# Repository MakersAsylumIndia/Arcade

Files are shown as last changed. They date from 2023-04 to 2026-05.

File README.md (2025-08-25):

# Arcade
A mini Arcade designed around two custom PCBs - the main board has the Arduino Nano, 128x64 I2C OLED display, and socket headers for digital, analog and PWM GPIO's. 

- The /enclosure folder has 3D FreeCAD model files.
- The /hardware_PCB folders contain schematic, PCB and related files.
- The /code folder has the Arduino code sketches.

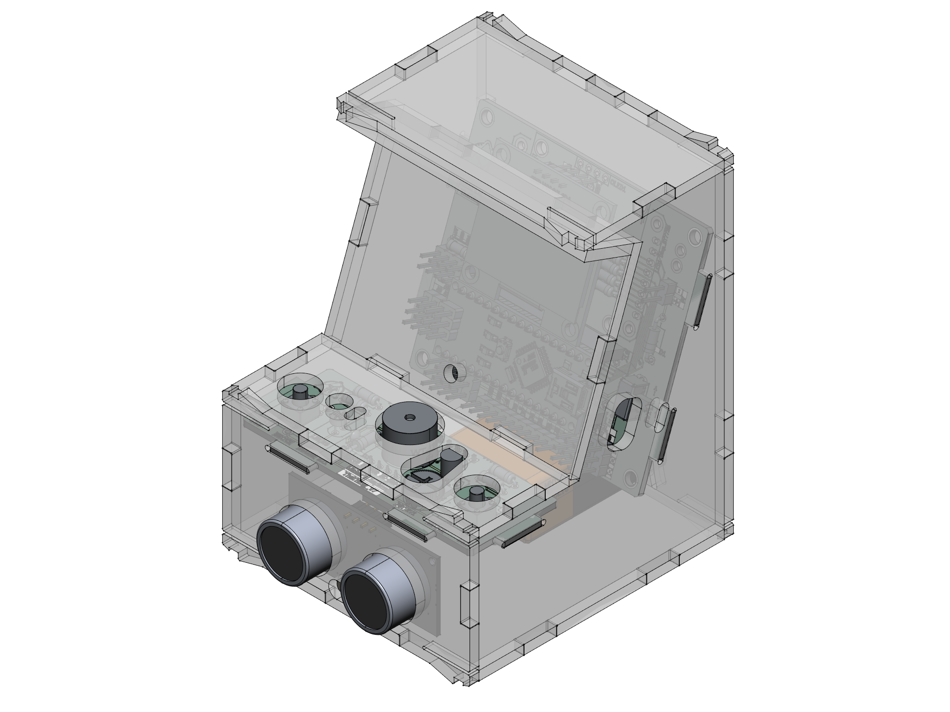
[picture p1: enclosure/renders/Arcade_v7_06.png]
Arcade_01

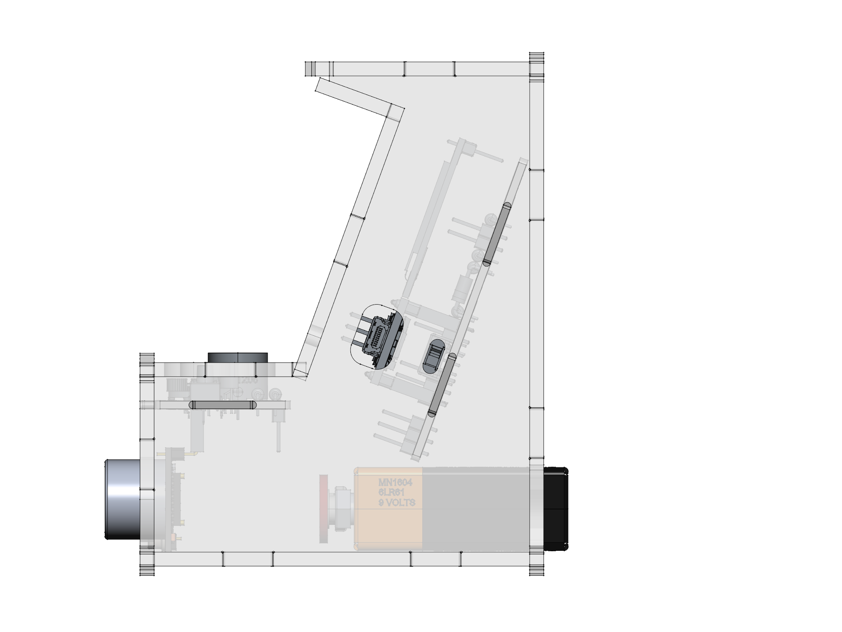
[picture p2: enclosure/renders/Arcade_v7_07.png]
Arcade_02

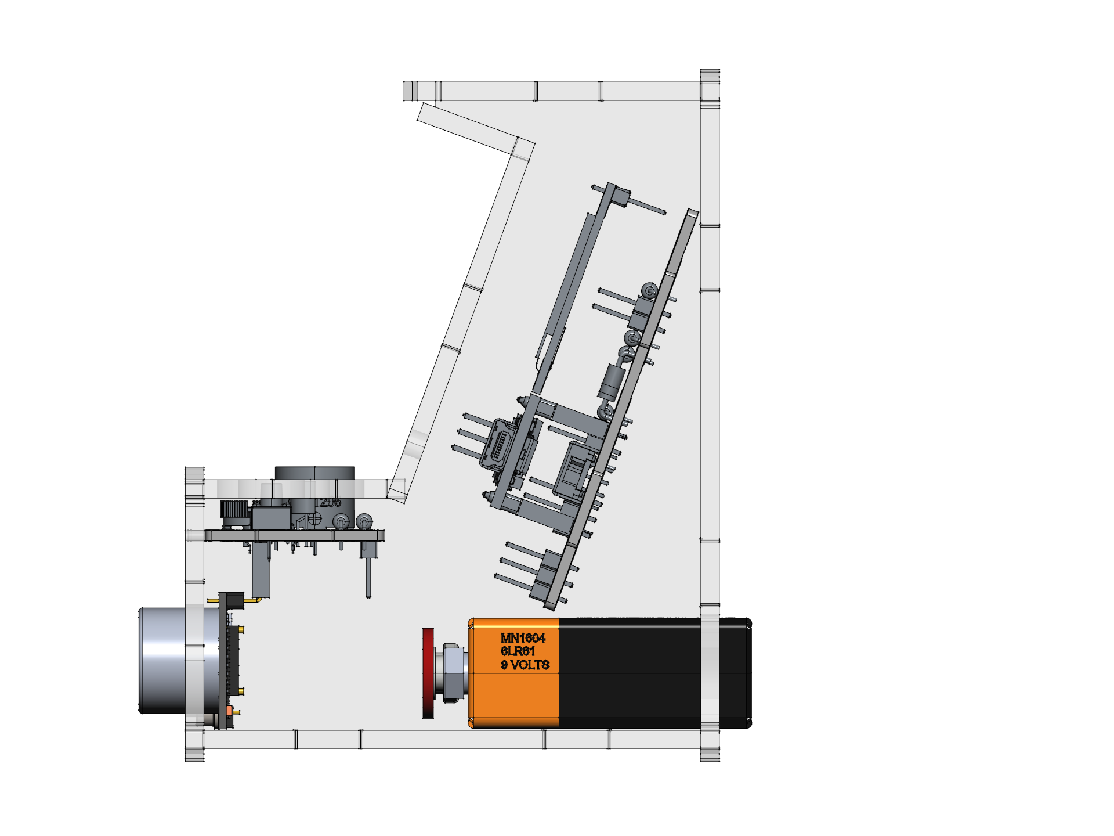
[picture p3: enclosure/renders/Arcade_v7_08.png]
Arcade_03


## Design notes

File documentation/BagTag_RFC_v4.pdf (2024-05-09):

# “Bag Tag” v4 Electronics

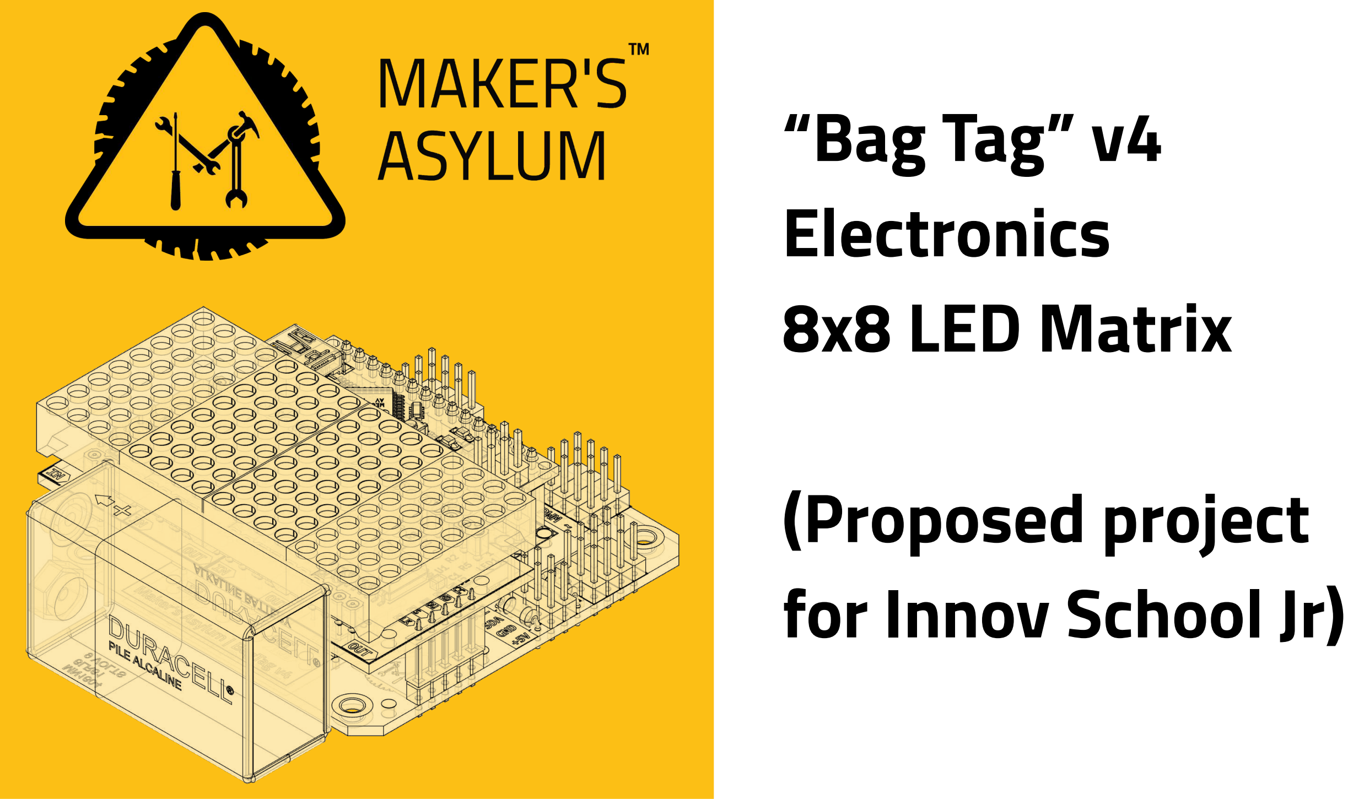
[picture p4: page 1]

# 8x8 LED Matrix

# (Proposed project for Innov School Jr)

# Requirements

- Complexity level - SIMPLE
- Must include elements of
- Electronics (soldering)
- Arduino (programming)
- Rapid prototyping (3DP/laser)
- BADGE form factor
- Powered by 9V battery
- Expandable / Hackable

Changes in v4 (v/s v1, v2 & v3)

- All parts on FRONT, but battery on side
- Two I²C expansion headers
- Can install one or two 8x8 SINGLE color LED

display based on MAX7219 chip

- Parts aligned along vertical axis for balance
- 3 expansion headers, each with 4 of Digital,

PWM & Analog I/’s with +5V and GND

- Larger PCB size

# Schematic

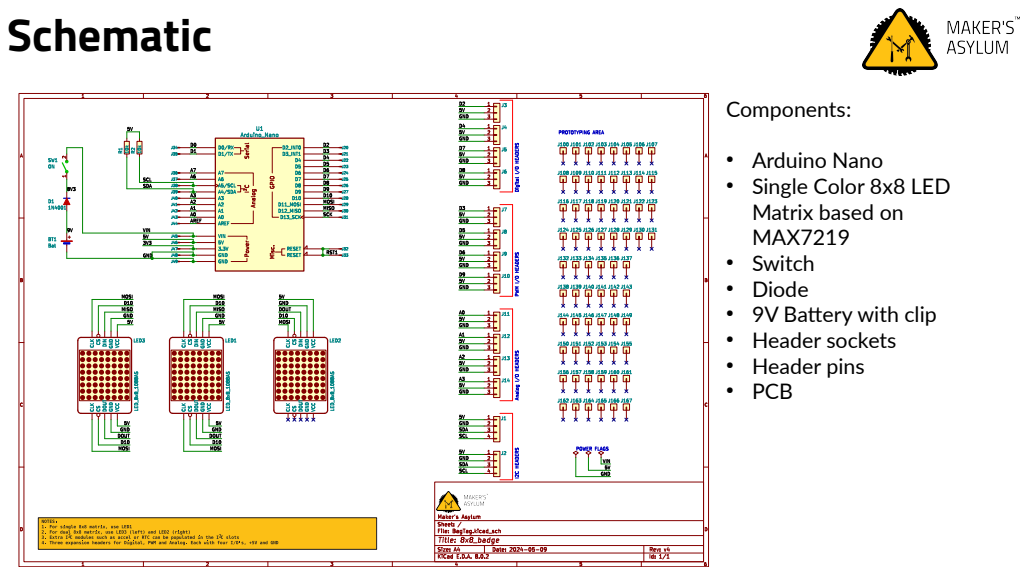
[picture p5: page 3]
Components: ●; Arduino Nano ●; Single Color 8x8 LED; Switch ●; Diode ●; 9V Battery with clip ●; Header sockets ●; Header pins ●; PCB

Matrix based on
MAX7219

# Options

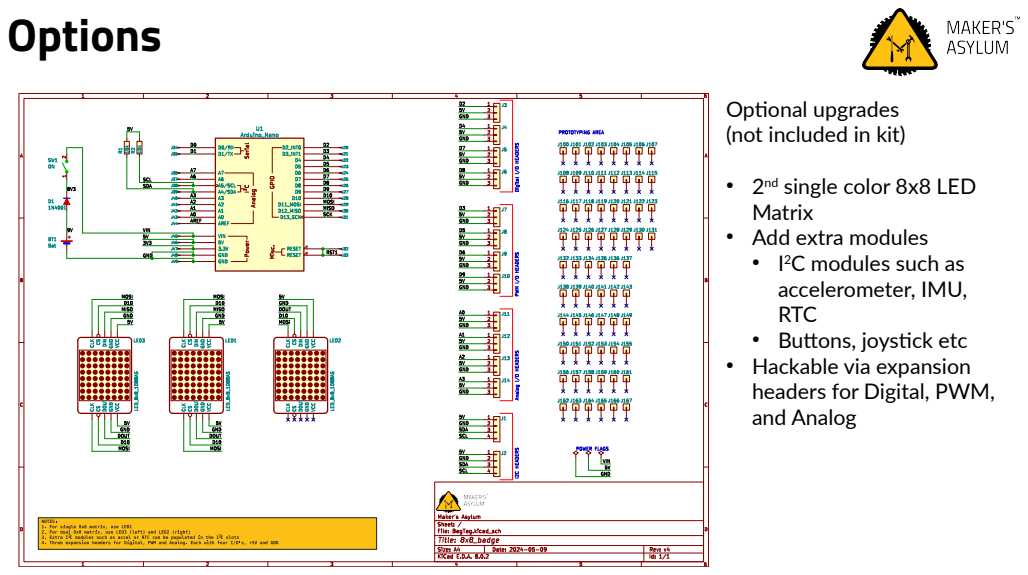
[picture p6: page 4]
Optional upgrades; (not included in kit) ●; Add extra modules ●; I²C modules such as

nd single color 8x8 LED
Matrix

accelerometer, IMU,
RTC
● Buttons, joystick etc
● Hackable via expansion
headers for Digital, PWM,
and Analog

# PCB Render

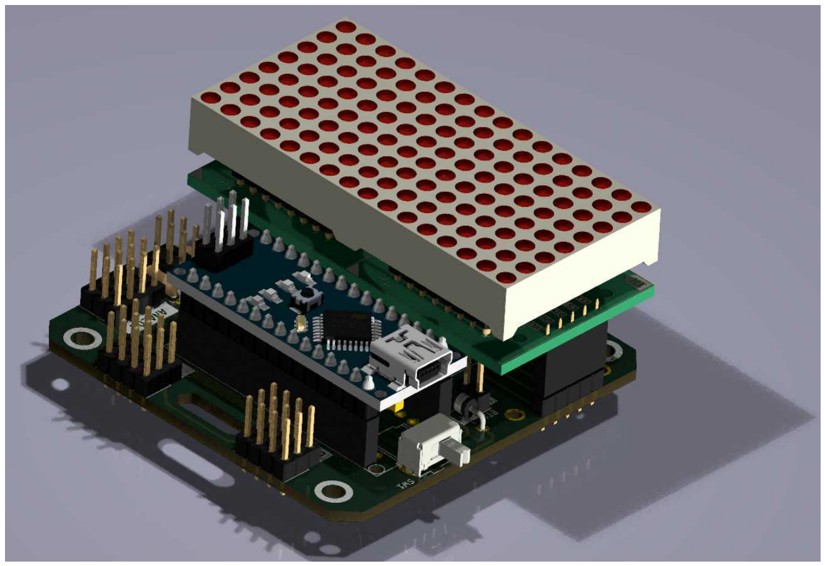
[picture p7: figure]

# PCB Front view

Lanyard slot

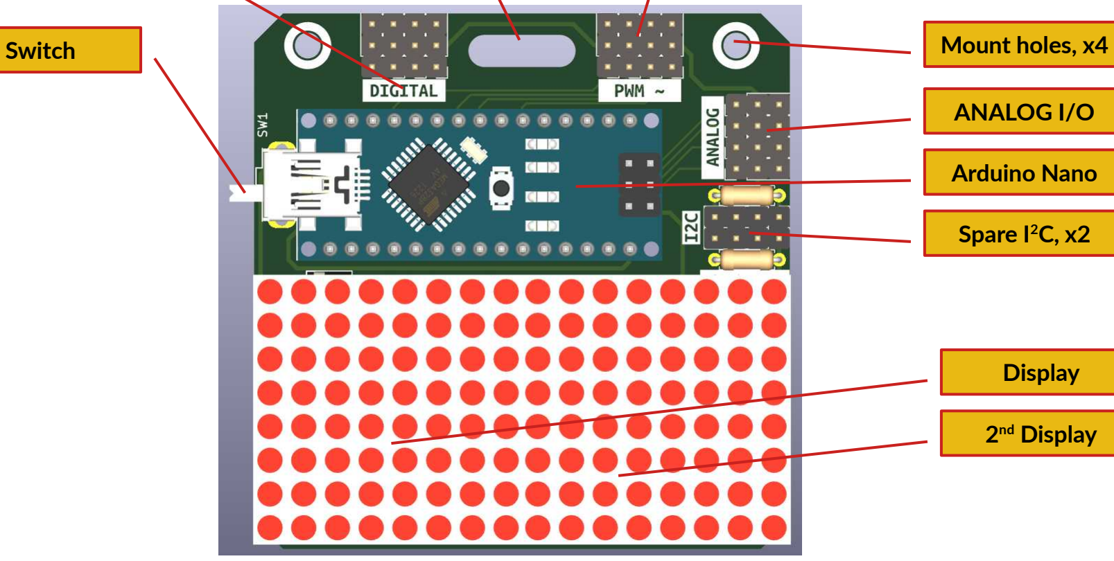
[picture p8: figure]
Switch; Mount holes, x4; Spare I²C, x2; Arduino Nano; nd Display; ANALOG I/O

Display

PWM ~ I/O
DIGITAL I/O

# PCB dimensions

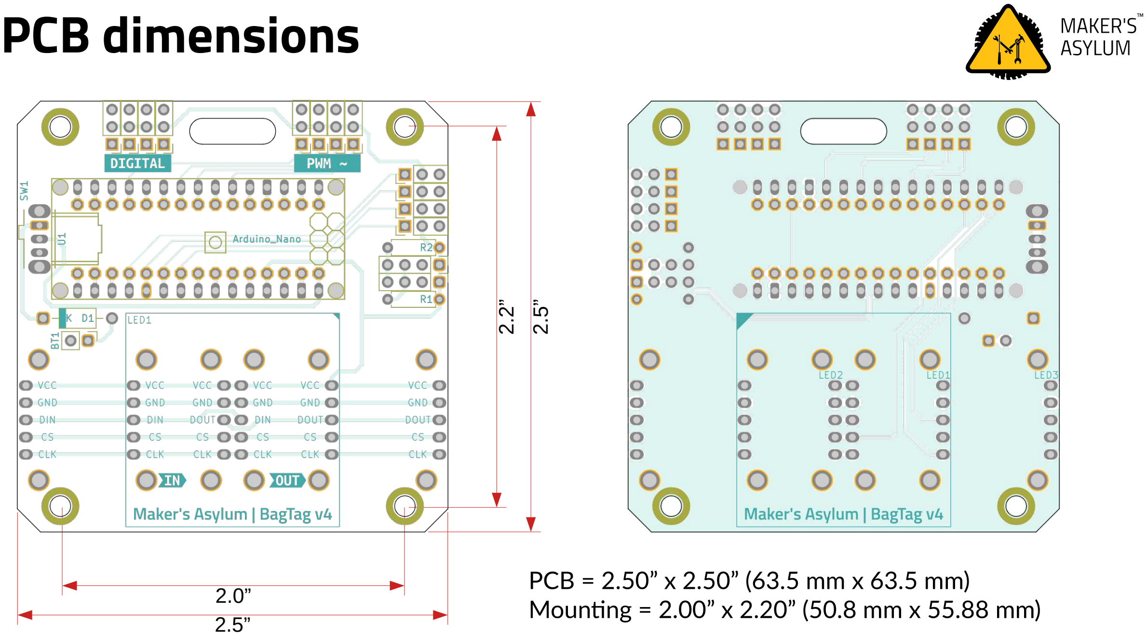
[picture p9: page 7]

PCB = 2.50” x 2.50” (63.5 mm x 63.5 mm) Mounting = 2.00” x 2.20” (50.8 mm x 55.88 mm) 2.5”

2.5”

2.0”

2.2”

# PCB Side views

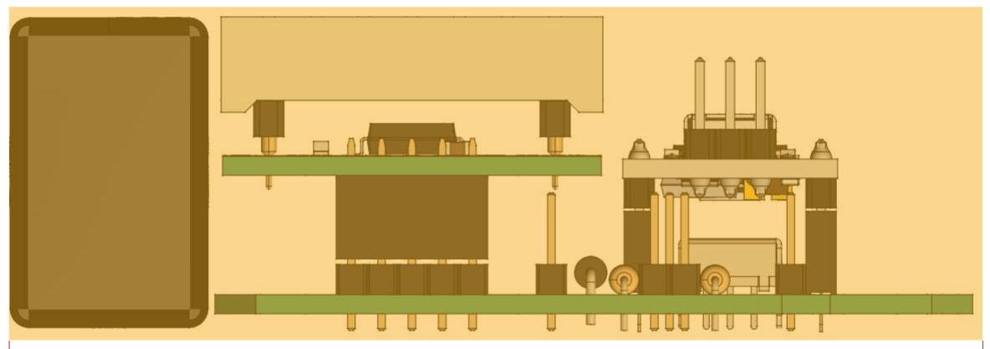
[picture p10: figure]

- Side views of the PCB.

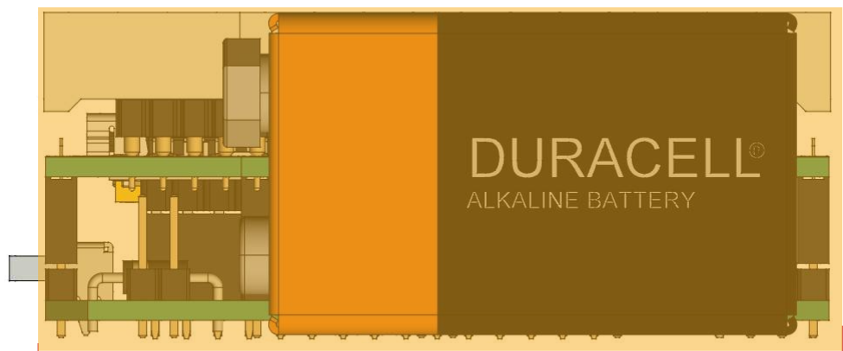
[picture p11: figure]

- 8x8 LED matrix display and Arduino Nano require header pins and sockets.
- BagTag will fit inside a volume of 82 mm x 65 mm x 28 mm
82 mm | 65 mm

2

8

m

m

# PCB Battery location

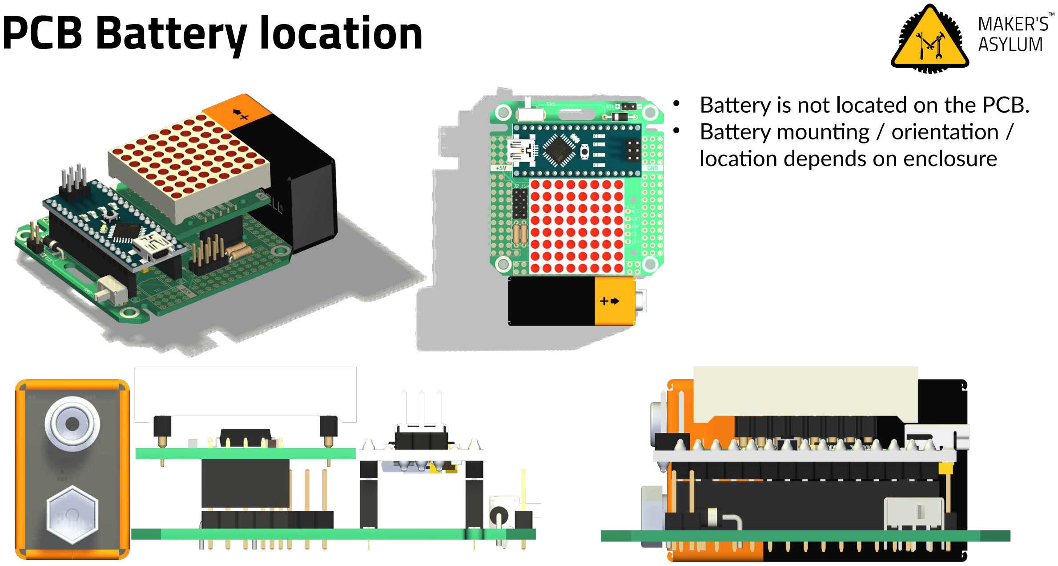
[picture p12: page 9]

- Battery is not located on the PCB.
- Battery mounting / orientation / location depends on enclosure

# Enclosure suggestion

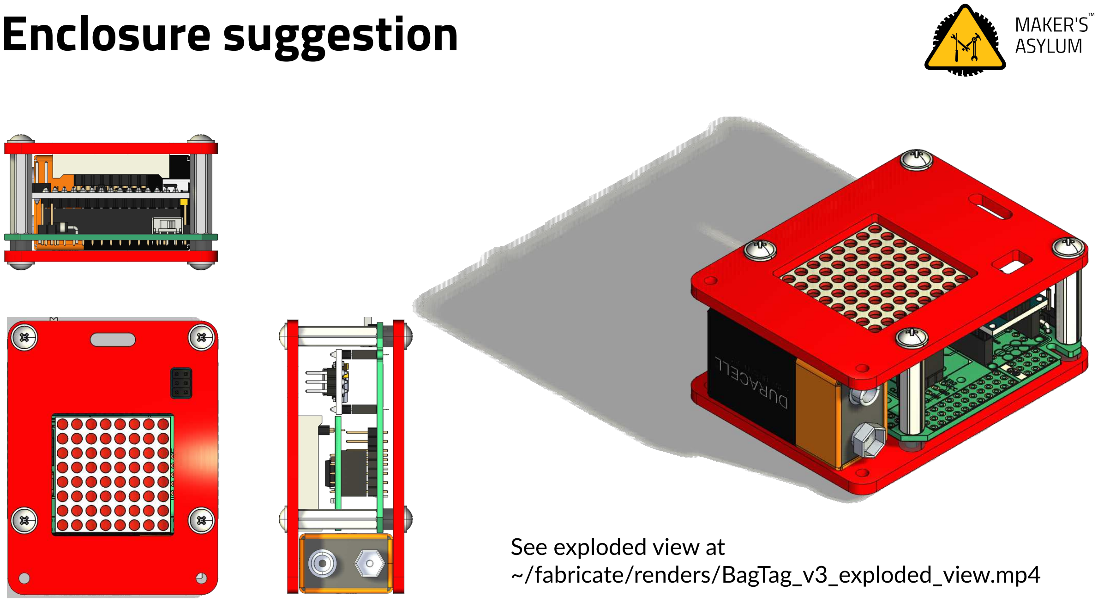
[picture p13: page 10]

See exploded view at
~/fabricate/renders/BagTag_v3_exploded_view.mp4

# Enclosure suggestions 2

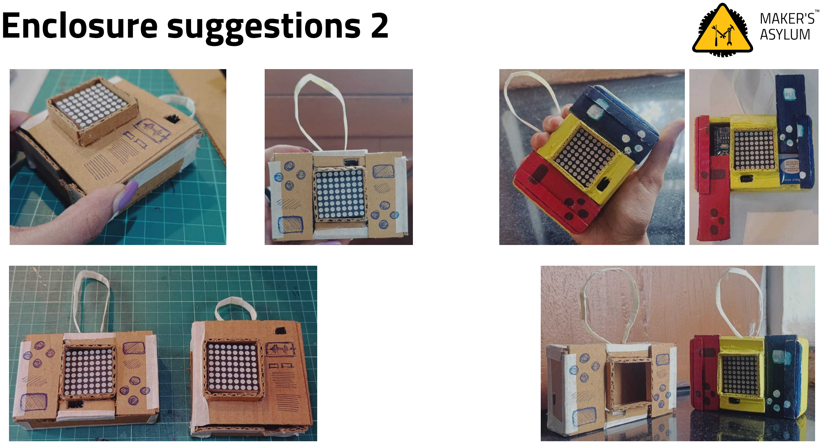
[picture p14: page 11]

# Hacking

- Two extra I²C headers and expansion headers for future hacking
- Add a second 8x8 LED matrix, I²C modules (accel, IMU, RTC), buttons etc.
- Some hacking ideas:
- Electronic Dice (using accelerometer for shake detection)
- Timer or Clock (using RTC)
- SNAKE game (using 5 buttons)
- PONG game using two joysticks
- Ornament or Wearable
- VU meter (sound decibel display, using microphone module)

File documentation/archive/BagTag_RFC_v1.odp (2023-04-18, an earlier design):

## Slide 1

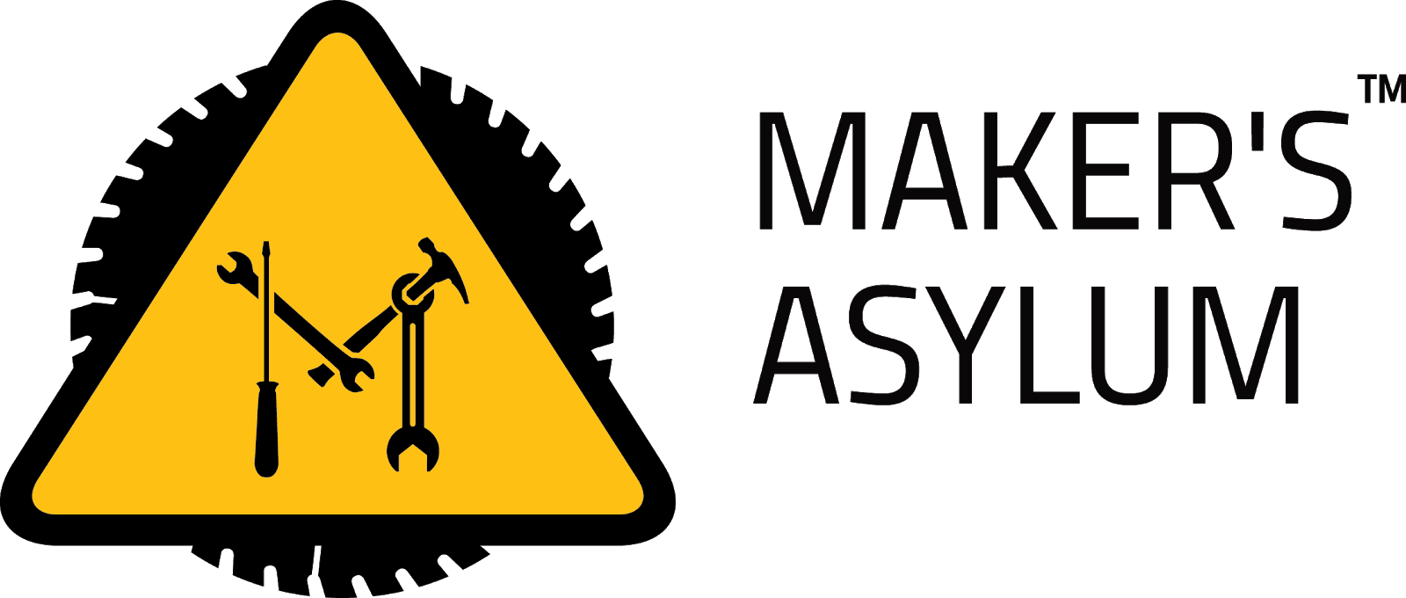
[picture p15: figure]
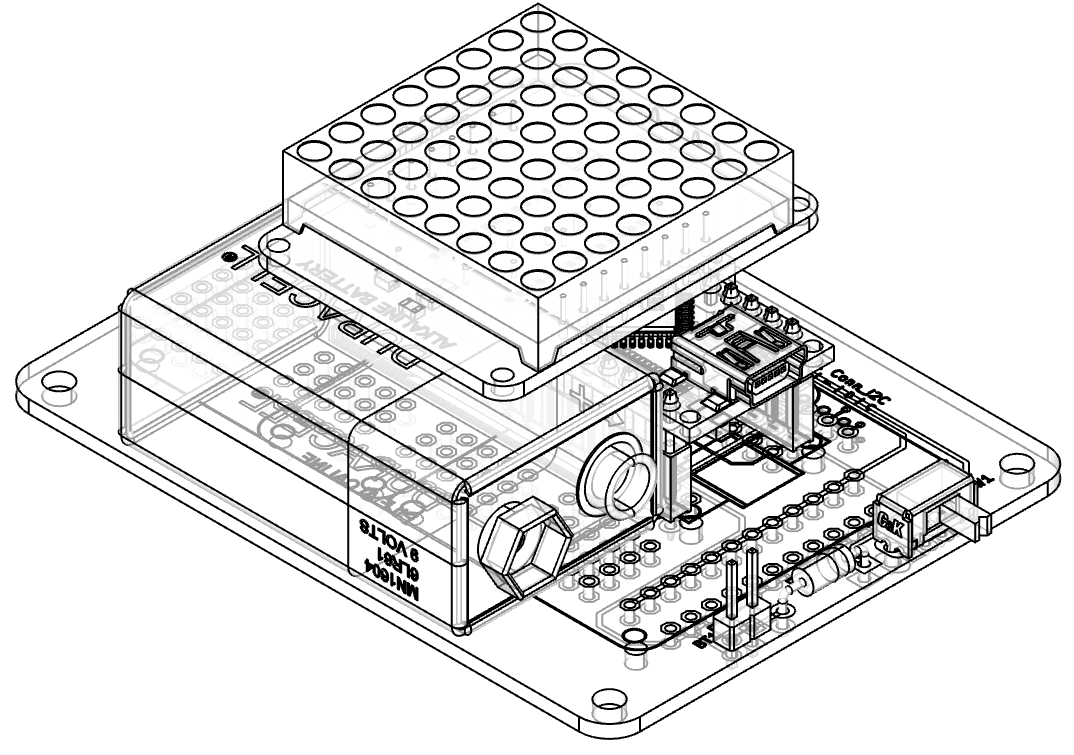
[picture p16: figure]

“Bag Tag” v1

Electronics

8x8 LED Matrix

(Proposed project for Innov School Jr)

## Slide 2

Requirements

- Complexity level - SIMPLE
- Must include elements of
  - Electronics (soldering)
  - Arduino (programming)
  - Rapid prototyping (3D printing / laser cutting)
- BADGE form factor
- Powered by 9V battery
- Expandable / Hackable

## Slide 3

Schematic

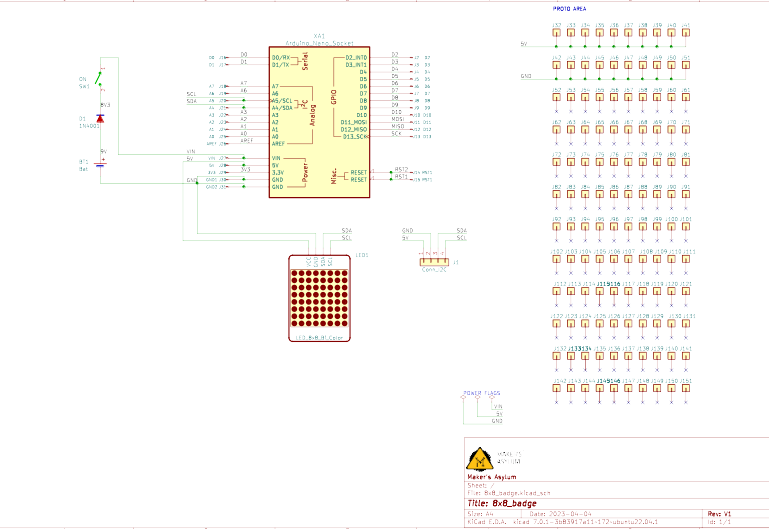
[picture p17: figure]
SVG Image created as 8x8_badge.svg date 2023/04/10 20:11:13 Image generated by Eeschema-SVG

Components:

- Arduino Nano
- Bi-Color 8x8 LED Matrix
- Switch
- Diode
- 9V Battery with clip
- Header sockets
- Header pins
- PCB

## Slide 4

Options

Optional upgrades

(not included in kit)

- 2nd Bi-Color 8x8 LED Matrix
- Add extra modules
  - I²C modules such as accelerometer, IMU, RTC
  - Buttons, joystick etc
- Hackable via prototyping area with 120 pads

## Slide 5

PCB Render

Lanyard slot

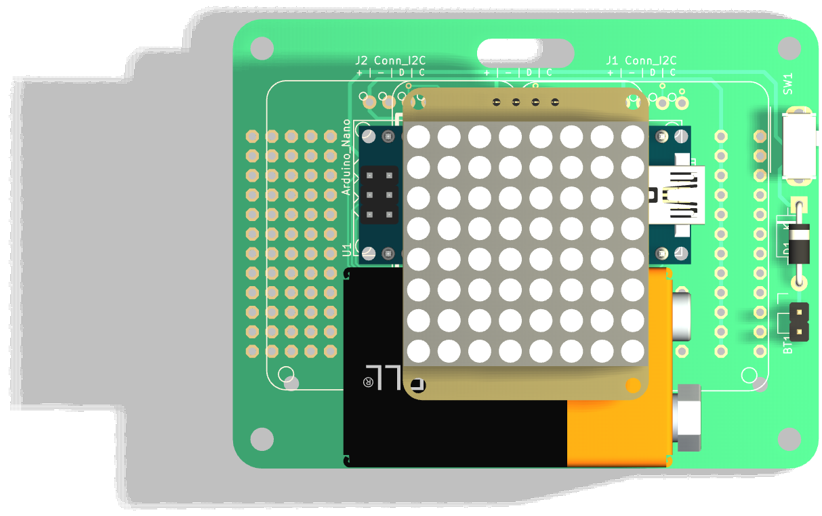
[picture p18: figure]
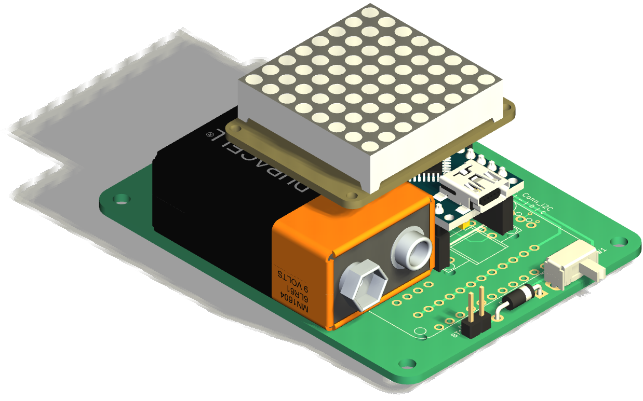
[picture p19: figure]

Spare I²C

Display

Proto area

Mount hole

Switch

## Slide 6

PCB Front / Bottom view

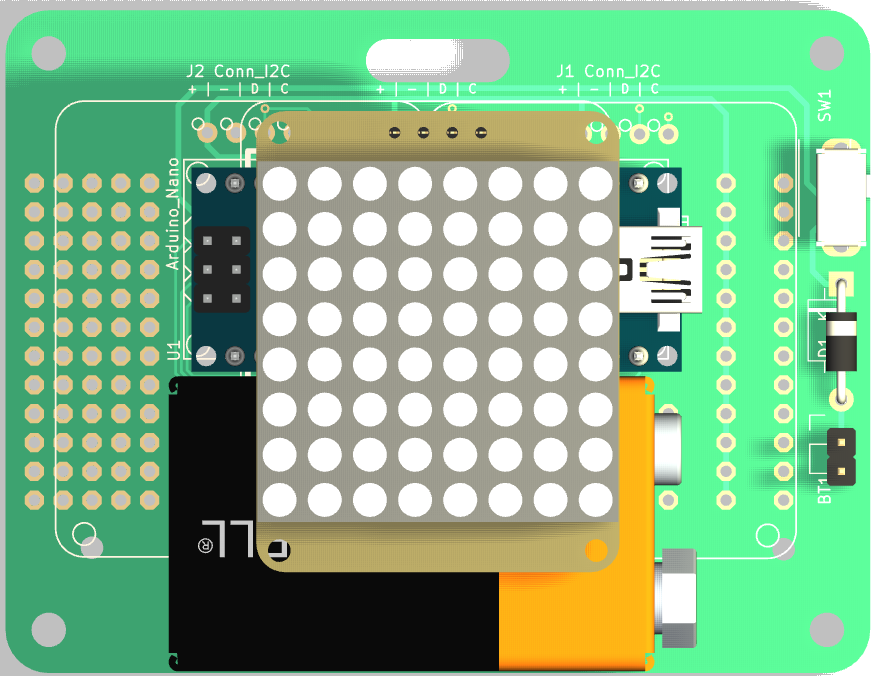
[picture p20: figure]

- Front side of BAG TAG has ONE 8x8 LED matrix.
- The second LED matrix is optional (future hacking)
- There are 120 pads for prototyping

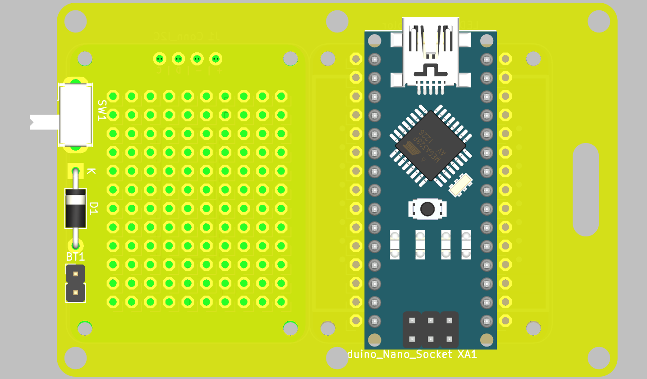
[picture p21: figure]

- Bottom side of BAG TAG has Arduino Nano, slide switch, reverse polarity protection diode, and 2 pin header for battery connection.
- The blank part of the PCB can be used to stick the 9V battery using adhesive tape.

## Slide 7

3” (76.2 mm)

2 “ (50.8 mm)

PCB dimensions

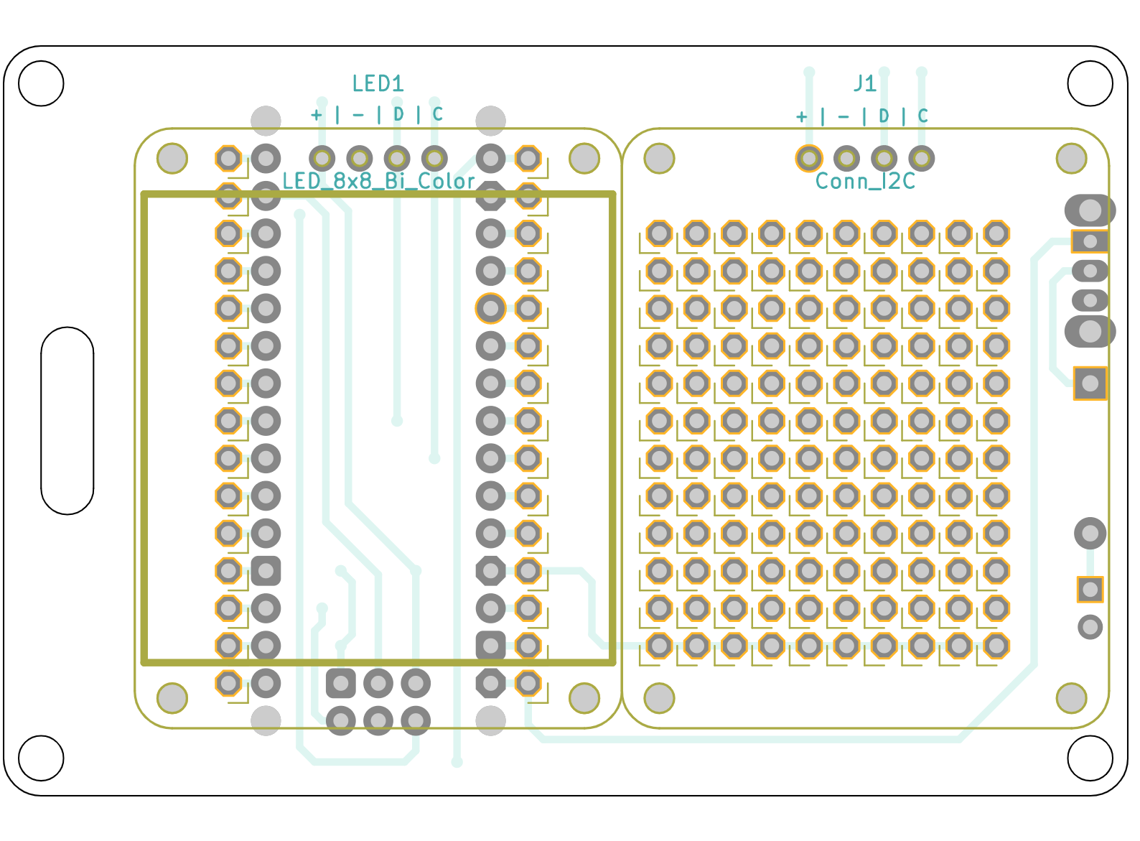
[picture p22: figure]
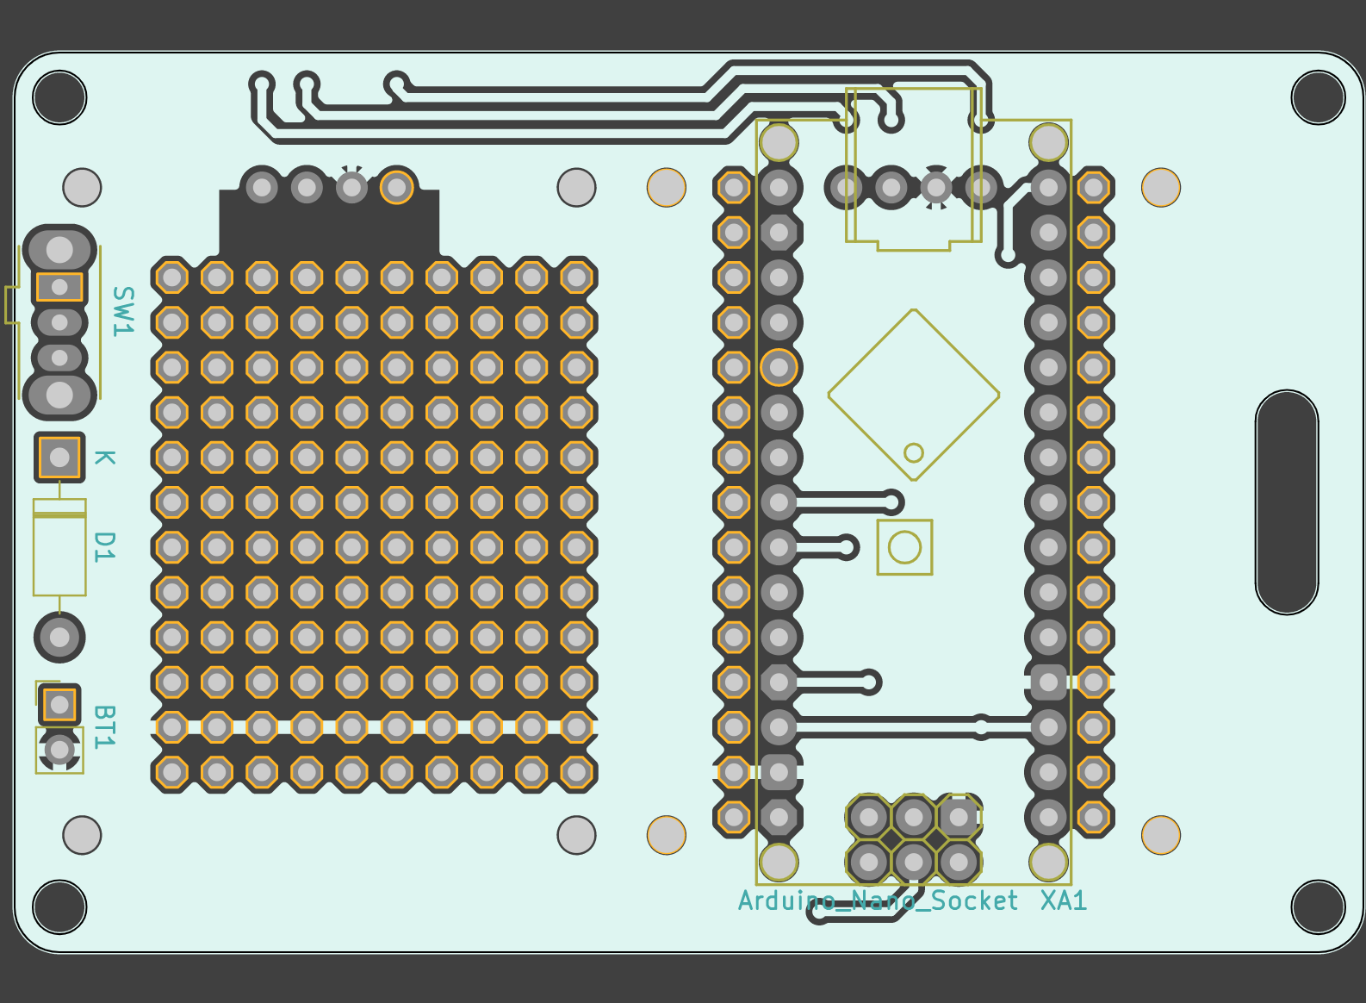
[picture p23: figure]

Size is smaller than credit card

3 inches x 2 inches

(76.2 mm x 50.8 mm)

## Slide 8

1.6” (40.64 mm)

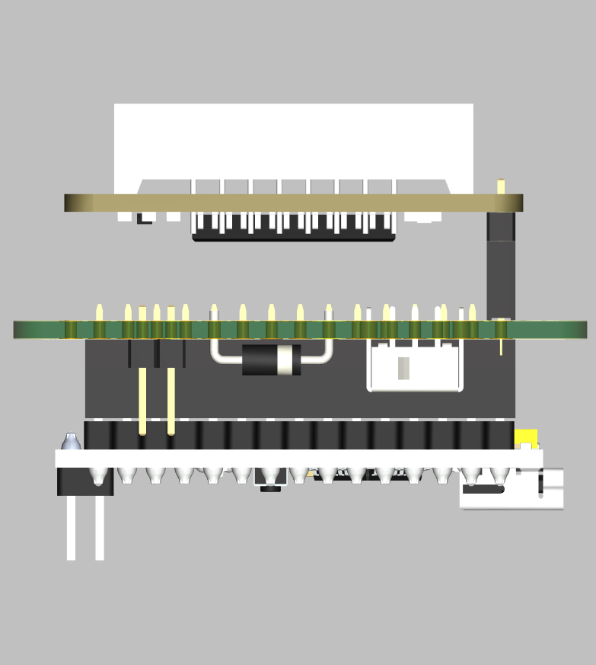
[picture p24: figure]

PCB Side view

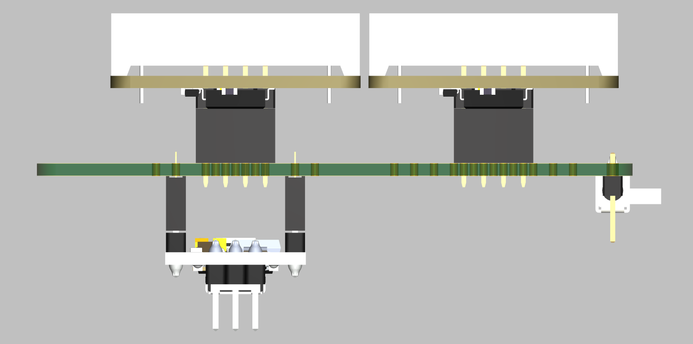
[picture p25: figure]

- Side views of the PCB.
- Arduino Nano and 8x8 matrix display are mounted using header sockets and header pins.
- Some support will be needed under the LED matrix
- Height is 1.6” (41mm). This can be reduced if header sockets are not used and Arduino+LED matrix are directly soldered.

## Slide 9

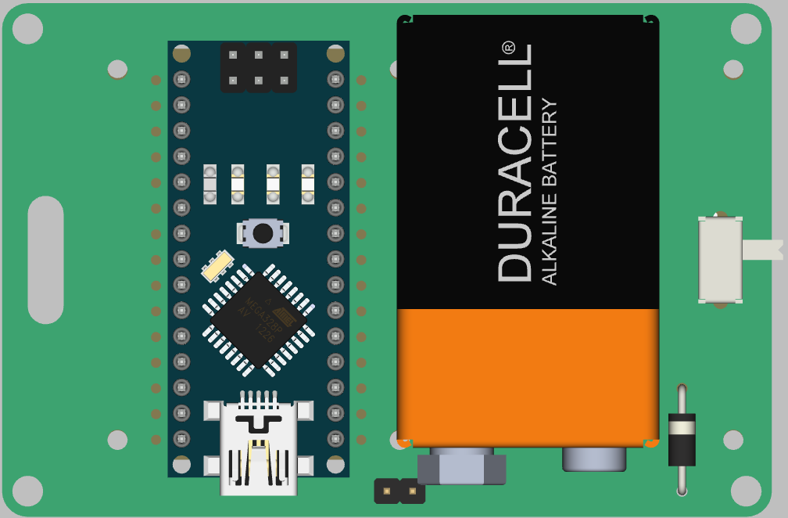
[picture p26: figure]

PCB Battery location

Location of 9V battery

(attached using double sided tape)

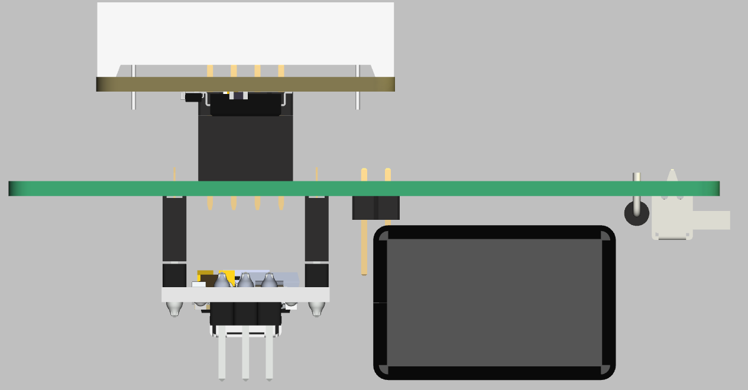
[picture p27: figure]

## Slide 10

Hacking

- Extra I²C header and 120 copper pads for future hacking
- Add a second 8x8 LED matrix, I²C modules (accel, IMU, RTC), buttons etc.
- Some hacking ideas:
  - Electronic Dice (using accelerometer for shake detection)
  - Timer or Clock (using RTC)
  - SNAKE game (using 5 buttons)
  - PONG game using two joysticks
  - Ornament or Wearable
  - VU meter (sound decibel display, using microphone module)

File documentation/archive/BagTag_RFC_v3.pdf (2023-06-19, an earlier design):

# “Bag Tag” v3 Electronics


# 8x8 LED Matrix

# (Proposed project for Innov School Jr)

# Requirements

## - Complexity level - SIMPLE

- Must include elements of
- Electronics (soldering)
- Arduino (programming)
- Rapid prototyping (3DP/laser)

## - BADGE form factor

- Powered by 9V battery
- Expandable / Hackable

## Changes in v3 (v/s v1 & v2)

- All parts on FRONT, but battery on side
- Two I²C expansion headers
- Can install one or two 8x8 SINGLE color

## LED display based on MAX7219 chip

- Parts aligned along vertical axis for

balance

- 100 prototyping pads and 12 each for

## +5V and GND

# Schematic

Components: ●; Arduino Nano ●; Single Color 8x8 LED; Switch ●; Diode ●; 9V Battery with clip ●; Header sockets ●; Header pins ●; PCB

Matrix based on
MAX7219

# Options

Optional upgrades; (not included in kit) ●; Add extra modules ●; I²C modules such as; accelerometer, IMU,; RTC

nd single color 8x8 LED
Matrix

● Buttons, joystick etc

● Hackable via prototyping

area with 100 pads+ 24

power rail pads

# PCB Render


# PCB Front view


Lanyard slot

Display

Proto area

Mount holes, x4

Switch

Spare I²C, x2

Arduino Nano

2

nd Display

Battery, 9V

# PCB dimensions


PCB = 2.30” x 2.30” (58.4 mm x 58.4 mm) Mounting = 2.00” x 2.00” (50.8 mm x 50.8 mm) 2.3”

2.3”

2.0”

2.0”

# PCB Side views


- Side views of the PCB.
- 8x8 LED matrix display and Arduino Nano require header pins and sockets.
- BagTag will fit inside a volume of 76 mm x 60 mm x 28 mm
76 mm | 60 mm

2

8

m

m

# PCB Battery location


- Battery is not located on the PCB.
- Battery mounting / orientation /

location depends on enclosure

# Enclosure suggestion


See exploded view at

~/fabricate/renders/BagTag_v3_exploded_view.mp4

# Enclosure suggestions 2


# Hacking

- Two extra I²C headers and 100 copper pads for future hacking
- Add a second 8x8 LED matrix, I²C modules (accel, IMU, RTC), buttons etc.
- Some hacking ideas:
- Electronic Dice (using accelerometer for shake detection)
- Timer or Clock (using RTC)
- SNAKE game (using 5 buttons)
- PONG game using two joysticks
- Ornament or Wearable
- VU meter (sound decibel display, using microphone module)

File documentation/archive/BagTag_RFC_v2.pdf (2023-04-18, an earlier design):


# “Bag Tag” v2 Electronics 8x8 LED Matrix

# (Proposed project for Innov School Jr)

# Requirements

## - Complexity level - SIMPLE

## - Must include elements of

## - Electronics (soldering)

## - Arduino (programming)

## - Rapid prototyping (3DP/laser)

## - BADGE form factor

## - Powered by 9V battery

## - Expandable / Hackable

## Changes in v2 (v/s v1)

## - All parts on FRONT side of PCB

## - Three I²C headers

## - Can install one or two 8x8 LED display

## - Parts aligned along vertical axis for

## balance

## - Extra 24 prototyping pads (12 each for

## +5V and GND)

# Schematic

Components: ●; Arduino Nano ●; Bi-Color 8x8 LED Matrix ●; Switch ●; Diode ●; 9V Battery with clip ●; Header sockets ●; Header pins ●; PCB

# Options

Optional upgrades; (not included in kit) ●; Add extra modules ●; I²C modules such as

nd Bi-Color 8x8 LED
Matrix

accelerometer, IMU,
RTC
● Buttons, joystick etc
● Hackable via prototyping
area with 120 pads+ 24
power rail pads

# PCB Render


Lanyard slot

Display

Proto area

Mount holes, x4 | Switch

Spare I²C, x2

# PCB Front view


- All components are assembled on Front side.
- Components are aligned along vertical axis for weight
distribution
- There are 120 pads for
prototyping + 24 power pads (12 each connected to +5V and GND)
- There are 3 I

2C headers. For
single display, use the center one. For dual display, use the I

2C
left/right headers.
- The blank part of the PCB can be used to stick the 9V battery using adhesive tape.

# PCB dimensions


3 inches x 2.3 inches
(76.2 mm x 58.4 mm)

3” (76.2 mm)

2.3

“ (5

8.4

m

m)

# PCB Side view


- Side views of the PCB.
- 8x8 LED matrix display requires extra long header pins, or one pair of sockets and regular header pins.
- Some support will be needed under the LED matrix.
- Height is 1.3” (33mm). This can be reduced if header sockets are not used and Arduino+LED matrix are directly soldered.

1.3” (3

3

m

m)

# PCB Battery location


Location of 9V battery
(attached using double sided tape)

# Hacking

## - Extra I²C header and 120 copper pads for future hacking

- Add a second 8x8 LED matrix, I²C modules (accel, IMU, RTC), buttons etc.

## - Some hacking ideas:

## - Electronic Dice (using accelerometer for shake detection)

## - Timer or Clock (using RTC)

## - SNAKE game (using 5 buttons)

## - PONG game using two joysticks

## - Ornament or Wearable

## - VU meter (sound decibel display, using microphone module)

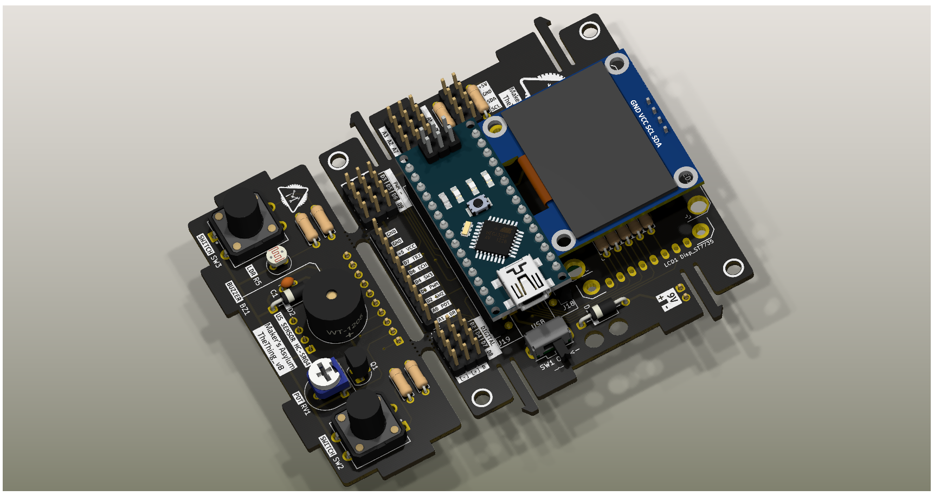
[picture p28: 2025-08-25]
hardware_PCB/TheThing_v8/images/TheThing_pcb_05.png

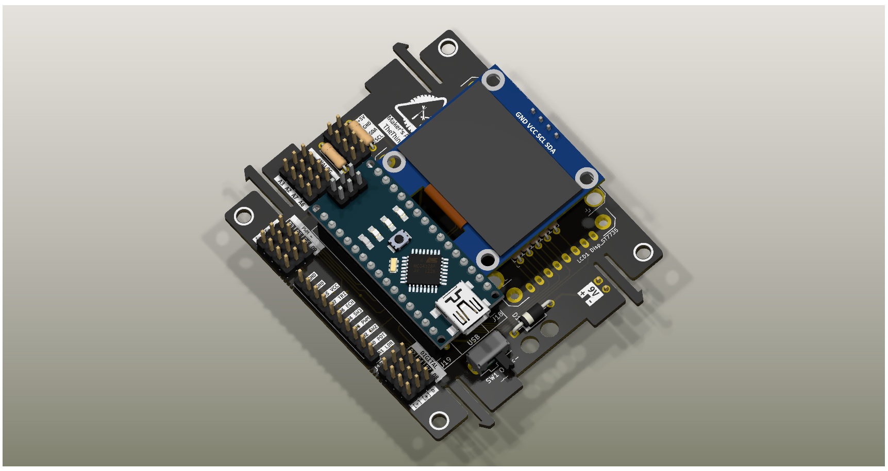
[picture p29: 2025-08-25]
hardware_PCB/TheThing_v8/images/TheThing_pcb_08.png

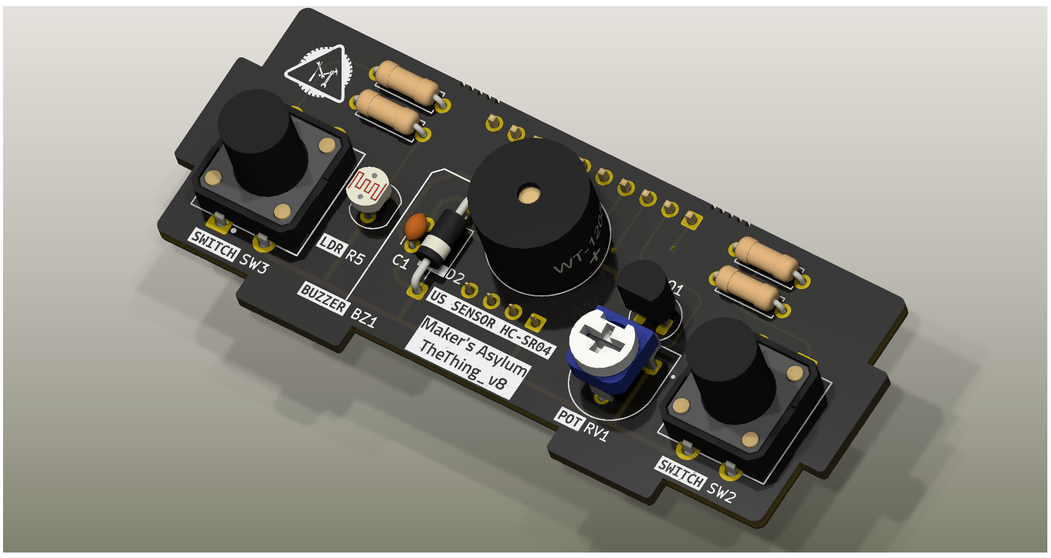
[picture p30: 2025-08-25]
hardware_PCB/TheThing_v8/images/TheThing_pcb_11.png

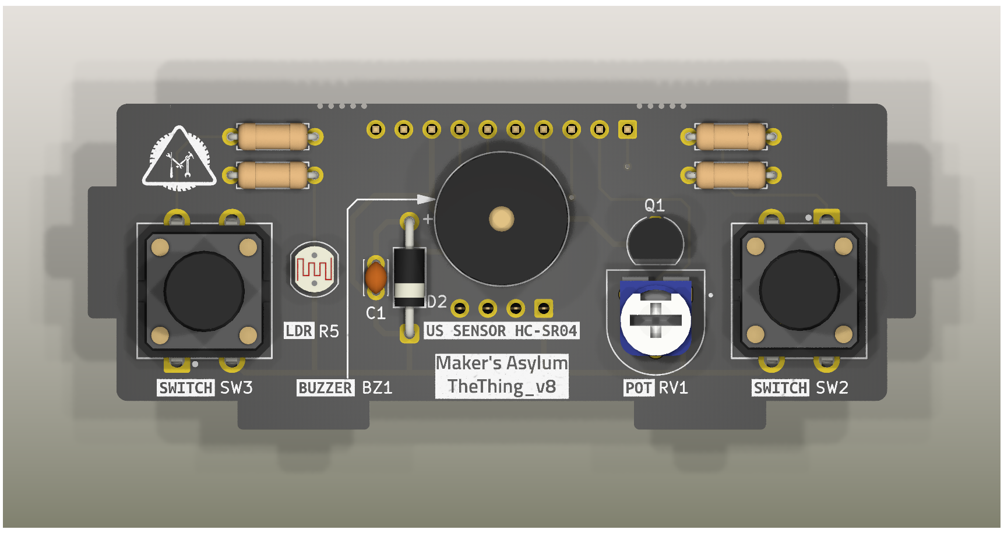
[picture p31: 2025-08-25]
hardware_PCB/TheThing_v8/images/TheThing_pcb_09.png

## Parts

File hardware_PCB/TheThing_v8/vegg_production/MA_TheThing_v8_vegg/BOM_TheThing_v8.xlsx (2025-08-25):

BOM (Bill of Materials) Maker’s Asylum TheThing_v8
Sr No | Designation | Quantity | Manufacturer | Manufacturer Part Number | Description | Footprint | Type | Remarks | Datasheet | Digikey Link
1 | BT1 | 1 | Adam Tech | PH1RB-02-UA | Connector Header Through Hole, Right Angle 2 position 0.100" (2.54mm) | 1x02_P2.54mm right angle | thru-hole | Male header, right angle, 2 pin | https://app.adam-tech.com/products/download/data_sheet/201281/ph1rb-xx-ua-data-sheet.pdf | https://www.digikey.com/en/products/detail/adam-tech/PH1RB-02-UA/9830333
2 | BZ1 | 1 | Soberton Inc. | WT-1205 | Buzzers Transducer, Externally Driven Magnetic 5 V 50mA 2.4kHz 87dB @ 5V, 10cm Through Hole PC Pins | Dia 12 mmx 6.5mm pitch | thru-hole | Buzzer_12x9.5RM7.6, PS1240P02BT | https://www.soberton.com/wp-content/uploads/2019/02/WT-1205-16-Feb-2019.pdf | https://www.digikey.com/en/products/detail/soberton-inc/WT-1205/479674
3 | C1 | 1 | Vishay Beyschlag/Draloric/BC Components | K104K15X7RF5TL2 | CAP CER 0.1uF 50V X7R RADIAL | Dia 3.0mm, pitch 2.50mm | thru-hole |  | https://www.vishay.com/docs/45171/kseries.pdf | https://www.digikey.com/en/products/detail/vishay-beyschlag-draloric-bc-components/K104K15X7RF5TL2/286538
4 | D1 | 1 | Diotec Semiconductor | 1N4001 | Diode 50 V 1A Through Hole DO-204AC (DO-41) | DO-41, pitch 10.16 mm | thru-hole |  | https://diotec.com/request/datasheet/1n4001.pdf | https://www.digikey.com/en/products/detail/diotec-semiconductor/1N4001/13164614
5 | D2 | 1 | Micro Commercial Co | 1N5819-TP | Diode 40 V 1A Through Hole DO-41 | DO-41, pitch 10.16 mm | thru-hole |  | https://www.mccsemi.com/pdf/Products/1N5817-1N5819(DO-41).pdf | https://www.digikey.com/en/products/detail/micro-commercial-co/1N5819-TP/950396
6 | J1, J2 | 2 | Samtec Inc. | TSW-104-07-F-S | Connector Header Through Hole 4 position 0.100" (2.54mm) | 1x04_P2.54mm_Vertical | thru-hole | Male header, straight, 4 pin | https://mm.digikey.com/Volume0/opasdata/d220001/medias/docus/6129/tsw-xxx-xx-xxx-x-xx-xxx-mkt.pdf | https://www.digikey.com/en/products/detail/samtec-inc/TSW-104-07-F-S/2685892
7 | J10, J11, J12, J13, J14, J3, J4, J5, J6, J7, J8, J9 | 12 | Samtec Inc. | TSW-103-07-F-S | Connector Header Through Hole 3 position 0.100" (2.54mm) | 1x03_P2.54mm_Vertical | thru-hole | Male header, straight, 3 pin | https://mm.digikey.com/Volume0/opasdata/d220001/medias/docus/6129/tsw-xxx-xx-xxx-x-xx-xxx-mkt.pdf | https://www.digikey.com/en/products/detail/samtec-inc/TSW-103-07-F-S/2685877
8 | J15 | 1 | Samtec Inc. | BCS-104-F-S-TE | 4 Position Receptacle Connector 0.100" (2.54mm) Through Hole Gold | 1x04_P2.54mm_Vertical | thru-hole | Female header, straight, 4 pin | https://mm.digikey.com/Volume0/opasdata/d220001/medias/docus/6209/bcs-1xx-xxx-x-xx-xxx-mkt.pdf | https://www.digikey.com/en/products/detail/samtec-inc/BCS-104-F-S-TE/6628852
9 | J16, J17 | 2 | Samtec Inc. | TSW-110-07-L-S-LL | Connector Header Through Hole 10 position 0.100" (2.54mm) | 1x10_P2.54mm_Vertical | thru-hole | Male header, straight, 10 pin | https://mm.digikey.com/Volume0/opasdata/d220001/medias/docus/6129/tsw-xxx-xx-xxx-x-xx-xxx-mkt.pdf | https://www.digikey.com/en/products/detail/samtec-inc/TSW-110-07-L-S-LL/7871155
10 | OLED1 | 1 | Samtec Inc. | BCS-104-F-S-TE | 4 Position Receptacle Connector 0.100" (2.54mm) Through Hole Gold | 1x04_P2.54mm_Vertical | thru-hole | Female header, straight, 4 pin | https://mm.digikey.com/Volume0/opasdata/d220001/medias/docus/6209/bcs-1xx-xxx-x-xx-xxx-mkt.pdf | https://www.digikey.com/en/products/detail/samtec-inc/BCS-104-F-S-TE/6628852
11 | Q1 | 1 | On Semi | BC547B | Bipolar (BJT) Transistor NPN 45V 0.1A 300MHz 625 mW Through Hole TO-92-3 | TO-92-3 | thru-hole | BC547 | https://www.mouser.com/datasheet/2/149/BC547-190204.pdf | https://www.digikey.in/en/products/detail/onsemi/BC547/976363
12 | R1, R10, R11, R12, R2, R3, R4, R6, R8, R9 | 10 | Stackpole Electronics Inc | RNF18FTD10K0 | 10 kOhms ±1% 0.125W, 1/8W Through Hole Resistor Axial | 0.071" Dia x 0.130" L (1.80mm x 3.30mm) | thru-hole |  | https://www.seielect.com/catalog/sei-rnf_rnmf.pdf | https://www.digikey.com/en/products/detail/stackpole-electronics-inc/RNF18FTD10K0/1682757
13 | R13, R14, R15, R16, R17 | 5 | Stackpole Electronics Inc | RNF18FTD20K0 | 20 kOhms ±1% 0.125W, 1/8W Through Hole Resistor Axial | 0.071" Dia x 0.130" L (1.80mm x 3.30mm) | thru-hole |  | https://www.seielect.com/catalog/sei-rnf_rnmf.pdf | https://www.digikey.in/en/products/detail/stackpole-electronics-inc/RNF18FTD20K0/1682824
14 | R5 | 1 | Advanced Photonix | PDV-P8103 | LDR, CdS Cells 520nm 16 ~ 33kOhms @ 10 lux | LDR, 4.9x4.2mm, pitch 2.54mm | thru-hole | Solder with gap of at least 8-10 mm from PCB surface | https://www.advancedphotonix.com/wp-content/uploads/2015/07/DS-PDV-P8103.pdf | https://www.digikey.com/en/products/detail/advanced-photonix/PDV-P8103/480610
15 | R7 | 1 | Stackpole Electronics Inc | RNF18FTD100R | 100 Ohms ±1% 0.125W, 1/8W Through Hole Resistor Axial | 0.071" Dia x 0.130" L (1.80mm x 3.30mm) | thru-hole |  | https://www.seielect.com/catalog/sei-rnf_rnmf.pdf | https://www.digikey.com/en/products/detail/stackpole-electronics-inc/RNF18FTD100R/1682751
16 | RV1 | 1 | KYOCERA AVX | 601040 | 100 kOhms 0.1W, 1/10W PC Pins Through Hole Trimmer Potentiometer Carbon 1.0 Turn Top Adjustment | Square - 0.256" x 0.256" Face (6.50mm x 6.50mm) | thru-hole | PCB mounting, single turn, trimpot - with KNOB preferred like this : https://mm.digikey.com/Volume0/opasdata/d220001/medias/docus/2314/COM-09806_Web.pdf | https://isc.kyocera-avx.de/wp-content/uploads/Carbon_Preset_E_HA06-1.pdf | https://www.digikey.com/en/products/detail/kyocera-avx/601040/10491370
17 | SW1 | 1 | Same Sky (Formerly CUI Devices) | SLW-864587-2A-RA-N-D | Slide Switch SPDT Through Hole, Right Angle | 8.6 X 4.5 X 8.7 MM, 2 MM RAISED | thru-hole |  | https://www.cuidevices.com/product/resource/slw-864587-2a-ra-n-d.pdf | https://www.digikey.com/en/products/detail/same-sky-formerly-cui-devices/SLW-864587-2A-RA-N-D/24399384
18 | SW2, SW3 | 2 | Same Sky (Formerly CUI Devices) | TS14-1212-80-BK-100-SCR-D | Tactile Switch SPST-NO Top Actuated Through Hole | 12mm x 12mm | thru-hole | Push button switch, 12x12 mm, button = 8mm minimum, 12mm maximum | https://www.cuidevices.com/product/resource/ts14.pdf | https://www.digikey.com/en/products/detail/same-sky-formerly-cui-devices/TS14-1212-80-BK-100-SCR-D/16562723
19 | J18, J19 | 2 | Harwin Inc. | M20-7821546 | 15 Position Receptacle Connector 0.100" (2.54mm) Through Hole Tin | 1x15_P2.54mm_Vertical | thru-hole | Female header, straight, 15 pin | https://cdn.harwin.com/pdfs/M20-782.pdf | https://www.digikey.com/en/products/detail/harwin-inc/M20-7821546/3728254
20 | J50 | 1 | Sullins Connector Solutions | PPTC031LGBN-RC | 3 Position Header Connector 0.100" (2.54mm) Through Hole, Right Angle Tin | 1x03_P2.54mm_right angle | thru-hole | Female header, right angle, 3 pin | https://mm.digikey.com/Volume0/opasdata/d220001/medias/docus/937/Female_Headers.100_DS.pdf | https://www.digikey.com/en/products/detail/sullins-connector-solutions/PPTC031LGBN-RC/775897
INCLUDED KIT ITEMS – NOT SOLDERED
21 | J15_ext | 1 | Generic | HC-SR04 | Ultrasonic Sensor Module | -- | thru-hole |  |  | https://thinkrobotics.com/products/ultrasonic-distance-sensor-hy-srf05
22 | OLED1_ext | 1 | Generic | Disp_SSD1306 | Disp_OLED_SSD1306_128x64, I2C | -- | thru-hole |  |  | https://www.rhydolabz.com/1.3-inch-i2c-iic-oled-display-module-4pin
23 | J18,J19_ext | 1 | Generic | Arduino Nano | Arduino Nano | -- | thru-hole | Arduino Nano with USB-C connector and cable |  | https://robu.in/product/atmega328p-5v-nano-v3-0-development-board-16mhz-ch340-type-c/
24 | -- | 1 | Generic | -- | 9V battery clip with female headers | -- | -- |  |  | https://makerbazar.in/products/9v-battery-snap-cap-connector?variant=46034938167536
25 | J50_ext | 1 | Generic | SKU 611201 | DC Vibration Motor Module – Black | -- | -- |  |  | https://robu.in/product/dc-vibration-motor-module/
CHANGES FROM PREVIOUS VERSION:
1 | SW2, SW3 – Push button switches are 12mm square (large) instead of 6mm square. Button height between 8mm to 12mm
2 | RV1 - Potentiometer value = 100k (104). If possible, please use trimpot with KNOB. See link in remarks above, ROW 18
3 | Q1 – Transistor value changed to BC547 and footprint and connections modified accordingly
4 | BT1 – Battery connector installed on BACK side of PCB, and it is right angle 2 pin header
5 | J50 – 3 pin, right angle female header added on BACK side of PCB for Haptic Motor module
6 | J15 and OLED1 – 4 pin female headers – the plastic part comes out. Please add a very small amount of super glue to fix it to PCB

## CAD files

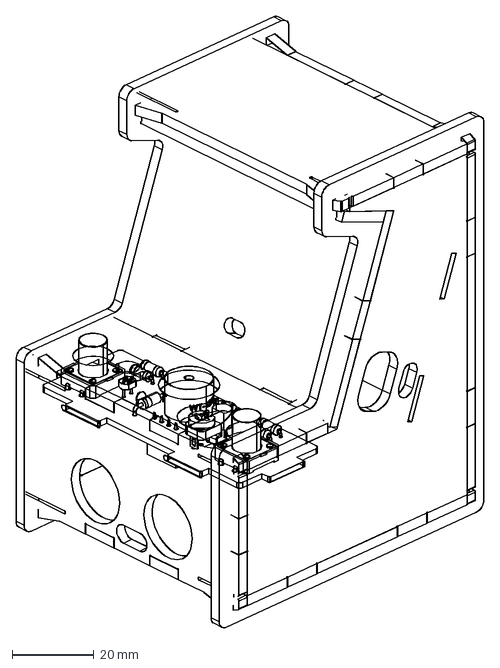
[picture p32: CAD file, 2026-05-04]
enclosure/images_user_guide/TheThing_v81_multiJoin_parts_assy_Page_02_iso.dxf
114.6 x 150.0 mm

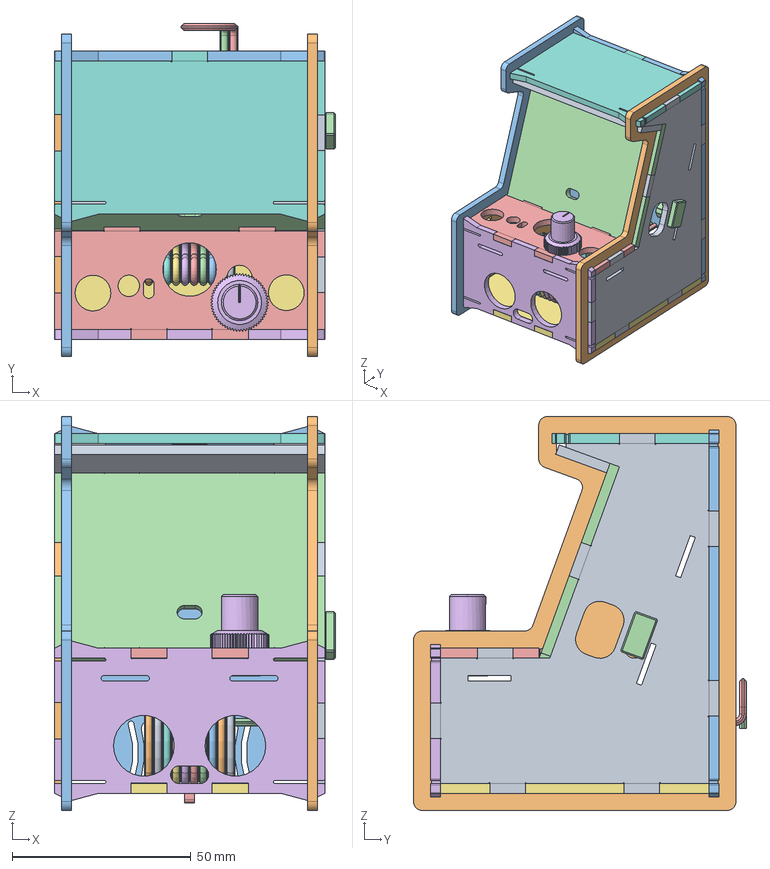
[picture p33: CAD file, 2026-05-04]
enclosure/TheThing_v81_multiJoin_parts_assy_LS2.FCStd
78.6 x 93.1 x 110.2 mm
Pad001_tab
Pad002_tab
Pocket_tab
Pocket016_tab
Pad018_tab
Pocket017_tab
Pocket021_tab
Fillet_tab
Pad016_tab
Body_right_clip_tab
Body_left_clip_tab
switch_slide
Stopper_bat
trimpot_knob_v3
PinSocket_1x10_P2.54mm_Vertical
PinSocket_1x10_P2.54mm_Vertical001
Cable_flat_10x
PinSocket_1x02_P2.54mm_Vertical
Bat+
Bat-

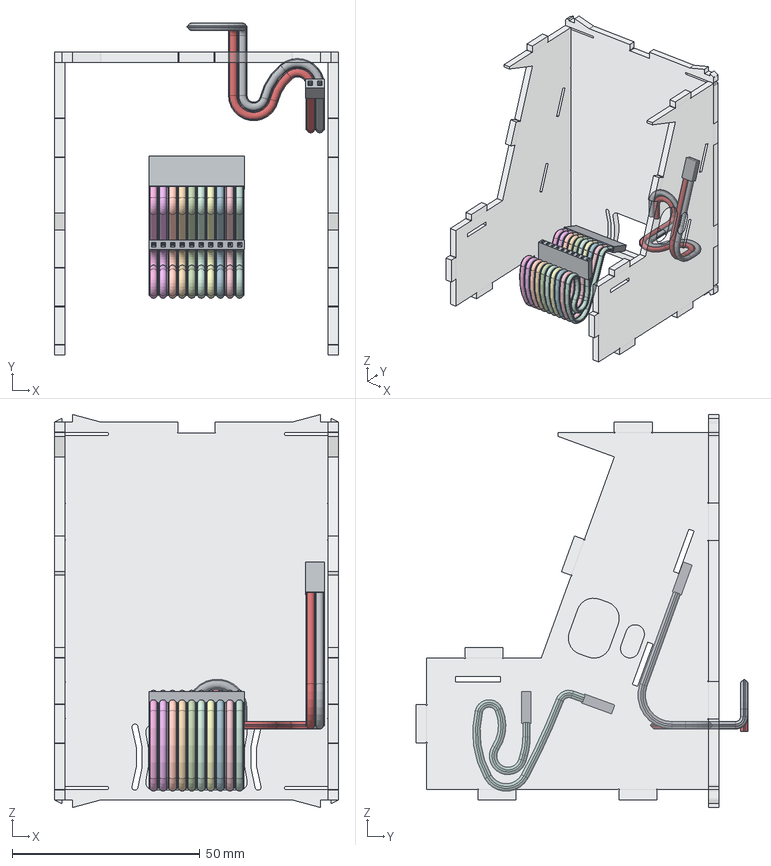
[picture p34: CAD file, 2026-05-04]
enclosure/TheThing_v81_multiJoin_parts_assy_LS.FCStd
75.6 x 88.3 x 104.6 mm
Pad001_tab
Pad002_tab
Pocket_tab
PinSocket_1x10_P2.54mm_Vertical
PinSocket_1x10_P2.54mm_Vertical001
Cable_flat_10x
PinSocket_1x02_P2.54mm_Vertical
Bat+
Bat-

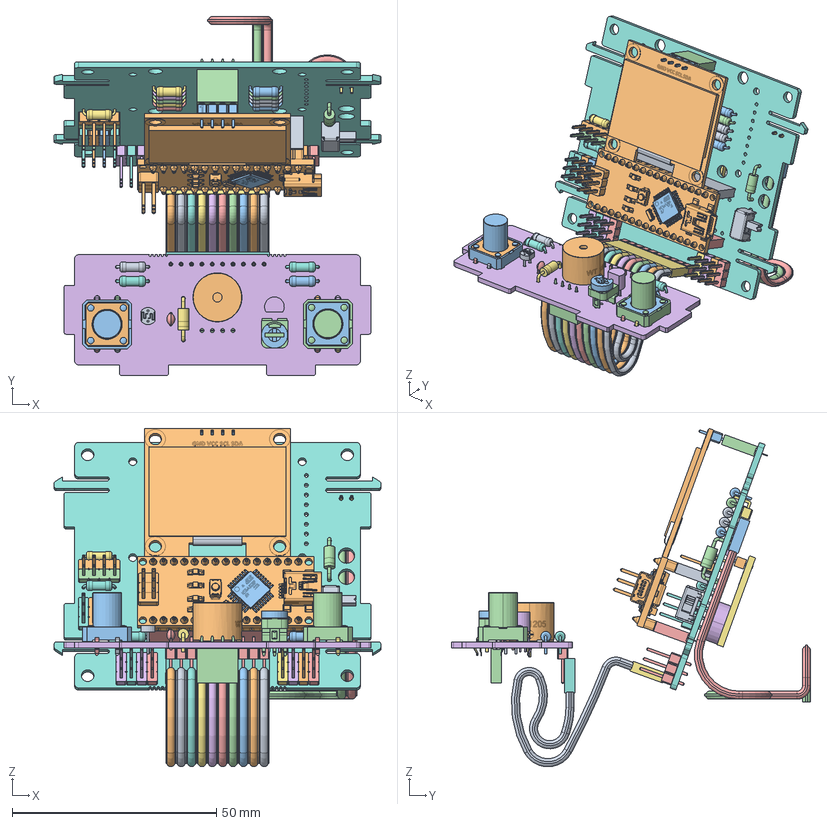
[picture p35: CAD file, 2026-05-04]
enclosure/TheThing_v81_multiJoin_parts_assy.FCStd
80.0 x 87.9 x 82.9 mm
SW_CuK_OS102011MA1QN1_SPDT_Angled
PinHeader_1x04_P2.54mm_Vertical
R_Axial_DIN0207_L6.3mm_D2.5mm_P7.62mm_Horizontal
D_DO-41_SOD81_P10.16mm_Horizontal
PinHeader_1x10_P2.54mm_Vertical
PinHeader_1x03_P2.54mm_Vertical
R_Axial_DIN0207_L6.3mm_D2.5mm_P7.62mm_Horizontal001
R_Axial_DIN0207_L6.3mm_D2.5mm_P7.62mm_Horizontal002
PinSocket_1x15_P2.54mm_Vertical
arduino_nano
arduino_nano001
R_Axial_DIN0207_L6.3mm_D2.5mm_P7.62mm_Horizontal003
PinHeader_1x03_P2.54mm_Vertical001
PinHeader_1x03_P2.54mm_Vertical002
PinHeader_1x03_P2.54mm_Vertical003
PinHeader_1x03_P2.54mm_Vertical004
Display_OLED-1_3-128X64
Display_OLED-1_3-128X065
Display_OLED-1_3-128X066
PinSocket_1x04_P2.54mm_Vertical
PinSocket_1x15_P2.54mm_Vertical001
R_Axial_DIN0207_L6.3mm_D2.5mm_P7.62mm_Horizontal004
R_Axial_DIN0207_L6.3mm_D2.5mm_P7.62mm_Horizontal005
PinHeader_1x03_P2.54mm_Vertical005
R_Axial_DIN0207_L6.3mm_D2.5mm_P7.62mm_Horizontal006
PinHeader_1x03_P2.54mm_Vertical006
R_Axial_DIN0207_L6.3mm_D2.5mm_P7.62mm_Horizontal007
R_Axial_DIN0207_L6.3mm_D2.5mm_P7.62mm_Horizontal008
R_Axial_DIN0207_L6.3mm_D2.5mm_P7.62mm_Horizontal009
PinHeader_1x03_P2.54mm_Vertical007
R_Axial_DIN0207_L6.3mm_D2.5mm_P7.62mm_Horizontal010
PinHeader_1x03_P2.54mm_Vertical008
R_Axial_DIN0207_L6.3mm_D2.5mm_P7.62mm_Horizontal011
PinHeader_1x03_P2.54mm_Vertical009
PinHeader_1x03_P2.54mm_Vertical010
PinHeader_1x04_P2.54mm_Vertical001
PinHeader_1x03_P2.54mm_Vertical011
PinSocket_1x03_P2.54mm_Horizontal_haptic
PinSocket_1x03_P2.54mm_Horizontal_haptic001
PinSocket_1x03_P2.54mm_Horizontal_haptic002
PinSocket_1x03_P2.54mm_Horizontal_haptic003
PinSocket_1x03_P2.54mm_Horizontal_haptic004
PinSocket_1x03_P2.54mm_Horizontal_haptic005
PinSocket_1x03_P2.54mm_Horizontal_haptic006
PinSocket_1x03_P2.54mm_Horizontal_haptic007
PinSocket_1x03_P2.54mm_Horizontal_haptic008
PinHeader_1x02_P2.54mm_Horizontal
TheThing_main_PCB
R_Axial_DIN0207_L6.3mm_D2.5mm_P7.62mm_Horizontal012
SW_TS14-1212-120-BK-160-SCR-D
SW_TS14-1212-120-BK-160-SCR-D001
SW_TS14-1212-120-BK-160-SCR-D002
SW_TS14-1212-120-BK-160-SCR-D003
SW_TS14-1212-120-BK-160-SCR-D004
SW_TS14-1212-120-BK-160-SCR-D005
R_Axial_DIN0207_L6.3mm_D2.5mm_P7.62mm_Horizontal013
R_LDR_4.2x3.5mm_P2.54mm_Vertical
R_LDR_4.2x3.5mm_P2.54mm_Vertical001
Trimpot_THT
Trimpot_THT001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

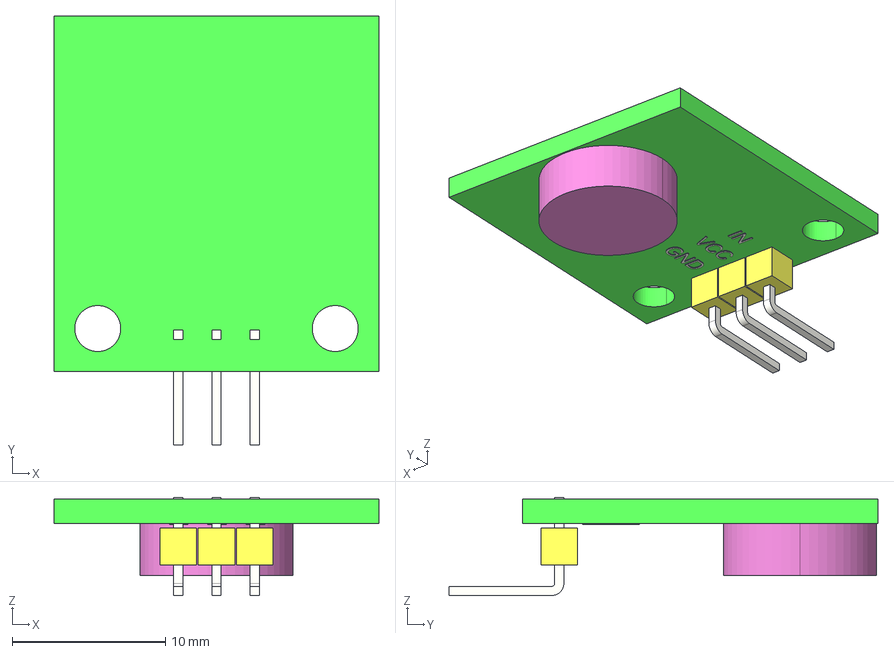
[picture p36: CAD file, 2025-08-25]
hardware_PCB/TheThing_v8/3D_models/vibration_motor_pcb_asm.stp
21.2 x 28.0 x 6.40 mm
VIBRATION_MOTOR_PCB
PRT0002 x 3
PRT0003 x 3
MOTOR

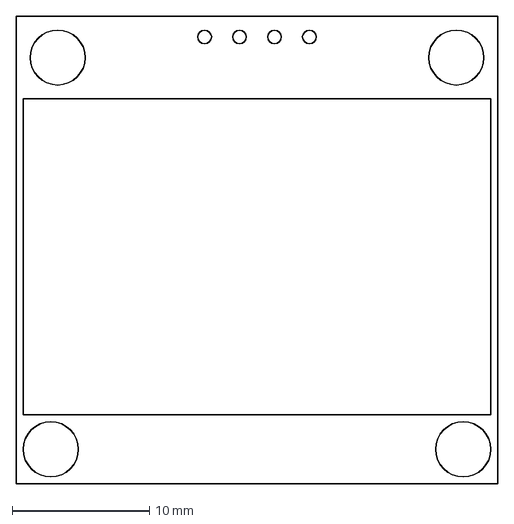
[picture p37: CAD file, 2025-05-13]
datasheets/Disp_OLED_64x64_v3.dxf
35.0 x 34.0 mm

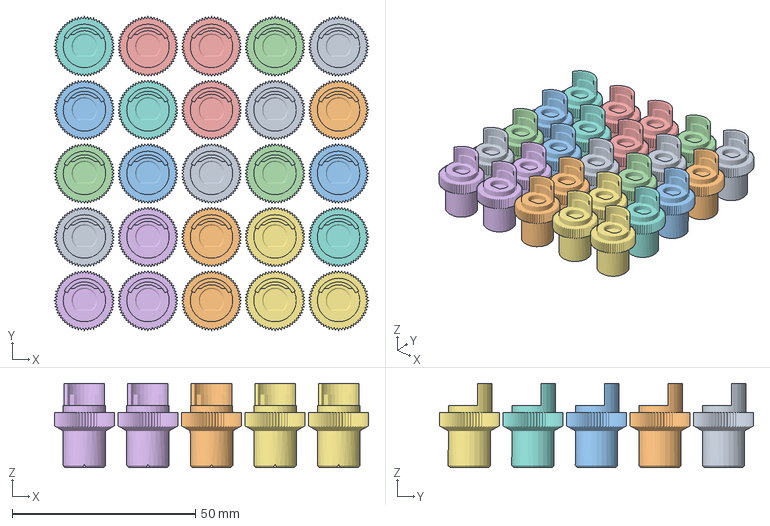
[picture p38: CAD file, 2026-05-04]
enclosure/3D_print/TheThing_v8-trimpot_knob_v4x25nos.3mf
85.7 x 85.7 x 23.0 mm
TheThing_v8-trimpot_knob_v4.stl x 25

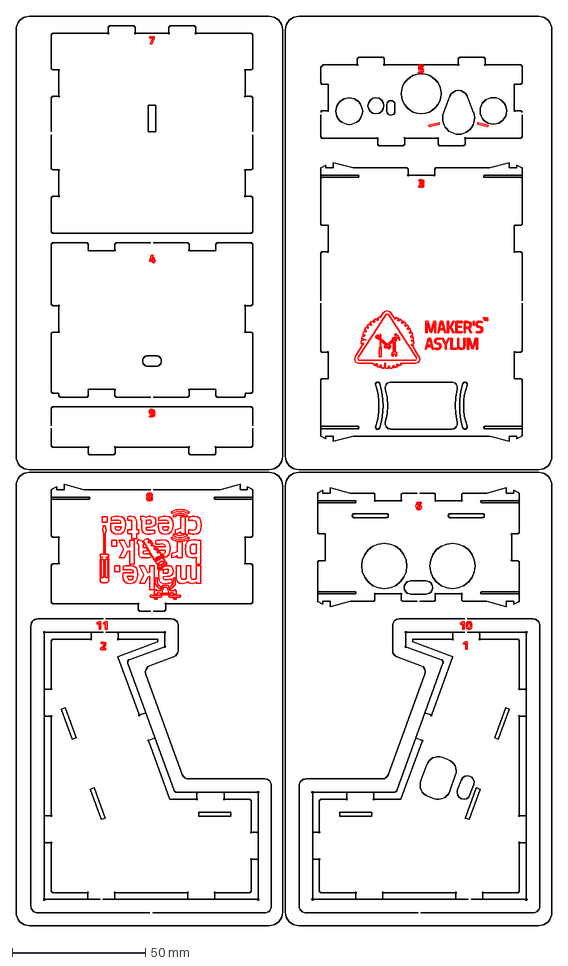
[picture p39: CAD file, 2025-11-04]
enclosure/DXF/TheThing_v81_tabs_Inkscape.dxf
201.0 x 341.0 mm

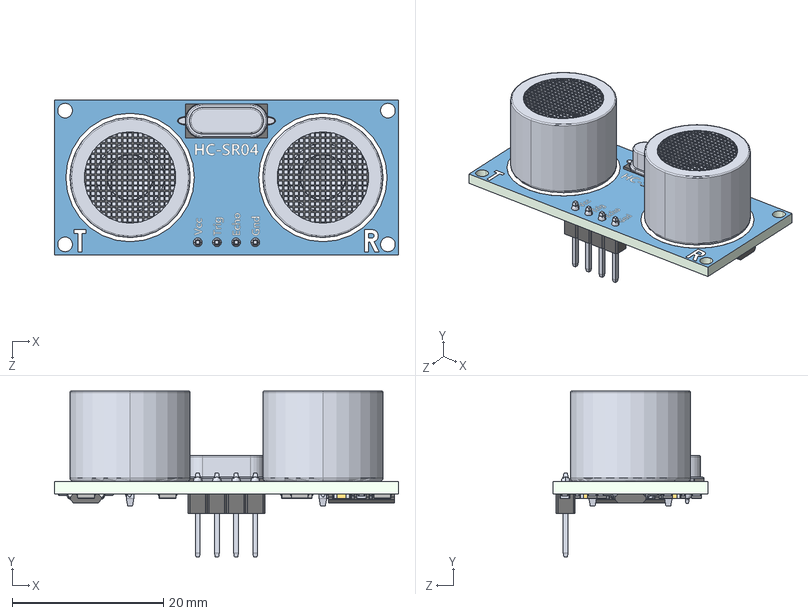
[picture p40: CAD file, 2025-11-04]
enclosure/footprints_for_kicad/HC-SR04 (1).STEP
45.5 x 21.9 x 20.5 mm
HC-SR04board
solder x 10
Emitter x 2
CrystalOscillator
smdChip14pin x 2
smdChip16pin
smdceramiccapacitor x 7
smdResistor753 x 3
smdResistor392
smdResistor103 x 6
smdResistor124 x 2
smdResistor335
smdResistor102
smdResistor563
smdResistor622
smdResistor412
headerMale x 4

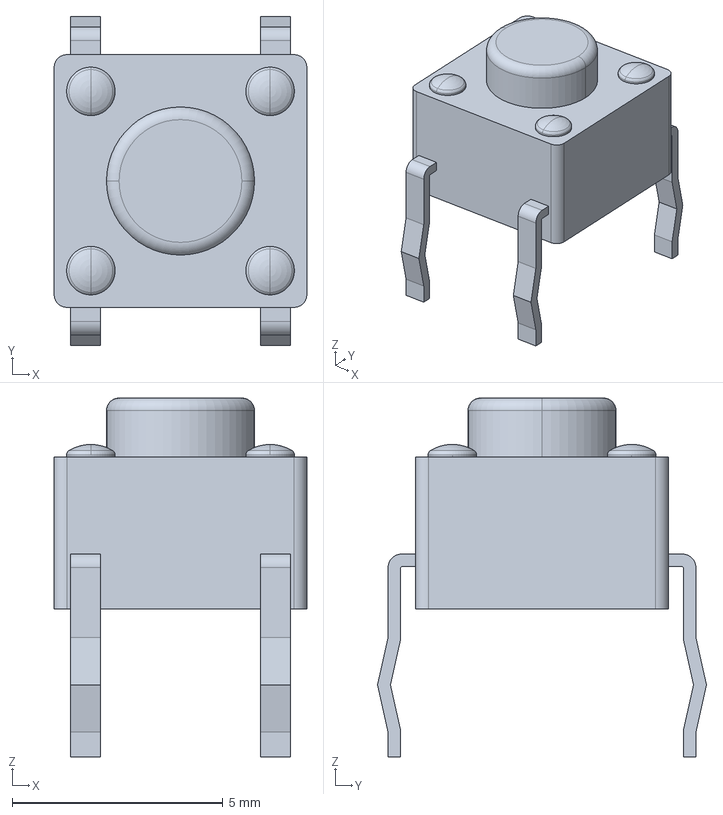
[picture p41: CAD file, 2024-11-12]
enclosure/footprints_for_kicad/Tactile_Switch/c-1825910-6-c-3d.stp
5.99 x 7.80 x 8.51 mm

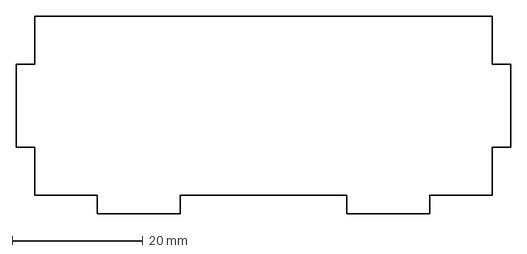
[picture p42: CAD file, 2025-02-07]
fabricate/DXF/export_PCB_edgecut.dxf
75.6 x 30.2 mm

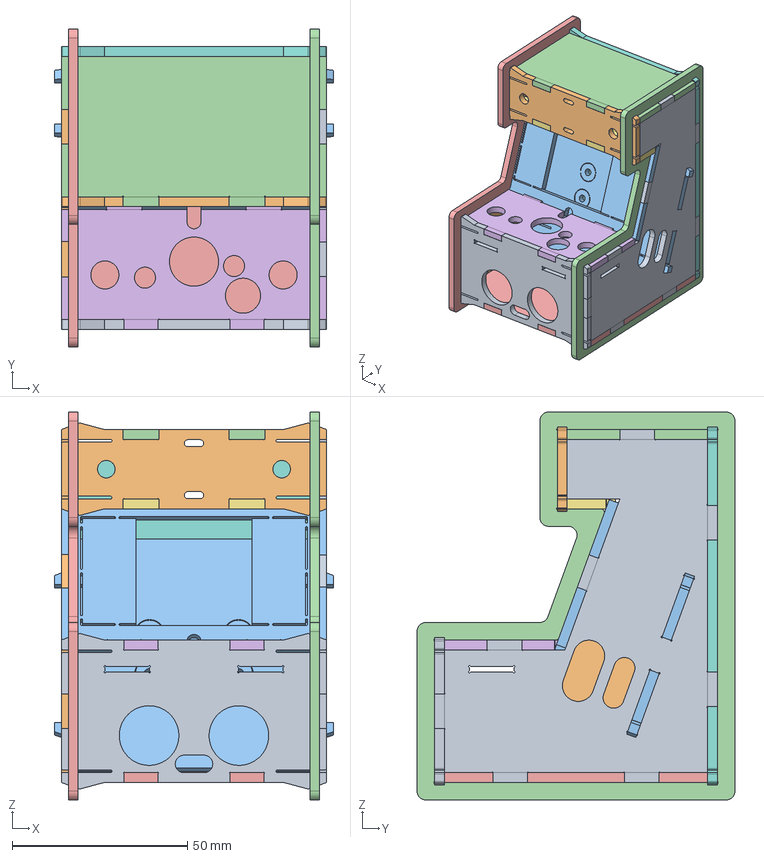
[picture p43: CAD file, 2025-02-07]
fabricate/TheThing_v5_multijoin2.FCStd
79.6 x 90.6 x 110.6 mm
Pocket011_tab
Pocket013_tab
Pad003_tab
Pad013_tab
Pad014_tab
Pocket018_tab
Pad016_tab
Pocket007_tab
Pocket017_tab
Pocket_tab
MultiTransform_tab
Pocket009_tab
Clone001_tab

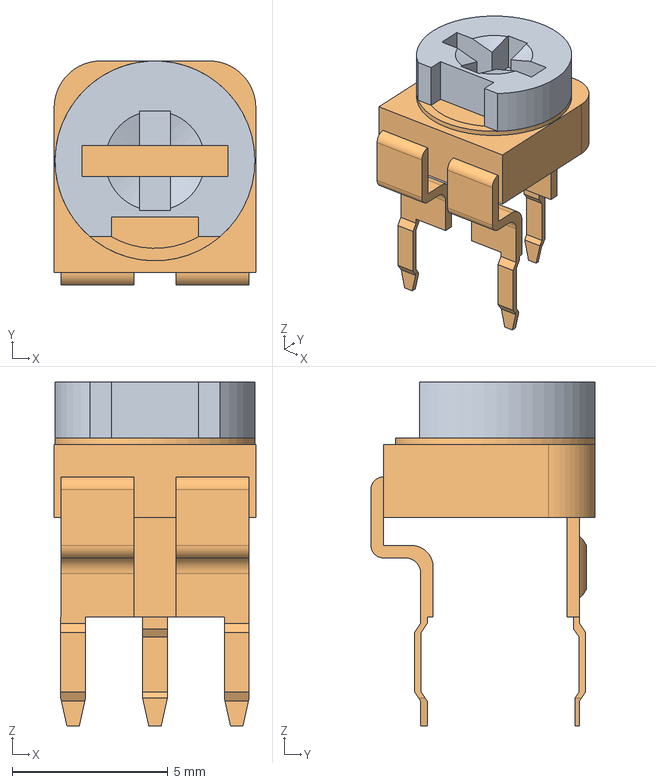
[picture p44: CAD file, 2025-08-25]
hardware_PCB/TheThing_v8/3D_models/trimpot.step
6.48 x 7.20 x 11.1 mm

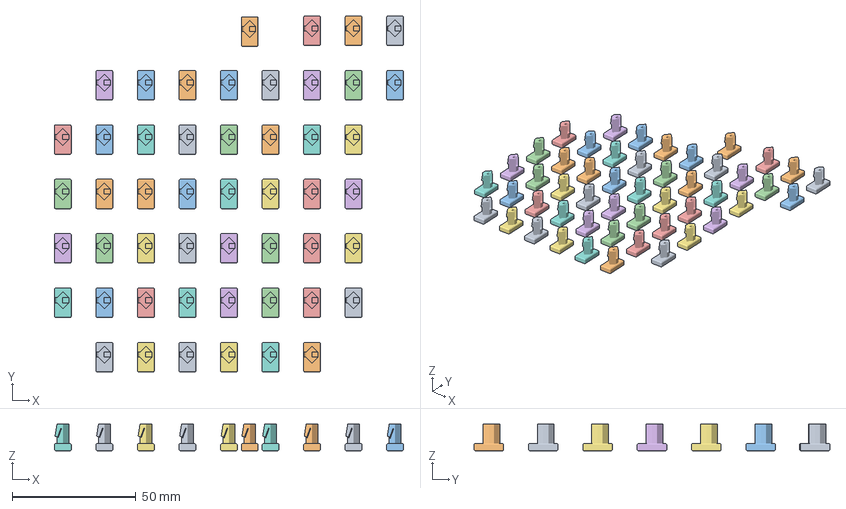
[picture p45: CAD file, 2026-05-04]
enclosure/3D_print/TheThing_v8-switch_slidex50nos.3mf
141.2 x 144.0 x 10.8 mm
TheThing_v8-switch_slide.stl x 50

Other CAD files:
enclosure/TheThing_v81_tabs_export.FCStd
datasheets/Disp_OLED_64x64.FCStd
enclosure/footprints_for_kicad/HC_SR04.FCStd
datasheets/Disp_OLED_64x64_v2.dxf
documentation/archive/arcadedice.dxf
enclosure/3D_print/TheThing_v8-Stopper_bat.3mf
enclosure/3D_print/TheThing_v8-Stopper_bat.step
enclosure/3D_print/TheThing_v8-Stopper_bat.stl
enclosure/3D_print/TheThing_v8-Stopper_batx50nos.3mf
enclosure/3D_print/TheThing_v8-switch_slide.3mf
enclosure/3D_print/TheThing_v8-switch_slide.step
enclosure/3D_print/TheThing_v8-switch_slide.stl
enclosure/3D_print/TheThing_v8-trimpot_knob_v3.3mf
enclosure/3D_print/TheThing_v8-trimpot_knob_v3.stl
enclosure/3D_print/TheThing_v8-trimpot_knob_v3x50nos.3mf
enclosure/3D_print/TheThing_v8-trimpot_knob_v4.3mf
enclosure/3D_print/TheThing_v8-trimpot_knob_v4.step
enclosure/3D_print/TheThing_v8-trimpot_knob_v4.stl
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

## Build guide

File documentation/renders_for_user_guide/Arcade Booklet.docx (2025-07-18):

Renders Needed

1. Main Render for first page.
2. Top shot of laser cut dxf, line drawings of components
3. Exploded view with number labelling
4. Top View of both PCB’s with component labelling of where everything goes
5. Assembly order and photos likewise a. Place the screen b. Place the Arduino c. Connect the 10 way cable d. Attaching the battery cap e. Connect the Ultrasonic sensor f. Attaching both side acrylics to the main pcb g. Add the 2nd pcb to the body h. Next goes the top button panel i. The front display piece j. Followed by the top, back and bottom piece k. Lastly attach both outer rings

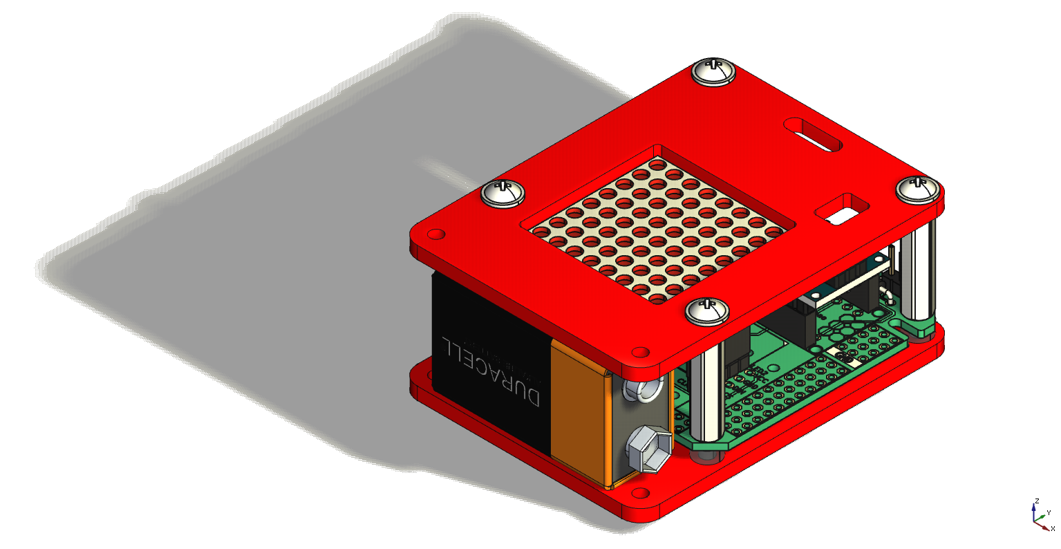
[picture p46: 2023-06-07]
fabricate/renders/BagTag_09.png

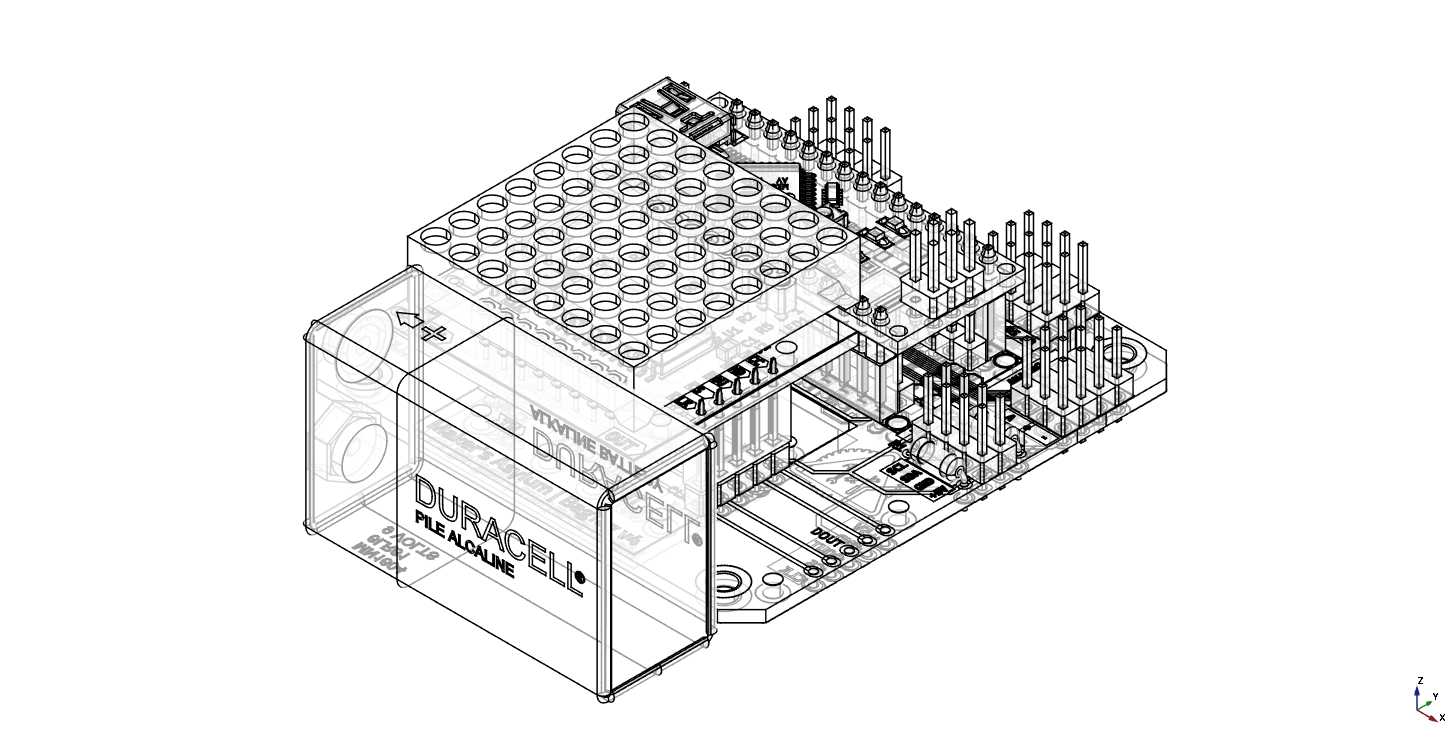
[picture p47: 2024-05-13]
fabricate/renders/BagTag_07.png

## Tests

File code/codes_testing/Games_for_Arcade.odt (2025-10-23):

Here is the Hardware description of my Arduino Nano based mini ARCADE project that I built to teach young kids the basics of Arduino programming.

* 1.3" monochrome SH1106 128x64 pixel OLED screen with I2C connections to SDA and SCL of Nano
* Potentiometer with it's wiper pin connected to Nano pin A0
* LDR with pull down resistor connected to Nano pin A1
* RIGHT BTN connected to Nano pin D2 and with pull down resistor
* Buzzer connected between +5V and collector of a NPN transistor. The Base of the transistor is connected to Nano pin D3
* LEFT BTN and with pull down resistor connected to Nano pin D4
* Haptic Motor connected to Nano pin D5
* Ultrasonic Sensor with Echo connected to Nano pin D6 and Trigger connected to Nano pin D7 Please suggest some simple games that can be coded for playing on this hardware

###### ChatGPT said:

That’s an excellent little hardware setup — your Arduino Nano–based mini ARCADE has just enough I/O and sensors to support a surprisingly wide range of interactive games.
It’s perfect for teaching sensor integration, logic, and simple graphics using the SH1106 OLED.

Below is a curated list of simple game ideas designed for young learners, grouped by complexity and which sensors/buttons they use.

## 🎮 LEVEL 1: Easy Starter Games

(Use basic buttons, buzzer, and display — ideal for beginners.)

### 1. Button Duel (Reflex Game)

- Goal: Two players press their button (LEFT or RIGHT) as soon as a “GO!” signal appears on the OLED.
- Gameplay:
  - A random delay, then “GO!” is displayed.
  - The first player to press wins.
  - Buzzer or haptic motor gives feedback for the winner.
- Teaches: Debouncing, timing (millis()), random delays.

### 2. Reaction Timer

- Goal: Press a button as quickly as possible when a visual signal (or buzzer) appears.
- Hardware Used: LEFT button, buzzer, OLED.
- Feedback: Display your reaction time in milliseconds.
- Teaches: Input timing, using millis() instead of delay().

### 3. Catch the Dot

- Goal: Move a paddle left/right to “catch” a falling dot.
- Hardware Used: Potentiometer for paddle position, OLED for animation, buzzer for success/fail.
- Gameplay:
  - A dot falls from the top.
  - Move paddle with the potentiometer.
  - If the dot hits the paddle → score++.
  - If it misses → buzzer beeps and game ends.

## 🎯 LEVEL 2: Sensor-Based Games

(Uses analog inputs like the LDR, ultrasonic, or potentiometer.)

### 4. Shadow Dodge (LDR Game)

- Goal: Control a character using light intensity.
- Gameplay:
  - The player moves up/down depending on how much light hits the LDR.
  - Obstacles scroll from the right.
  - Move into darker/lighter zones to dodge them.
- Teaches: Analog reading, thresholds, mapping sensor data.

### 5. Ping Pong (Ultrasonic Paddle)

- Goal: Bounce a moving ball using an ultrasonic-controlled paddle.
- Hardware Used: Ultrasonic sensor to move paddle up/down.
- Gameplay:
  - Paddle moves based on distance.
  - Ball bounces off paddle and screen edges.
  - Miss → lose a life, buzzer beeps.
- Teaches: Sensor reading, mapping, motion logic.

### 6. Whack-a-Block

- Goal: Hit targets that appear randomly on screen using the potentiometer (move) and a button (hit).
- Hardware Used: Potentiometer, LEFT button, buzzer.
- Gameplay:
  - Blocks appear randomly.
  - Move your “hammer” horizontally and press to hit.
  - Buzz/haptic feedback when successful.
- Teaches: Input coordination, random positions.

## 🚀 LEVEL 3: Classic Mini-Games

(Combine multiple inputs and small logic loops.)

### 7. Snake (Potentiometer or LDR Controlled)

- Goal: Eat food and grow while avoiding self-collision.
- Controls:
  - Potentiometer: left/right turning.
  - LDR: Light direction changes turn.
- Feedback: Game over tone (3 short beeps).
- Teaches: Arrays, grid-based movement, collision detection.

### 8. Space Invaders (Potentiometer Movement + Buttons to Shoot)

- Goal: Move horizontally with the potentiometer and shoot descending aliens using LEFT or RIGHT button.
- Feedback: Buzzer and haptic for explosions.
- Teaches: Object tracking, simple sprite animation, shooting mechanics.

### 9. Obstacle Runner (Ultrasonic Jump Game)

- Goal: Avoid oncoming obstacles by “jumping” — you raise your hand above the ultrasonic sensor to make the character jump.
- Hardware Used: Ultrasonic sensor, OLED, buzzer.
- Gameplay: Similar to Google Chrome’s Dino game.
- Teaches: Distance measurement, reaction timing, animation.

## 🧠 LEVEL 4: Creative Learning Projects

(Encourage kids to design their own logic or interaction.)

### 10. Mood Meter (LDR + Potentiometer)

- Goal: Create a “mood face” that changes expression based on ambient light and potentiometer position.
- Light → brightness of the smile.
- Knob → switch between happy/sad/neutral.
- Teaches: Analog sensor mapping and conditional display logic.

### 11. Simon Says (Memory Game)

- Goal: Repeat the sequence of beeps/flashes shown on screen.
- Hardware Used: OLED for cues, buzzer for tones, LEFT/RIGHT buttons for input.
- Teaches: Arrays, pattern recall, sequence validation.

### 12. Balance Game (Potentiometer)

- Goal: Keep a small ball balanced at the center of a line using the potentiometer.
- Gameplay:
  - Ball drifts left or right automatically.
  - Adjust potentiometer to keep it centered.
  - Buzzer or haptic buzzes if it drifts too far.
- Teaches: PID concepts, analog control, calibration.

## 🏁 Bonus Ideas:

- Music Box: Use potentiometer to select tones, buttons to play.
- Light Tracker: LDR-based game — “chase” the right light range.
- Score Counter: Simple app where button presses add/subtract points and display total.

### 🔧 Recommendation for Classroom Teaching:

You can build a menu-driven “ARCADE launcher” that lists all these games:

1. Pong

2. Snake

3. Catch the Dot

4. Shadow Dodge

5. Space Invaders

➡️ Navigate with potentiometer,
➡️ Press LEFT to start,
➡️ Press RIGHT to exit to menu.

That way, kids can try different sensor-driven games without re-uploading sketches.

PLAN

we’ll create 5 beginner-friendly games for your Arduino Nano–based mini ARCADE that progressively introduce key programming and hardware concepts — from digital inputs to sensor mapping and simple animation.

Each game will be:
✅ Fully commented (educational style).
✅ Simple enough for kids to follow.
✅ Designed for your exact hardware (OLED, potentiometer, ultrasonic, buttons, haptic motor, buzzer).
✅ Consistent layout and code structure.

## 🕹️ 5 GAMES FOR YOUR MINI ARCADE

# | Game | Key Hardware Used | Concept Taught

1 | Button Duel (Reaction Game) | LEFT + RIGHT buttons, buzzer, OLED | Timing & logic
2 | Catch the Dot | Potentiometer, buzzer, OLED | Analog mapping & collision detection
3 | Shadow Dodge | LDR, buzzer, OLED | Using light sensor as control
4 | Ultrasonic Pong | Ultrasonic sensor, buzzer, OLED | Distance mapping, animation
5 | Space Invaders Mini | Potentiometer + buttons | Object motion & shooting

Below is Game #1 — we’ll start here, and then I’ll generate the rest (2-5) in sequence if you confirm the format looks right.

### 🧠 Concepts Introduced:

- Digital input handling
- Random delay generation (random())
- Simple game states (ready → play → result)
- Output feedback using buzzer/haptic motor

✅ Added a “Starting…” animation after LEFT BTN is pressed (3 dots appear sequentially).
✅ Made the game automatically restart after it’s over — either by pressing LEFT BTN to start a new round or both buttons together to return to the intro screen.
✅ Cleaned up visuals and comments for readability.

### 🧩 NEW FEATURES

- ✨ “Starting...” animation after LEFT BTN pressed — gives a short suspense buildup.
- 🔁 Restart anytime — press LEFT BTN to replay or both buttons to reset.
- 🎵 Clean feedback cycle — short buzz + haptic twice for winner.

## 🕹️ MINI ARCADE GAME #2 — CATCH THE DOT

### 🎯 Concept:

A small dot moves left and right across the OLED screen.
The player uses the potentiometer to move their paddle at the bottom.
If the paddle catches the dot — they score a point!
If they miss, they lose a point.
The first to reach +5 or -3 points ends the game.
After the game, press LEFT BTN to restart.

### 💡 Hardware (Arduino Nano Based)

- SH1106 128x64 OLED (I2C) → SDA = A4, SCL = A5
- Potentiometer → Wiper → A0
- LEFT BTN (Restart) → D4 (with pull-down resistor)
- Buzzer → D3 → NPN transistor → +5V
- Haptic Motor → D5 → transistor driver → +5V

### 🧠 Teaching Focus

- Analog input → digital movement (potentiometer control)
- Simple collision detection
- Using the display for animation
- Feedback using buzzer + haptic

### 🧩 How It Works

- The dot falls vertically and resets after each round.
- The paddle position updates smoothly using a low-pass filter on the potentiometer reading.
- The buzzer + haptic motor give instant physical feedback.
- The score shows in the corner, and the game restarts with one button press.

## 🕹️ MINI ARCADE GAME #3 — AVOID THE OBSTACLES

### 🎯 Concept:

You control a small player block that can move left and right using the potentiometer.
Falling obstacles (blocks) drop from the top — your goal is to avoid getting hit.
Each successful dodge gives you a point.
If you collide, you lose a life.
Lose 3 lives, and the game ends.
You can press LEFT BTN to start a new game after “Game Over.”

### 💡 Hardware

Same as your current Mini Arcade:

- OLED (SH1106) → I2C
- Potentiometer (A0) → controls player position
- LEFT BTN (D4) → Start / Restart
- Buzzer (D3) → via transistor
- Haptic Motor (D5) → via transistor
- (No need for Ultrasonic / LDR in this game)

### 🧠 Learning Goals

- Continuous animation using timed motion
- Collision detection between rectangles
- Randomized spawning and progressive difficulty
- Sound + haptic feedback for collision
- Restart logic

### 🧩 How it works

- Potentiometer controls player movement smoothly.
- Random blocks fall from the top; you gain a point for dodging.
- Collision detection checks overlap between block and paddle.
- Lives decrease when hit; when all are gone, the game ends.
- LEFT BTN restarts the game.
- Buzzer + haptic provide physical feedback on crashes.

## 🎮 MINI ARCADE GAME #4 — SPACE SHOOTER

### 🌌 Game Concept

You control a spaceship at the bottom of the screen using the potentiometer to move left and right.
Press LEFT BTN to shoot lasers at descending enemies.
Each hit gives you 1 point.
If an enemy reaches the bottom, you lose 1 life.
Lose all 3 lives → Game Over.
Press RIGHT BTN to restart the game.

### 💡 Hardware (Arduino Nano)

Component | Connection
OLED Display (SH1106, 1.3") | I²C (SDA=A4, SCL=A5)
Potentiometer | A0
LEFT BTN (Fire) | D4 (with pulldown)
RIGHT BTN (Restart) | D2 (with pulldown)
Buzzer (via NPN transistor) | D3
Haptic Motor | D5
Ultrasonic / LDR | Not used in this game

### 🧠 Learning Focus

- Motion and shooting logic
- Collision detection
- Multiple objects (bullet & enemies)
- Score and life tracking
- Game restart flow
- Visual feedback with simple animation

### 🪄 Features for Kids to Learn

- Random motion + timing = real-world animation logic
- Collision detection = bounding box math
- Sound + haptic feedback = tangible output
- Game over logic + restart = event-driven flow
- Gradual difficulty keeps it engaging

### 🔧 Key Improvements

✅ Multiple bullets (up to 5 on screen)
✅ Faster firing (150 ms cooldown)
✅ Simple logic — easy for kids to read and modify
✅ No rapid repeat issues — still controlled, but satisfying

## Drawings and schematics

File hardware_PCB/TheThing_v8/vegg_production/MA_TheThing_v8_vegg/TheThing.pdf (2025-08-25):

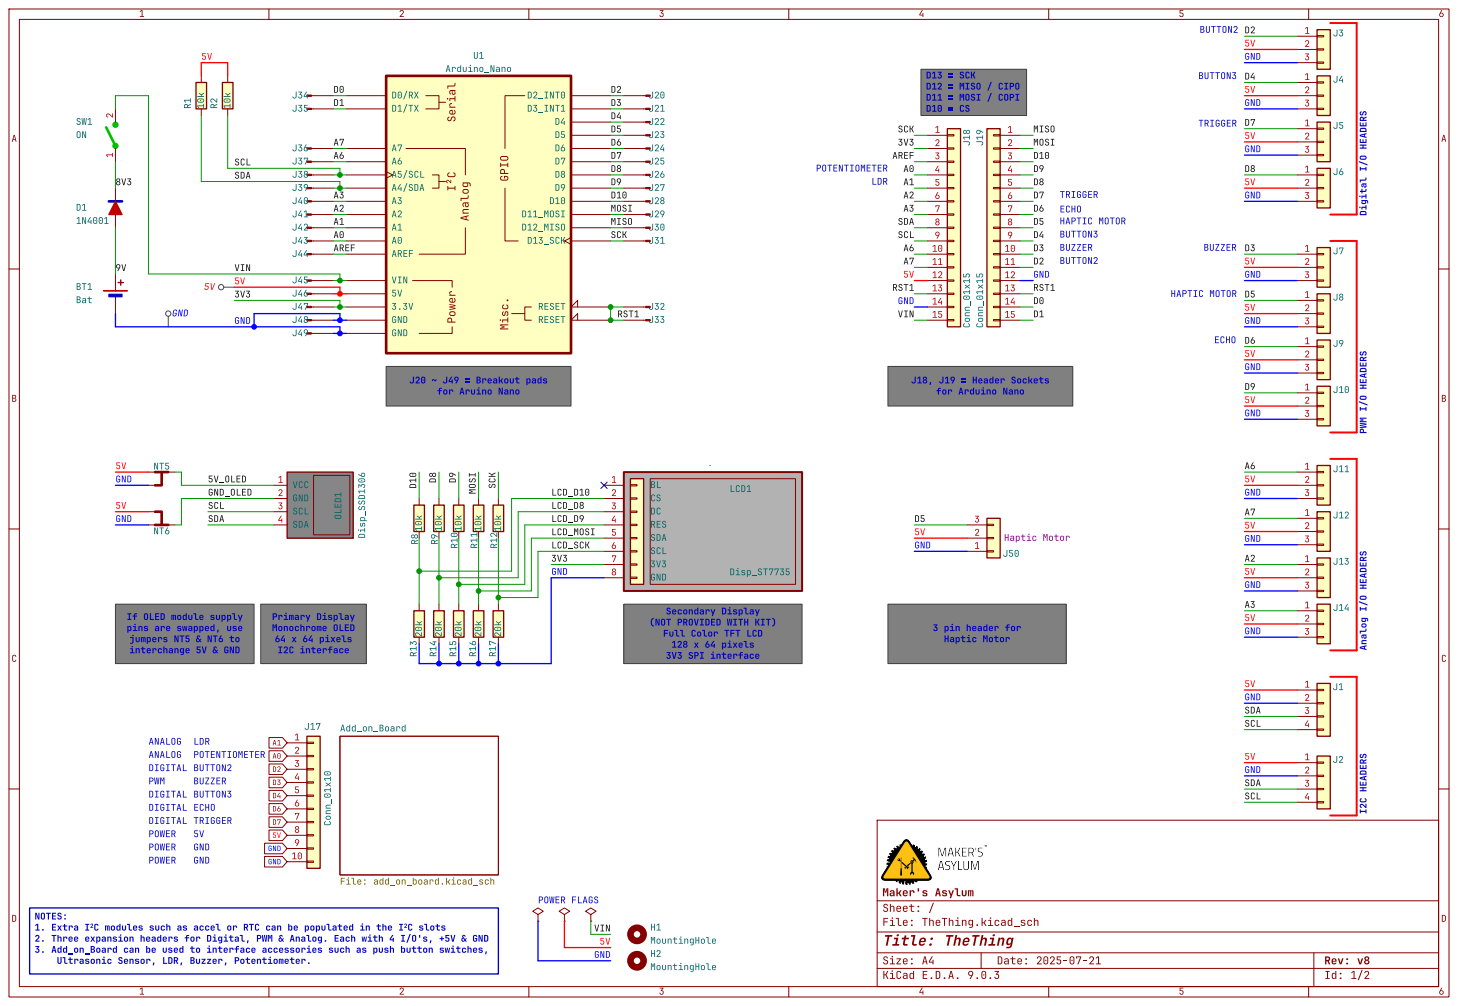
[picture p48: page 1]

for Aruino Nano NOTES: 1. Extra I^{2}Cmodules such as accel or RTC can be populated in the I^{2}Cslots

3 pin header for Haptic Motor J20 ~ J49 = Breakout pads

If OLED module supply
pins are swapped, use
jumpers NT5 & NT6 to

Primary Display Monochrome OLED

(NOT PROVIDED WITH KIT) Full Color TFT LCD

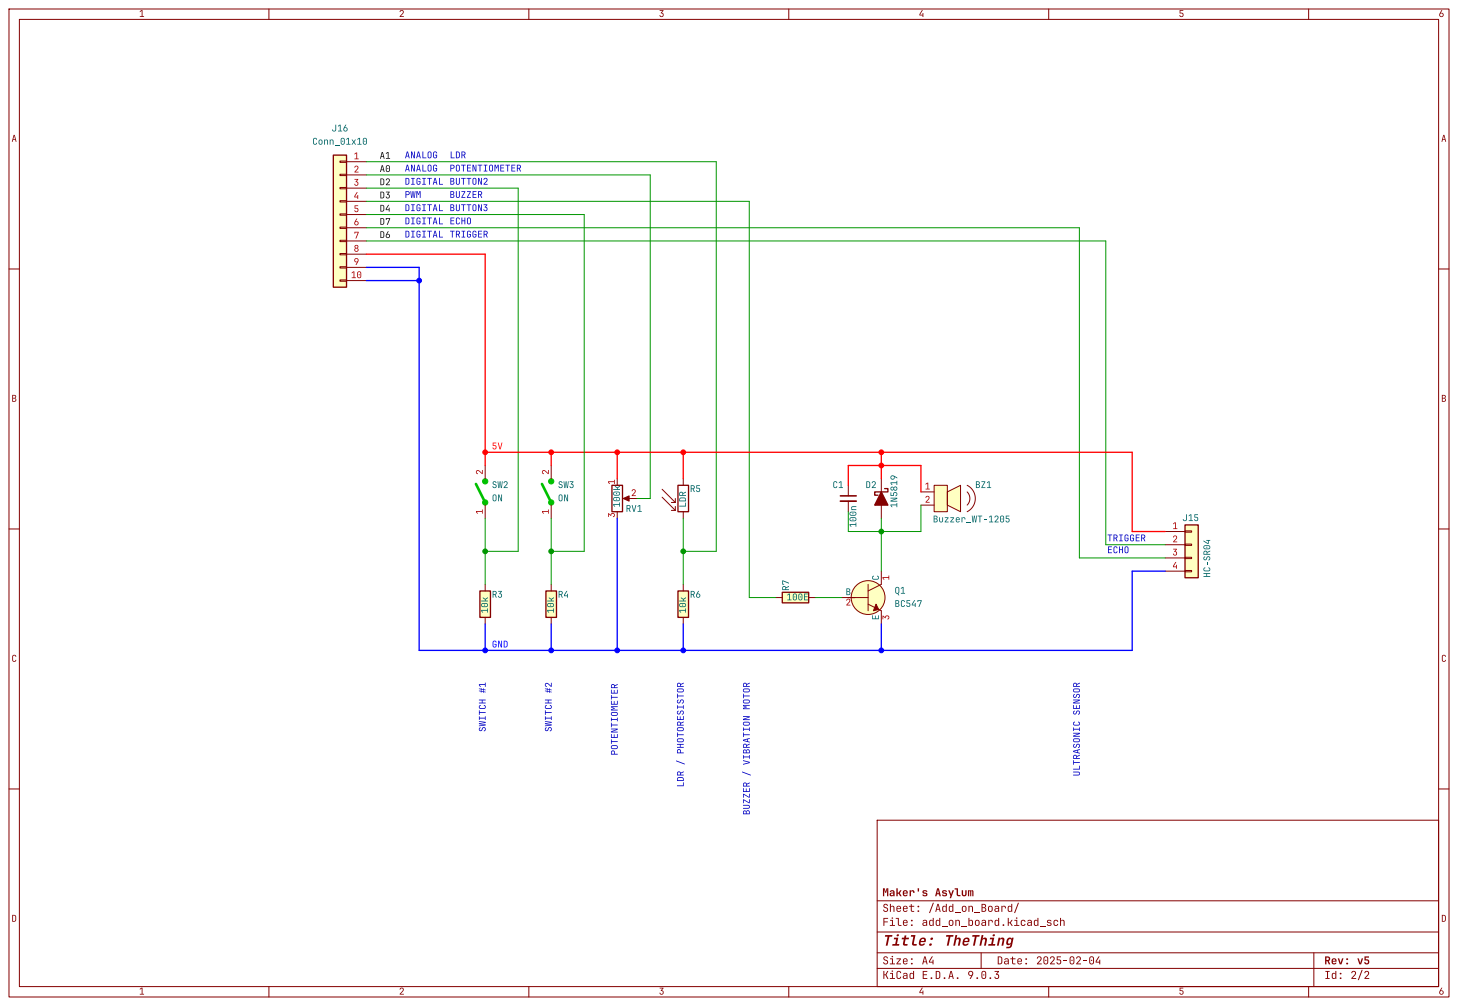
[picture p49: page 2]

BUTTON3 DIGITAL ECHO

TRIGGER

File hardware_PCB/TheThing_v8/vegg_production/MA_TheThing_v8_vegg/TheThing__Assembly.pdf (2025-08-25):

12.0 mm | 29.6 mm ¹².0 mm
OLED1 | J19 RV1

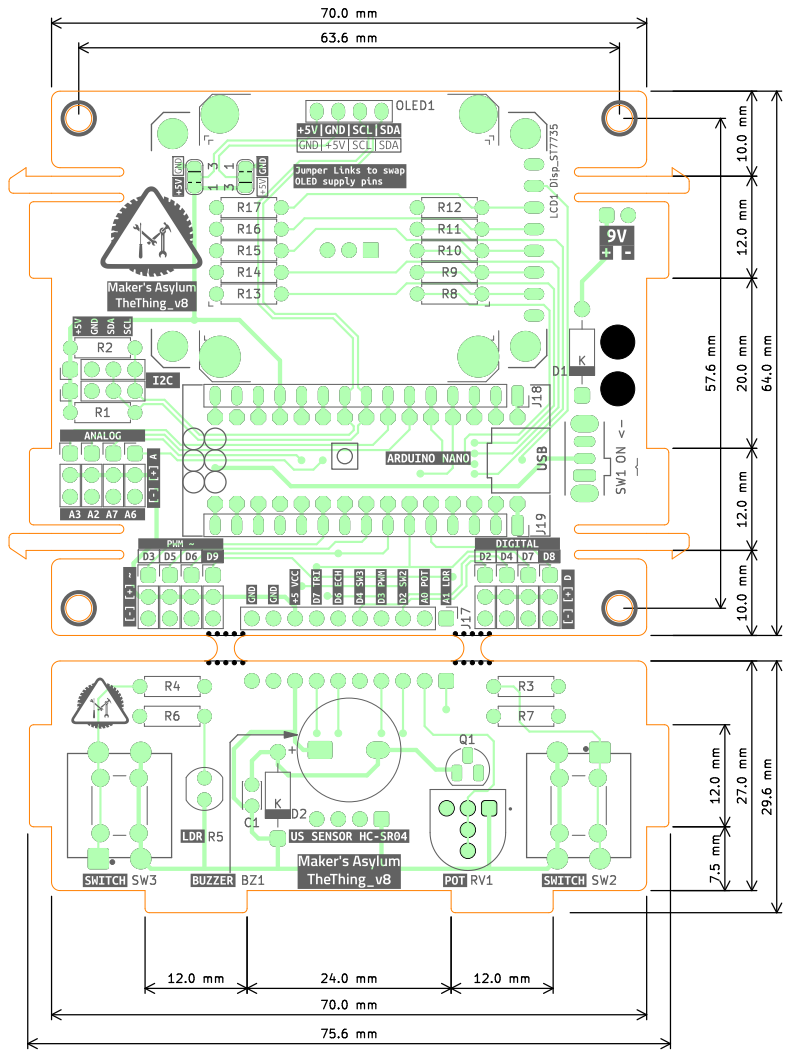
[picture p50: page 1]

File: TheThing.kicad_pcb Sheet: Colored-TOP Maker's Asylum

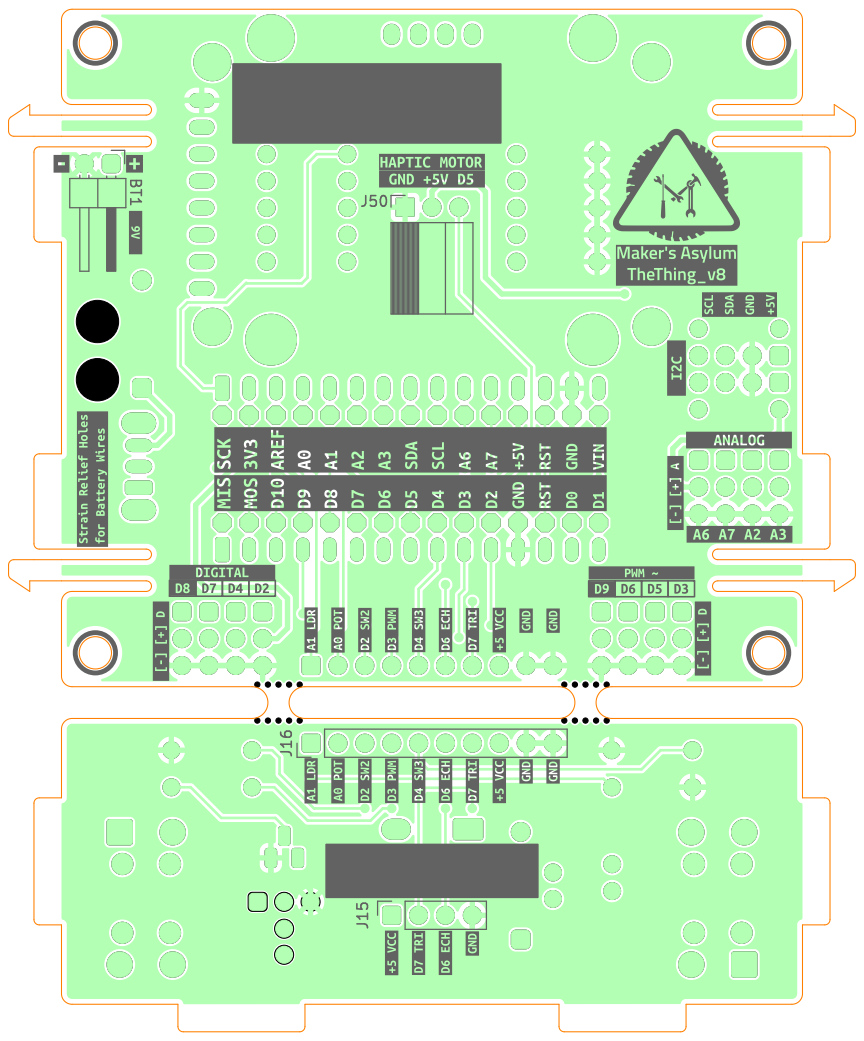
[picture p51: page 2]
D Date: 2025-07-21 KiCad; E.D.A. 9.0.3 Size: A4; Rev: v8; Board2Pdf:; Colored-BOT; Page 2/2

File: TheThing.kicad_pcb Sheet: Colored-BOT Maker's Asylum

Id: /1 Title: TheThing

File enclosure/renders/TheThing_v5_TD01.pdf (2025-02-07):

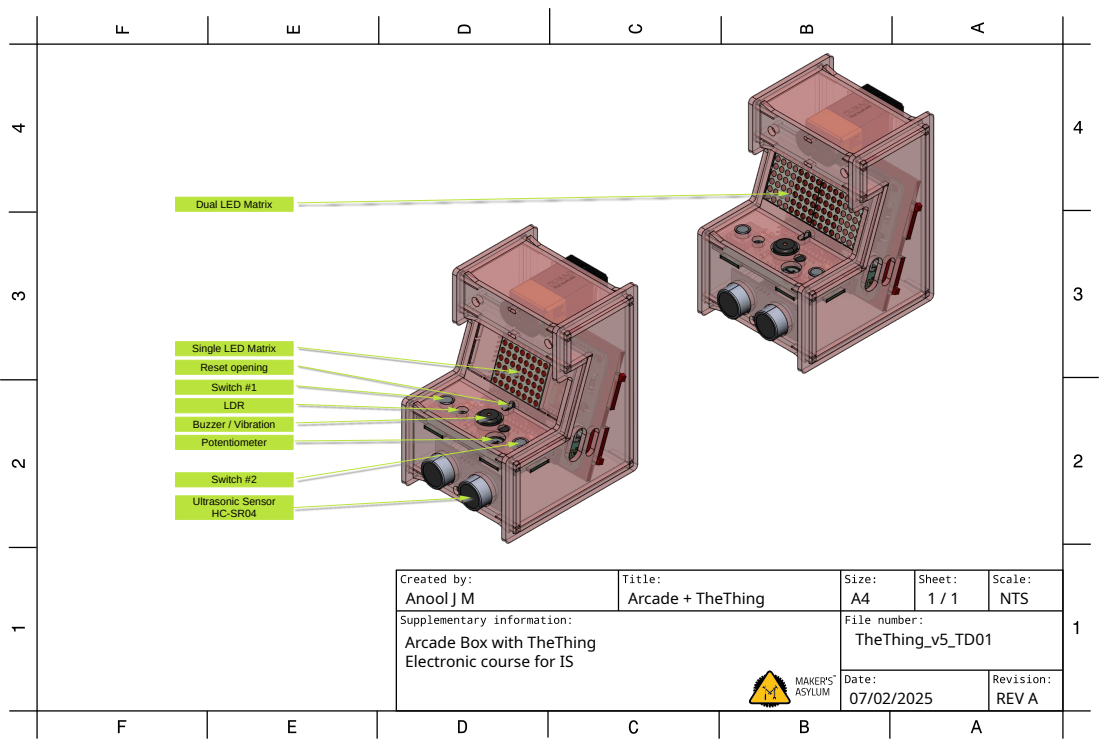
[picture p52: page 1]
Anool J M; Arcade + TheThing; NTS; TheThing_v5_TD01; REV A; Ultrasonic Sensor HC-SR04; Switch #2

Dual LED Matrix

Single LED Matrix
Reset opening
Switch #1
LDR
Buzzer / Vibration
Potentiometer

Arcade Box with TheThing
Electronic course for IS

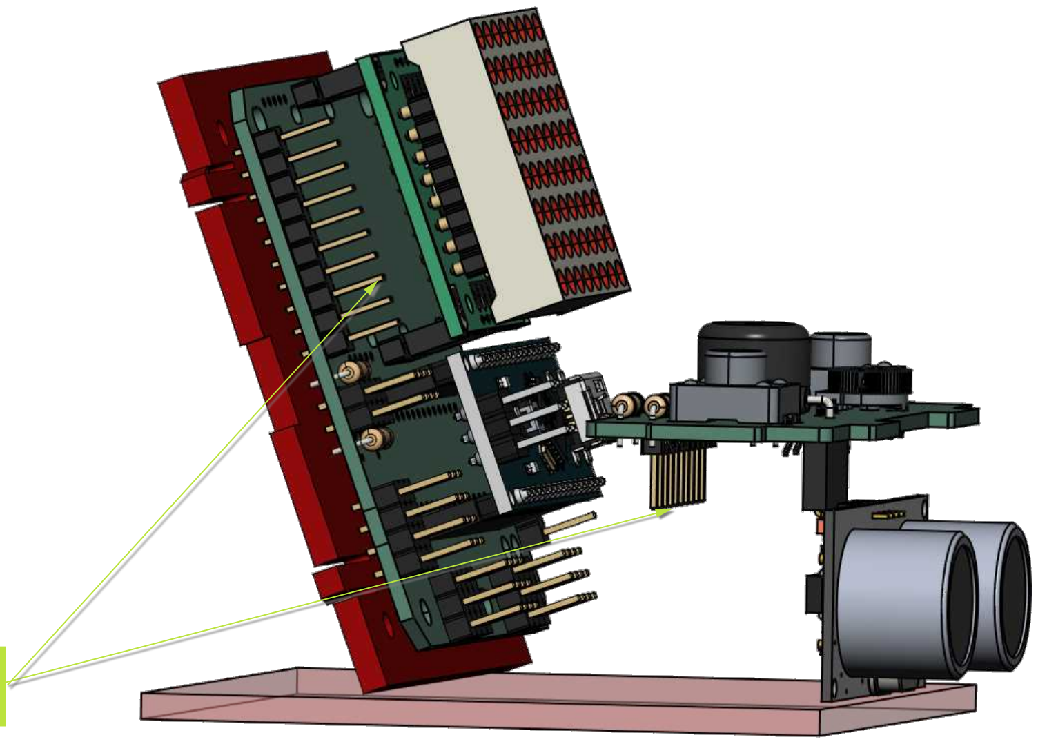
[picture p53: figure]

10 pin headers
Connect cable/wires
between main board
and addon board

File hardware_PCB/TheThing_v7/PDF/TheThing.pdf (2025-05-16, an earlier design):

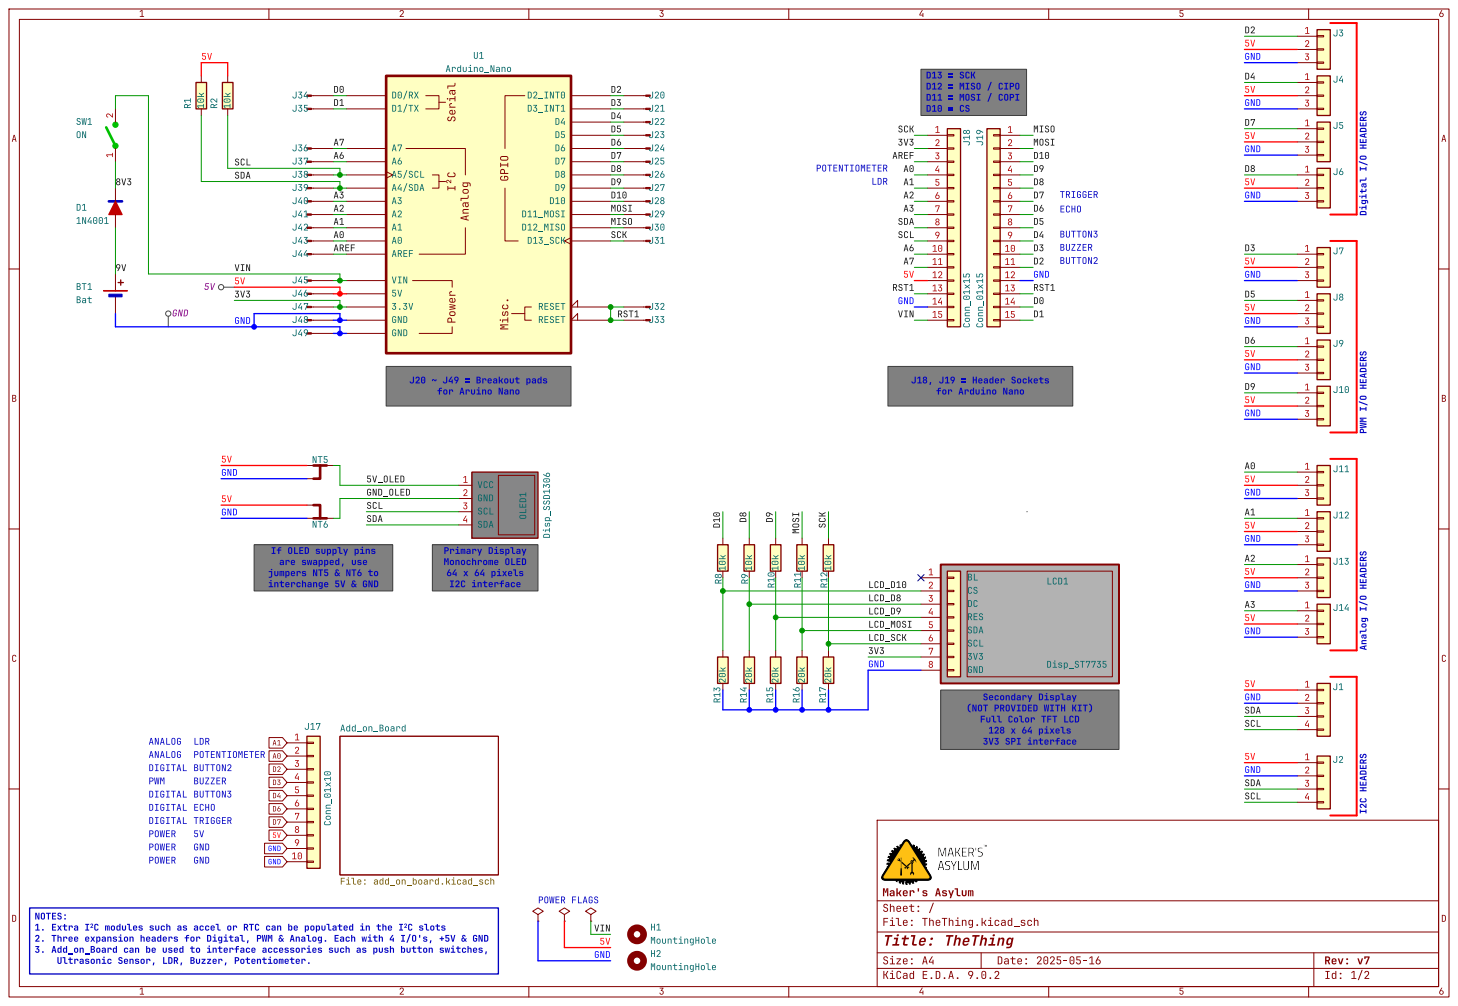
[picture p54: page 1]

LDR
for Arduino Nano Secondary Display

If OLED supply pins
are swapped, use
jumpers NT5 & NT6 to

Primary Display Monochrome OLED

3V3 NOTES: 1. Extra I^{2}Cmodules such as accel or RTC can be populated in the I^{2}Cslots

(NOT PROVIDED WITH KIT) Full Color TFT LCD

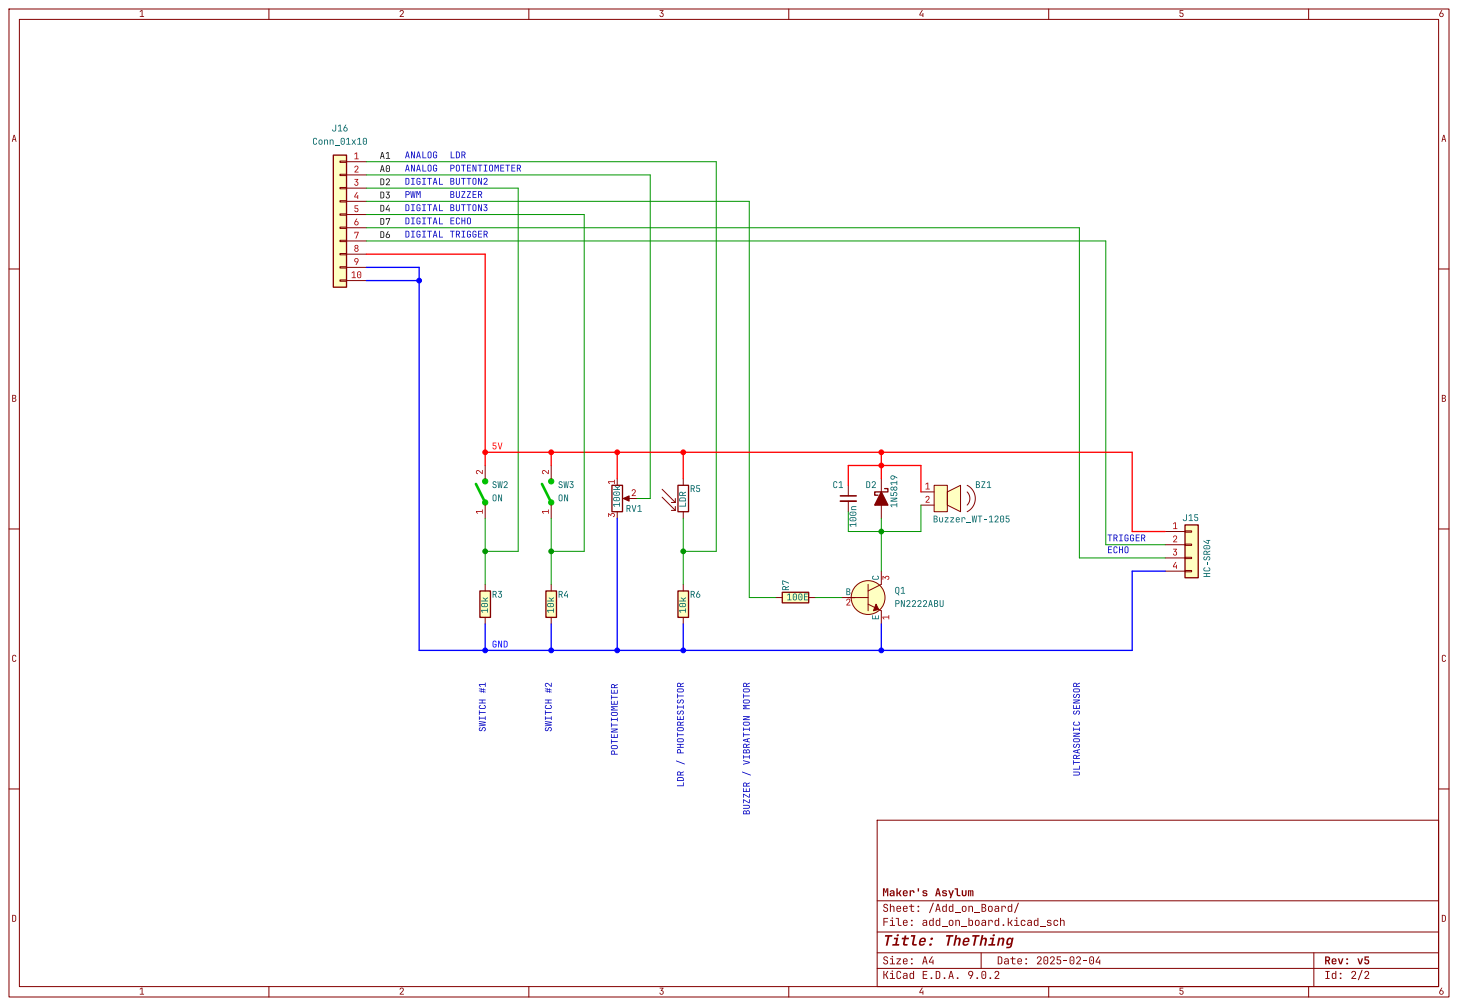
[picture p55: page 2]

BUTTON3 DIGITAL ECHO

TRIGGER

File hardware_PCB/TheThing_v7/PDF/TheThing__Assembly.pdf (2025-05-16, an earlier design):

12.0 mm | 29.6 mm ¹².0 mm
OLED1 | J19 RV1

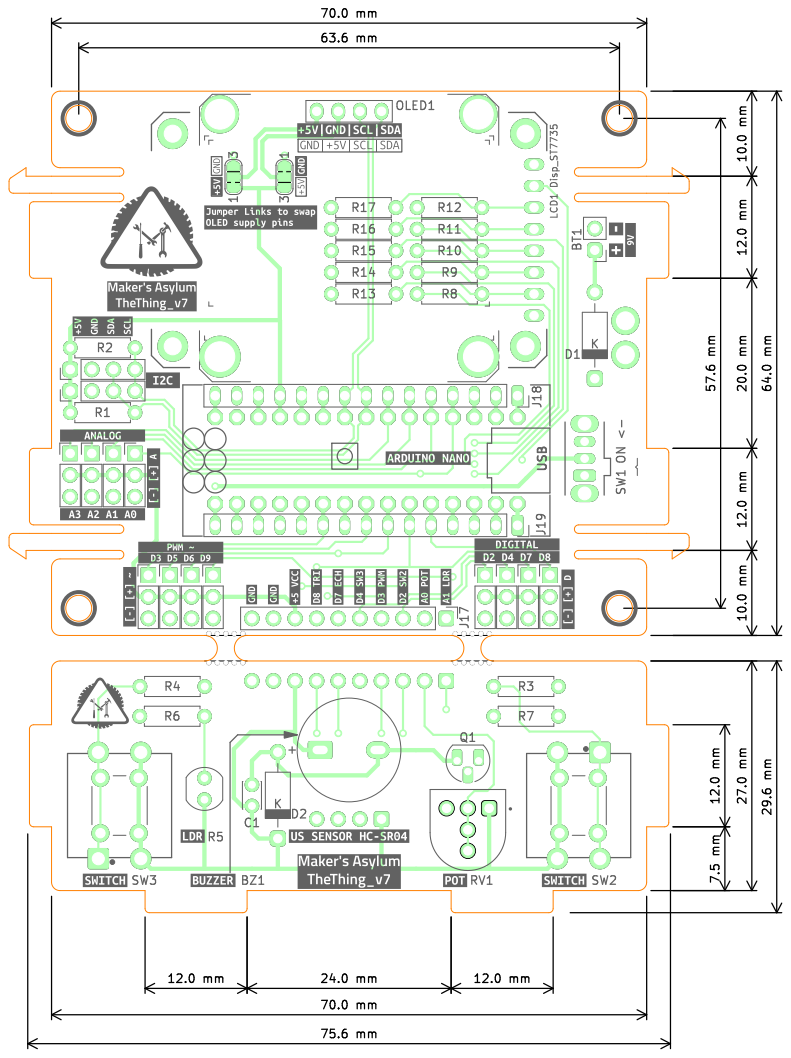
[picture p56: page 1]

File: TheThing.kicad_pcb Sheet: Colored-TOP Maker's Asylum

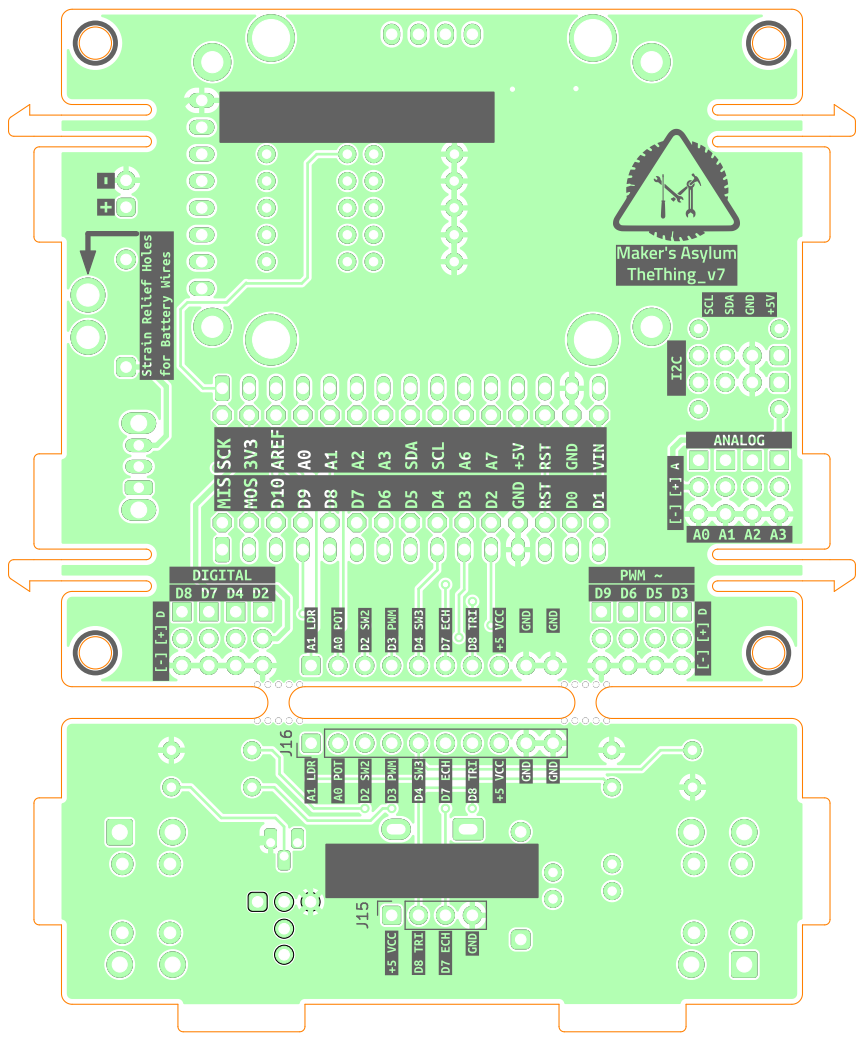
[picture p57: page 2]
D Date: 2025-05-16 KiCad; E.D.A. 9.0.2 Size: A4; Rev: v7; Board2Pdf:; Colored-BOT; Page 2/2 J15 J16

File: TheThing.kicad_pcb Sheet: Colored-BOT Maker's Asylum

Id: /1 Title: TheThing

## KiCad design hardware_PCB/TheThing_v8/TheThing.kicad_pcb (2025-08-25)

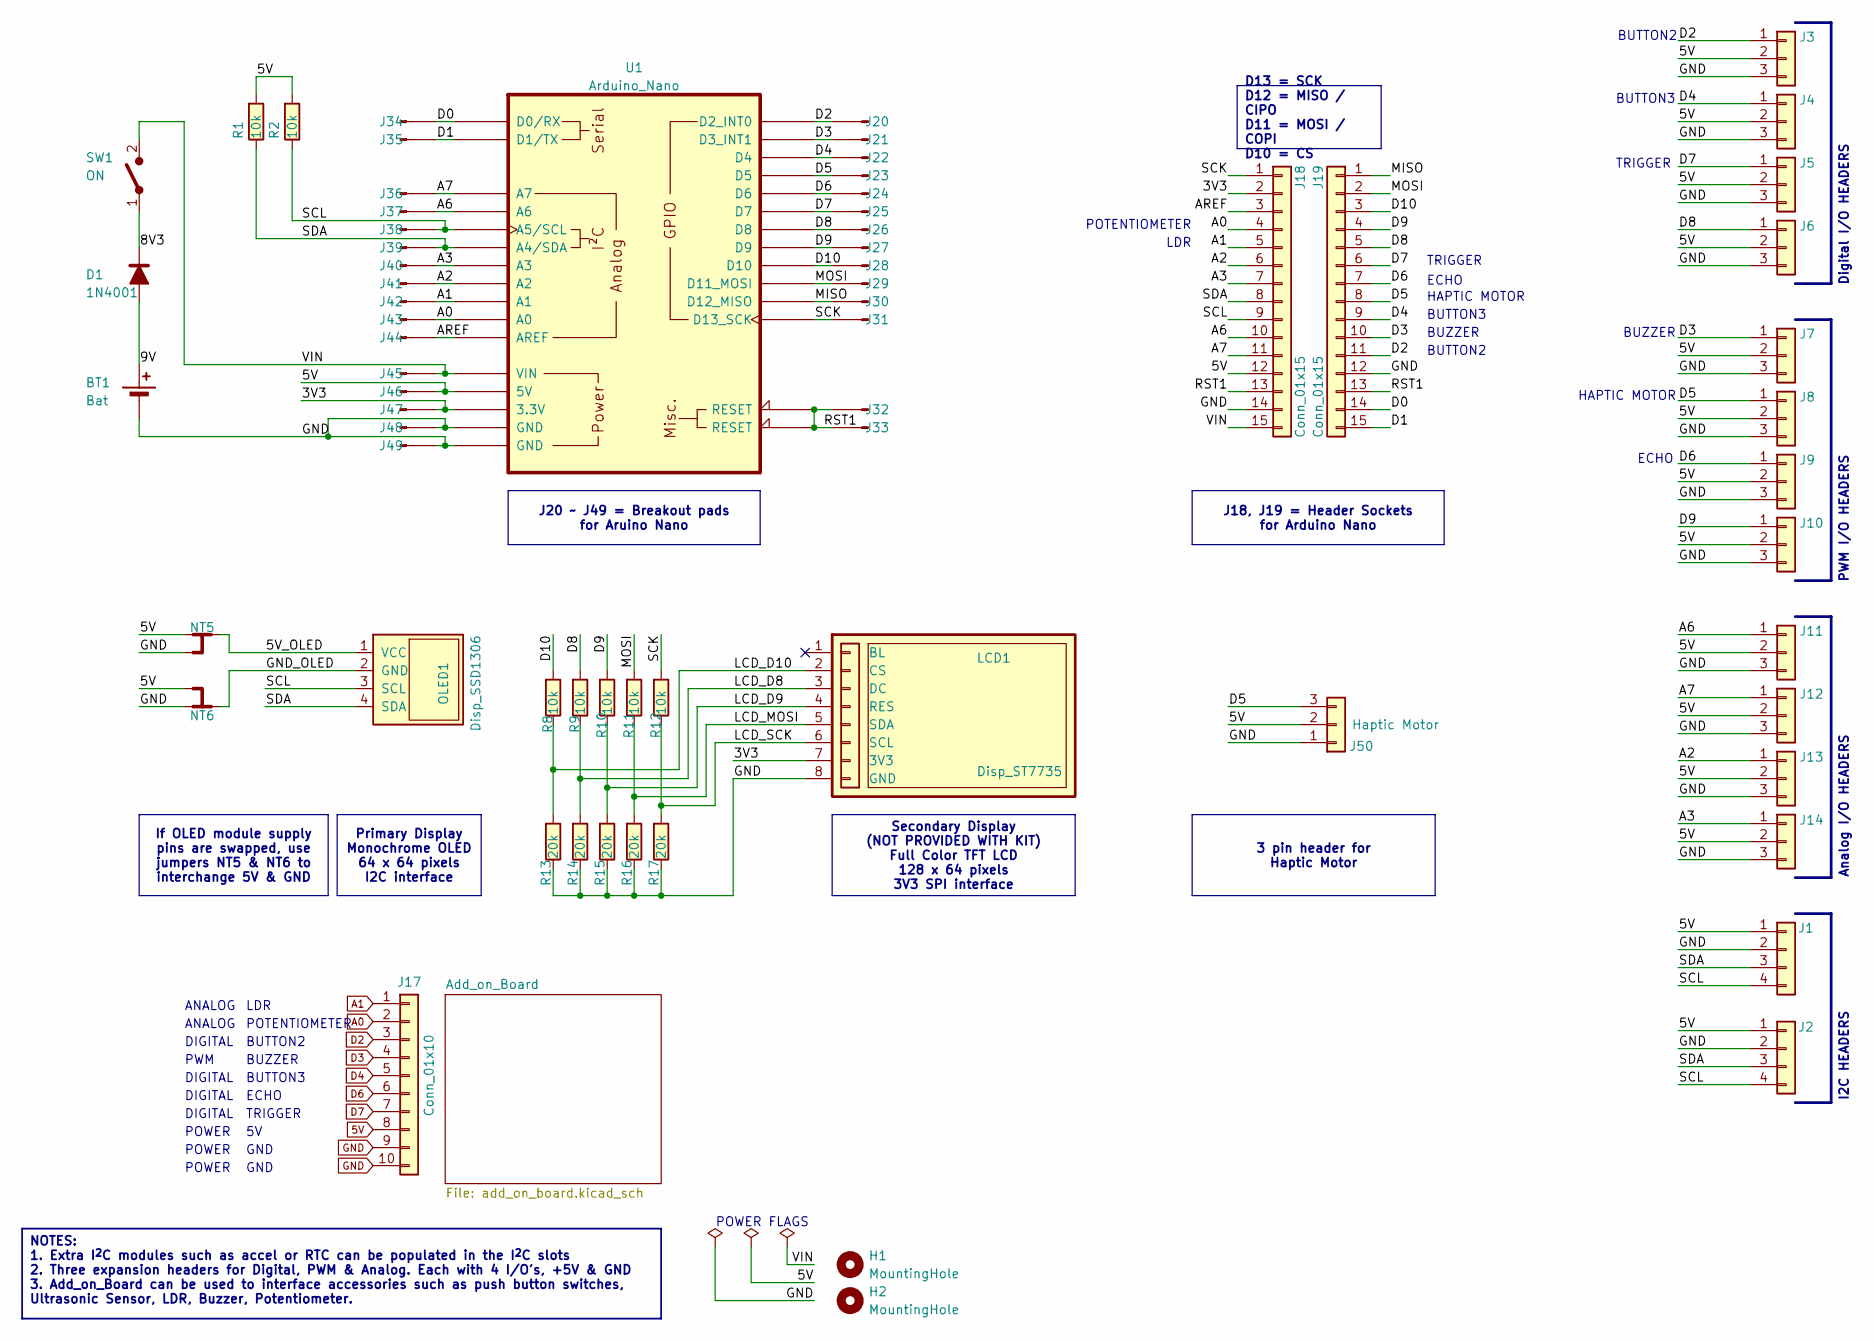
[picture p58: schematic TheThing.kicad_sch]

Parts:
BT1: Bat; PinHeader_1x02_P2.54mm_Horizontal
D1: 1N4001; D_DO-41_SOD81_P10.16mm_Horizontal
H1, H2: MountingHole; MountingHole_4.3mm_M4
J1, J2: Conn_I2C; PinHeader_1x04_P2.54mm_Vertical
J3, J4, J5, J6, J7, J8, J9, J10, J11, J12, J13, J14: Conn_01x03; PinHeader_1x03_P2.54mm_Vertical
J17: Conn_01x10; PinHeader_1x10_P2.54mm_Vertical
J18, J19: Conn_01x15; PinSocket_1x15_P2.54mm_Vertical
J20: D2; PinHeader_1x01_P2.54mm_Vertical
J21: D3; PinHeader_1x01_P2.54mm_Vertical
J22: D4; PinHeader_1x01_P2.54mm_Vertical
J23: D5; PinHeader_1x01_P2.54mm_Vertical
J24: D6; PinHeader_1x01_P2.54mm_Vertical
J25: D7; PinHeader_1x01_P2.54mm_Vertical
J26: D8; PinHeader_1x01_P2.54mm_Vertical
J27: D9; PinHeader_1x01_P2.54mm_Vertical
J28: D10; PinHeader_1x01_P2.54mm_Vertical
J29: D11; PinHeader_1x01_P2.54mm_Vertical
J30: D12; PinHeader_1x01_P2.54mm_Vertical
J31: D13; PinHeader_1x01_P2.54mm_Vertical
J32, J33: RST1; PinHeader_1x01_P2.54mm_Vertical
J34: D0; PinHeader_1x01_P2.54mm_Vertical
J35: D1; PinHeader_1x01_P2.54mm_Vertical
J36: A7; PinHeader_1x01_P2.54mm_Vertical
J37: A6; PinHeader_1x01_P2.54mm_Vertical
J38: A5; PinHeader_1x01_P2.54mm_Vertical
J39: A4; PinHeader_1x01_P2.54mm_Vertical
J40: A3; PinHeader_1x01_P2.54mm_Vertical
J41: A2; PinHeader_1x01_P2.54mm_Vertical
J42: A1; PinHeader_1x01_P2.54mm_Vertical
J43: A0; PinHeader_1x01_P2.54mm_Vertical
J44: AREF; PinHeader_1x01_P2.54mm_Vertical
J45: VIN; PinHeader_1x01_P2.54mm_Vertical
J46: 5V; PinHeader_1x01_P2.54mm_Vertical
J47: 3V3; PinHeader_1x01_P2.54mm_Vertical
J48: GND1; PinHeader_1x01_P2.54mm_Vertical
J49: GND2; PinHeader_1x01_P2.54mm_Vertical
J50: Conn_01x03; PinSocket_1x03_P2.54mm_Horizontal_haptic
LCD1: Disp_ST7735; Disp_TFT_LCD_128x128
NT5, NT6: NetTie_3; SolderJumper-3_P1.3mm_Bridged2Bar12_RoundedPad1.0x1.5mm_Num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
OLED1: Disp_SSD1306; Disp_128x64OLED
R1, R2, R8, R9, R10, R11, R12: 10k; R_Axial_DIN0207_L6.3mm_D2.5mm_P7.62mm_Horizontal
R13, R14, R15, R16, R17: 20k; R_Axial_DIN0207_L6.3mm_D2.5mm_P7.62mm_Horizontal
SW1: ON; SW_CuK_OS102011MA1QN1_SPDT_Angled
U1: Arduino_Nano; Arduino_Nano_v2_NoSPI

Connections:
5V: J1.1, J2.1, J3.2, J4.2, J5.2, J6.2, J7.2, J8.2, J9.2, J10.2, J11.2, J12.2, J13.2, J14.2, J17.8, J18.12, J46.1, J50.2, NT5.1, NT6.3, R1.1, R2.1, U1.5V
/3V3: J18.2, J47.1, LCD1.7 (3V3), U1.3V3 (3.3V)
/5V_OLED: NT5.2, OLED1.1 (VCC)
/8V3: D1.1 (K), SW1.1 (A)
/9V: BT1.1 (+), D1.2 (A)
/A2: J13.1, J18.6, J41.1, U1.A2
/A3: J14.1, J18.7, J40.1, U1.A3
/A6: J11.1, J18.10, J37.1, U1.A6
/A7: J12.1, J18.11, J36.1, U1.A7
/AREF: J18.3, J44.1, U1.AREF
/D0: J19.14, J34.1, U1.D0 (D0/RX)
/D1: J19.15, J35.1, U1.D1 (D1/TX)
/D5: J8.1, J19.8, J23.1, J50.3, U1.D5
/D8: J6.1, J19.5, J26.1, R9.1, U1.D8
/D9: J10.1, J19.4, J27.1, R10.1, U1.D9
/D10: J19.3, J28.1, R8.1, U1.D10
/GND_OLED: NT6.2, OLED1.2 (GND)
/LCD_D8: LCD1.3 (DC), R9.2, R14.1
/LCD_D9: LCD1.4 (RES), R10.2, R15.1
/LCD_D10: LCD1.2 (CS), R8.2, R13.1
/LCD_MOSI: LCD1.5 (SDA), R11.2, R16.1
/LCD_SCK: LCD1.6 (SCL), R12.2, R17.1
/MISO: J19.1, J30.1, U1.D12 (D12_MISO)
/MOSI: J19.2, J29.1, R11.1, U1.D11 (D11_MOSI)
/RST1: J18.13, J19.13, J32.1, J33.1, U1.RST1 (RESET), U1.RST2 (RESET)
/SCK: J18.1, J31.1, R12.1, U1.D13 (D13_SCK)
/SCL: J1.4, J2.4, J18.9, J38.1, OLED1.3 (SCL), R2.2, U1.A5 (A5/SCL)
/SDA: J1.3, J2.3, J18.8, J39.1, OLED1.4 (SDA), R1.2, U1.A4 (A4/SDA)
/VIN: J18.15, J45.1, SW1.2 (B), U1.VIN
A0: J17.2, J18.4, J43.1, U1.A0
A1: J17.1, J18.5, J42.1, U1.A1
D2: J3.1, J17.3, J19.11, J20.1, U1.D2 (D2_INT0)
D3: J7.1, J17.4, J19.10, J21.1, U1.D3 (D3_INT1)
D4: J4.1, J17.5, J19.9, J22.1, U1.D4
D6: J9.1, J17.6, J19.7, J24.1, U1.D6
D7: J5.1, J17.7, J19.6, J25.1, U1.D7
GND: BT1.2 (-), J1.2, J2.2, J3.3, J4.3, J5.3, J6.3, J7.3, J8.3, J9.3, J10.3, J11.3, J12.3, J13.3, J14.3, J17.9, J17.10, J18.14, J19.12, J48.1, J49.1, J50.1, LCD1.8 (GND), NT5.3, NT6.1, R13.2, R14.2, R15.2, R16.2, R17.2, U1.GND1 (GND), U1.GND2 (GND)

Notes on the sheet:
DIGITAL
BUTTON3
POWER
TRIGGER
BUZZER
Digital I/O HEADERS
I2C HEADERS
POTENTIOMETER
LDR
POWER FLAGS
PWM
ECHO
PWM I/O HEADERS
ANALOG
Analog I/O HEADERS
GND
HAPTIC MOTOR
BUTTON2
Primary Display Monochrome OLED 64 x 64 pixels I2C interface
D13 = SCK D12 = MISO / CIPO D11 = MOSI / COPI D10 = CS
J18, J19 = Header Sockets for Arduino Nano
3 pin header for Haptic Motor
Secondary Display (NOT PROVIDED WITH KIT) Full Color TFT LCD 128 x 64 pixels 3V3 SPI interface
NOTES: 1. Extra I^{2}C modules such as accel or RTC can be populated in the I^{2}C slots 2. Three expansion headers for Digital, PWM & Analog. Each with 4 I/O's, +5V & GND 3. Add_on_Board can be used to interface accessories such as push button switches, Ultrasonic Sensor, LDR, Buzzer, Potentiomete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
J20 ~ J49 = Breakout pads for Aruino Nano
If OLED module supply pins are swapped, use jumpers NT5 & NT6 to interchange 5V & GND

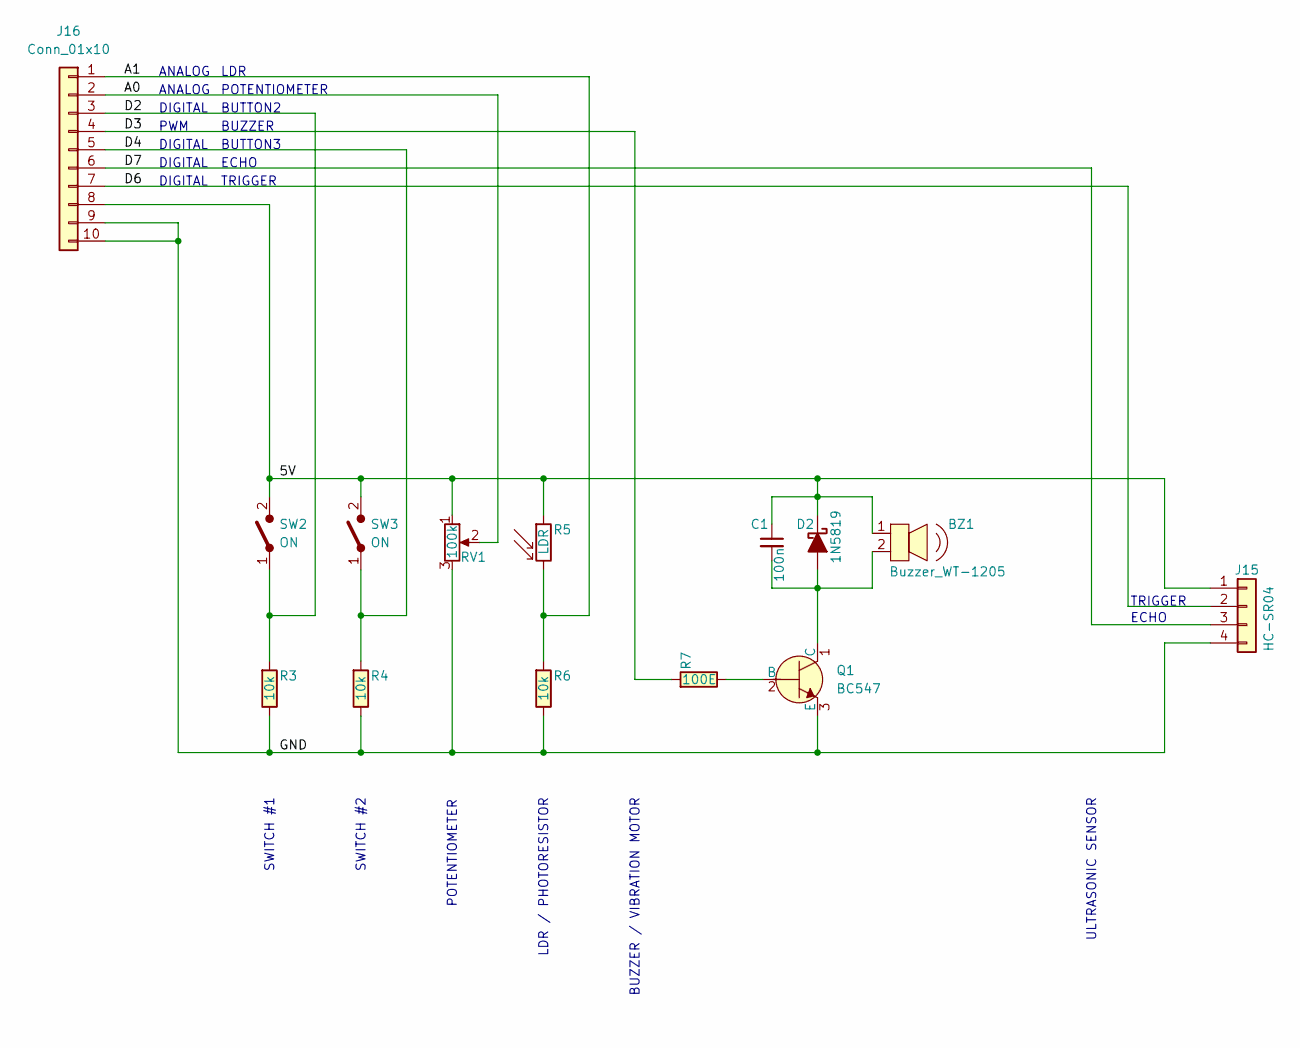
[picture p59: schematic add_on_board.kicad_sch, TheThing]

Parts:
BZ1: Buzzer_WT-1205; Buzzer_12x9.5RM7.6; MPN PS1240P02BT
C1: 100n; C_Disc_D3.0mm_W2.0mm_P2.50mm
D2: 1N5819; D_DO-41_SOD81_P10.16mm_Horizontal
J15: HC-SR04; PinSocket_1x04_P2.54mm_Vertical
J16: Conn_01x10; PinHeader_1x10_P2.54mm_Vertical
Q1: BC547; TO-92_HandSolder; MPN BC547B
R3, R4, R6: 10k; R_Axial_DIN0207_L6.3mm_D2.5mm_P7.62mm_Horizontal
R5: LDR; R_LDR_4.9x4.2mm_P2.54mm_Vertical
R7: 100E; R_Axial_DIN0207_L6.3mm_D2.5mm_P7.62mm_Horizontal
RV1: 100k; TRIM_601040
SW2, SW3: ON; SWITCH_PUSH_6mm_12mm

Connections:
/Add_on_Board/5V: BZ1.1, C1.1, D2.1 (K), J15.1, J16.8, R5.1, RV1.1, SW2.2 (B), SW3.2 (B)
/Add_on_Board/A0: J16.2, RV1.2
/Add_on_Board/A1: J16.1, R5.2, R6.1
/Add_on_Board/D2: J16.3, R3.1, SW2.1 (A)
/Add_on_Board/D3: J16.4, R7.1
/Add_on_Board/D4: J16.5, R4.1, SW3.1 (A)
/Add_on_Board/D6: J15.2, J16.7
/Add_on_Board/D7: J15.3, J16.6
/Add_on_Board/GND: J15.4, J16.9, J16.10, Q1.3 (E), R3.2, R4.2, R6.2, RV1.3
unnamed: BZ1.2, C1.2, D2.2 (A), Q1.1 (C)
unnamed: Q1.2 (B), R7.2

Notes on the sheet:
SWITCH #1
BUZZER / VIBRATION MOTOR
SWITCH #2
ULTRASONIC SENSOR
ANALOG
DIGITAL
PWM
BUZZER
BUTTON2
LDR / PHOTORESISTOR
POTENTIOMETER
ECHO
LDR
BUTTON3
TRIGGER

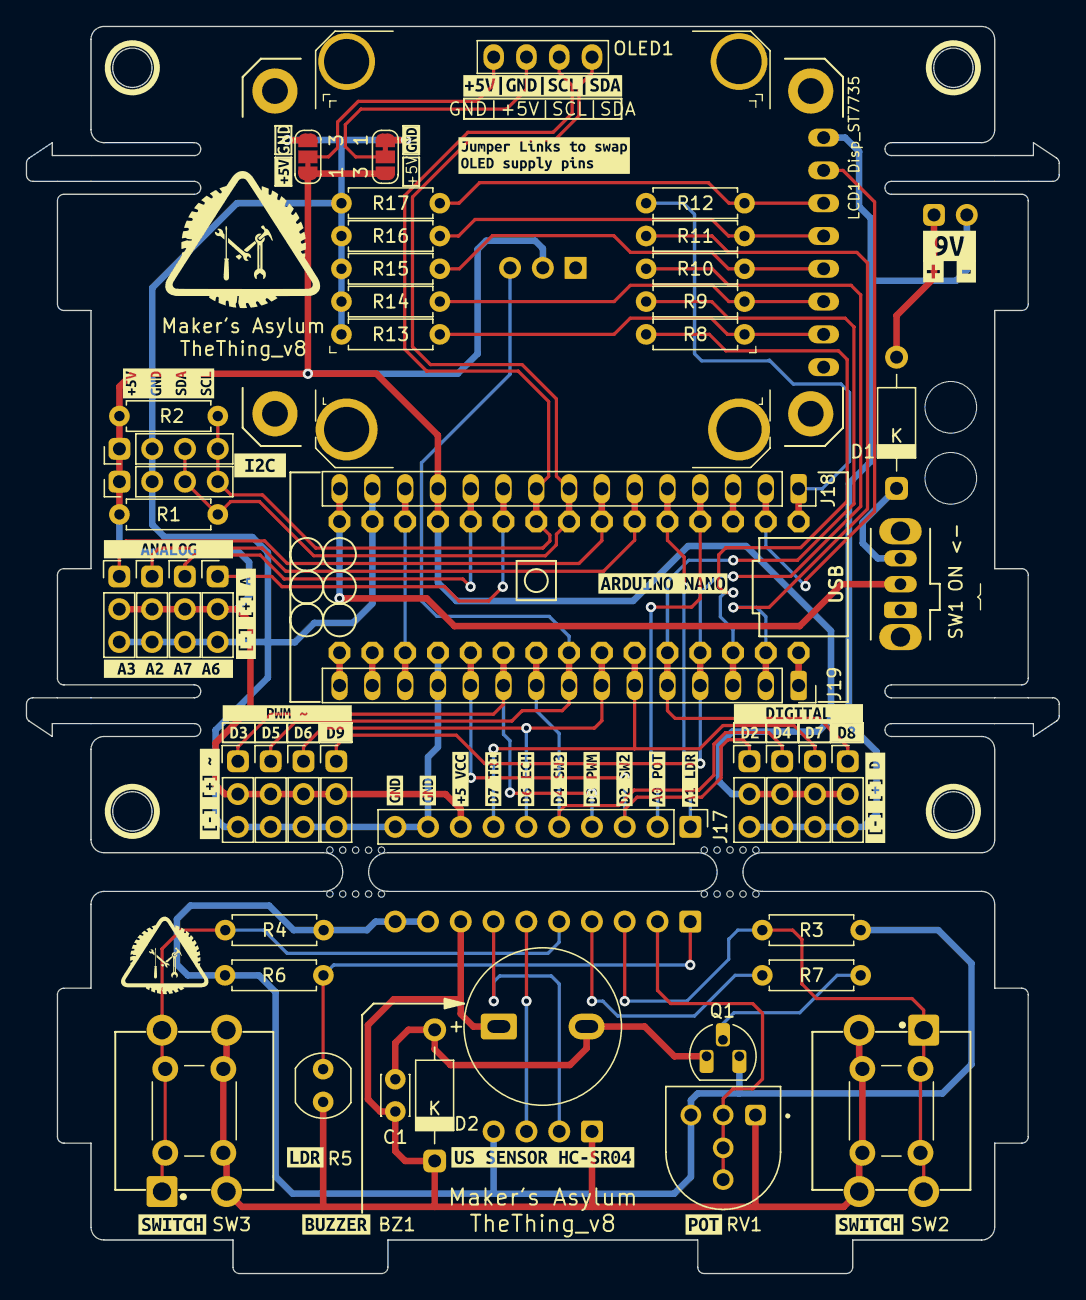
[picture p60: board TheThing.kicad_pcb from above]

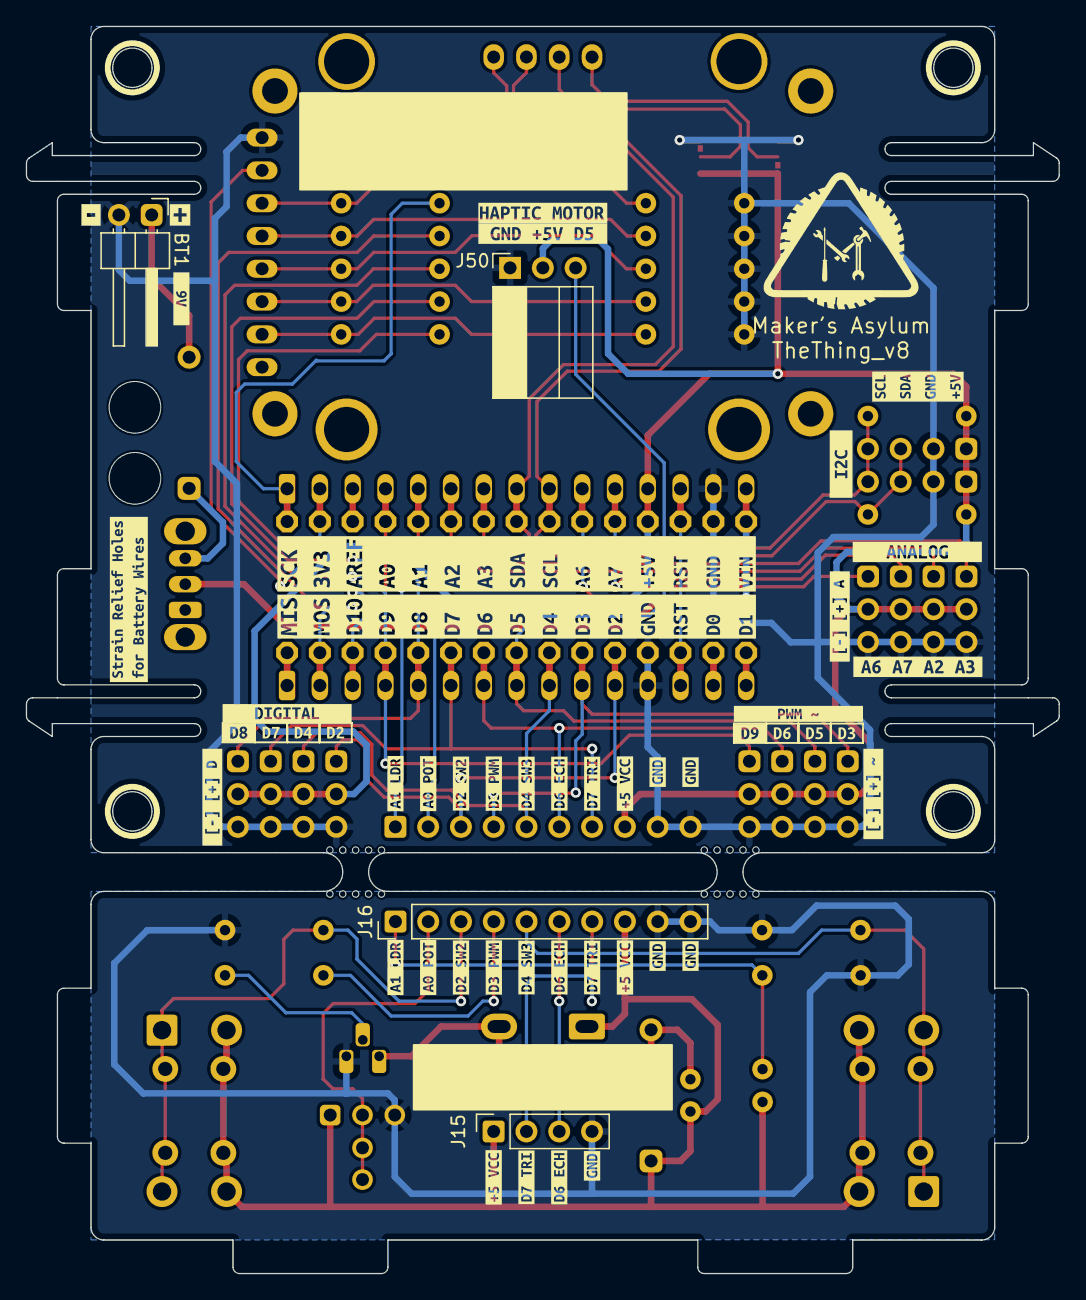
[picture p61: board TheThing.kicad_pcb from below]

Board: 2 copper layers, 80.0 x 96.6 mm, 173 parts (53 on the bottom side), 48 nets.

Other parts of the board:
kibuzzard-67A22DCA: G***; kibuzzard-67A22DCA
kibuzzard-67A22DD3: G***; kibuzzard-67A22DD3
kibuzzard-67A22DDD: G***; kibuzzard-67A22DDD
kibuzzard-67A22DE4: G***; kibuzzard-67A22DE4
kibuzzard-67A22DF7: G***; kibuzzard-67A22DF7
kibuzzard-67A122A3: G***; kibuzzard-67A122A3
kibuzzard-67A122C1: G***; kibuzzard-67A122C1
kibuzzard-67A11942: G***; kibuzzard-67A11942
kibuzzard-67A20273: G***; kibuzzard-67A20273
kibuzzard-681BBDCE: G***; kibuzzard-681BBDCE
kibuzzard-681CE6A6, kibuzzard-681CE6A6#2, kibuzzard-681CE6A6#3: G***; kibuzzard-681CE6A6
kibuzzard-681CE6D9, kibuzzard-681CE6D9#2, kibuzzard-681CE6D9#3: G***; kibuzzard-681CE6D9
kibuzzard-681CE6E0, kibuzzard-681CE6E0#2, kibuzzard-681CE6E0#3: G***; kibuzzard-681CE6E0
kibuzzard-681CE6FF, kibuzzard-681CE6FF#2, kibuzzard-681CE6FF#3: G***; kibuzzard-681CE6FF
kibuzzard-681CE70B, kibuzzard-681CE70B#2, kibuzzard-681CE70B#3: G***; kibuzzard-681CE70B
kibuzzard-681CE705, kibuzzard-681CE705#2, kibuzzard-681CE705#3: G***; kibuzzard-681CE705
kibuzzard-681CE710, kibuzzard-681CE710#2, kibuzzard-681CE710#3: G***; kibuzzard-681CE710
kibuzzard-681CE715, kibuzzard-681CE715#2, kibuzzard-681CE715#3: G***; kibuzzard-681CE715
kibuzzard-681CED7D: G***; kibuzzard-681CED7D
kibuzzard-681CEDBE: G***; kibuzzard-681CEDBE
kibuzzard-681CEE16: G***; kibuzzard-681CEE16
kibuzzard-681CEF1C: G***; kibuzzard-681CEF1C
kibuzzard-681CF111: G***; kibuzzard-681CF111
kibuzzard-681D00EA: G***; kibuzzard-681D00EA
kibuzzard-681D13E1, kibuzzard-681D13E1#2: G***; kibuzzard-681D13E1
kibuzzard-681D14E6, kibuzzard-681D14E6#2: G***; kibuzzard-681D14E6
kibuzzard-681D0124: G***; kibuzzard-681D0124
kibuzzard-681D1422: G***; kibuzzard-681D1422
kibuzzard-687E01B3: G***; kibuzzard-687E01B3
kibuzzard-687E01EA: G***; kibuzzard-687E01EA
kibuzzard-687E01F5: G***; kibuzzard-687E01F5
kibuzzard-687E12B6: G***; kibuzzard-687E12B6
kibuzzard-687E019A: G***; kibuzzard-687E019A
kibuzzard-687E020C: G***; kibuzzard-687E020C
kibuzzard-687E0202: G***; kibuzzard-687E0202
kibuzzard-687E1831: G***; kibuzzard-687E1831
kibuzzard-688B0B7B, kibuzzard-688B0B7B#2: G***; kibuzzard-688B0B7B
kibuzzard-688B0B80, kibuzzard-688B0B80#2: G***; kibuzzard-688B0B80
kibuzzard-688B0B86, kibuzzard-688B0B86#2: G***; kibuzzard-688B0B86
kibuzzard-688B0CB0, kibuzzard-688B0CB0#2: G***; kibuzzard-688B0CB0
kibuzzard-688B1C9E: G***; kibuzzard-688B1C9E
kibuzzard-688B4A2D: G***; kibuzzard-688B4A2D
kibuzzard-688B04F2: G***; kibuzzard-688B04F2
kibuzzard-688B05AD: G***; kibuzzard-688B05AD
kibuzzard-688B06AA, kibuzzard-688B06AA#2: G***; kibuzzard-688B06AA
kibuzzard-688B07C0, kibuzzard-688B07C0#2: G***; kibuzzard-688B07C0
kibuzzard-688B07DB, kibuzzard-688B07DB#2: G***; kibuzzard-688B07DB
kibuzzard-688B10BE: G***; kibuzzard-688B10BE
kibuzzard-688B11B5: G***; kibuzzard-688B11B5
kibuzzard-688B11BF: G***; kibuzzard-688B11BF
kibuzzard-688B21F2: G***; kibuzzard-688B21F2
kibuzzard-688B068F, kibuzzard-688B068F#2: G***; kibuzzard-688B068F
kibuzzard-6640C3B8: G***; kibuzzard-6640C3B8
kibuzzard-64612FA6, kibuzzard-64612FA6#2: G***; kibuzzard-64612FA6
kibuzzard-64612FED, kibuzzard-64612FED#2: G***; kibuzzard-64612FED
kibuzzard-68220AD1: G***; kibuzzard-68220AD1
kibuzzard-682711E3: G***; kibuzzard-682711E3
kibuzzard-682712AE: G***; kibuzzard-682712AE
kibuzzard-6461376B: G***; kibuzzard-6461376B
kibuzzard-6461377A: G***; kibuzzard-6461377A
kibuzzard-6827114F: G***; kibuzzard-6827114F
kibuzzard-68271661: G***; kibuzzard-68271661

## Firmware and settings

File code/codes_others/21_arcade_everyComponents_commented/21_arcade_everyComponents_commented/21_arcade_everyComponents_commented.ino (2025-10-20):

/*
This code is part of the ARCADE project for the "Electronics and Microcontrollers" skill of INNOVATION SCHOOL at MAKERS ASYLUM
Copyright : 2025 Maker's Asylum | makersasylum.com
License : MIT

Summary of what this code does:

Displays a menu on an OLED using U8glib to select hardware components to test.
Uses two buttons for input and a potentiometer for menu navigation.
Includes tests for buttons, buzzer, LDR, potentiometer, ultrasonic sensor, and haptic motor.
Each test mode has a custom OLED animation and an exit condition (pressing both buttons).
Uses PWM control for the haptic motor and analog/digital readings for the rest.
*/

// Include the U8glib library for controlling the OLED display
#include <U8glib.h>

// --- Pin Definitions ---
#define POT_PIN A0        // Potentiometer connected to analog pin A0
#define BUTTON1_PIN 4     // Button 1 input pin
#define BUTTON2_PIN 2     // Button 2 input pin
#define BUZZER_PIN 3      // Buzzer output pin
#define LDR_PIN A1        // Light-dependent resistor (LDR) analog input pin
#define TRIG_PIN 7        // Ultrasonic sensor trigger pin
#define ECHO_PIN 6        // Ultrasonic sensor echo pin
#define MOTOR_PIN 5       // Haptic vibration motor controlled by PWM signal

// --- State Variables ---
bool inHapticTest = false;  // Keeps track if the user is currently in haptic motor test mode
int level = 0;              // Represents motor intensity level (0–4 signal bars)

// Initialize the OLED display using U8glib library
// This particular display is a SH1106 128x64 OLED using I2C interface
U8GLIB_SH1106_128X64 u8g(U8G_I2C_OPT_NONE);

// Menu items displayed on the OLED
const char* menuItems[] = {
  "1. Button", 
  "2. Buzzer", 
  "3. LDR", 
  "4. Pot", 
  "5. Ultra", 
  "6. Haptic"
};
const int totalItems = 6;   // Number of menu items

int selectedItem = 0;       // Keeps track of which menu item is currently selected
bool inMenu = true;         // Flag: true if currently in menu screen
bool inButtonTest = false;  // Individual test mode flags
bool inBuzzerTest = false;
bool inLDRTest = false;
bool inPotTest = false;
bool inUltraTest = false;

// -------------------- SETUP --------------------
void setup() {
  // Configure all the input/output pins
  pinMode(BUTTON1_PIN, INPUT);
  pinMode(BUTTON2_PIN, INPUT);
  pinMode(LDR_PIN, INPUT);
  pinMode(BUZZER_PIN, OUTPUT);
  digitalWrite(BUZZER_PIN, LOW); // Make sure the buzzer starts OFF
  pinMode(TRIG_PIN, OUTPUT);
  pinMode(ECHO_PIN, INPUT);
}

// -------------------- MAIN LOOP --------------------
void loop() {

  // --- MENU SCREEN ---
  if (inMenu) {
    // Continuously update menu selection based on potentiometer value
    updateSelection();

    // Start drawing menu on OLED
    u8g.firstPage();
    do {
      drawMenu();   // Display all menu items with selection indicator
    } while (u8g.nextPage());

    // Check if any button was pressed to select a menu option
    if (buttonPressedOnce()) {
      // Determine which test to enter based on current selection
      if (selectedItem == 0) {
        inMenu = false; inButtonTest = true;
      } else if (selectedItem == 1) {
        inMenu = false; inBuzzerTest = true;
      } else if (selectedItem == 2) {
        inMenu = false; inLDRTest = true;
      } else if (selectedItem == 3) {
        inMenu = false; inPotTest = true;
      } else if (selectedItem == 4) {
        inMenu = false; inUltraTest = true;
      } else if (selectedItem == 5) {  // Haptic test option
        inMenu = false; inHapticTest = true;
      }
    }
  }

  // --- BUTTON TEST MODE ---
  else if (inButtonTest) {
    drawButtonTest(); // Draw button visualizer
    // Exit condition: both buttons pressed together
    if (digitalRead(BUTTON1_PIN) == HIGH && digitalRead(BUTTON2_PIN) == HIGH) {
      delay(300);
      // Wait until both are released to prevent accidental triggers
      while (digitalRead(BUTTON1_PIN) == HIGH || digitalRead(BUTTON2_PIN) == HIGH);
      inMenu = true;
      inButtonTest = false;
    }
  }

  // --- BUZZER TEST MODE ---
  else if (inBuzzerTest) {
    drawBuzzerTest(); // Draw buzzer symbol on screen

    // Turn buzzer ON when either button is pressed
    if (digitalRead(BUTTON1_PIN) == HIGH || digitalRead(BUTTON2_PIN) == HIGH) {
      digitalWrite(BUZZER_PIN, HIGH);
    } else {
      digitalWrite(BUZZER_PIN, LOW);
    }

    // Exit if both buttons pressed
    if (digitalRead(BUTTON1_PIN) == HIGH && digitalRead(BUTTON2_PIN) == HIGH) {
      delay(300);
      while (digitalRead(BUTTON1_PIN) == HIGH || digitalRead(BUTTON2_PIN) == HIGH);
      digitalWrite(BUZZER_PIN, LOW); // Ensure buzzer stops
      inMenu = true;
      inBuzzerTest = false;
    }
  }

  // --- LDR TEST MODE ---
  else if (inLDRTest) {
    drawLDRTest(); // Display light sensor visualization
    if (digitalRead(BUTTON1_PIN) == HIGH && digitalRead(BUTTON2_PIN) == HIGH) {
      delay(300);
      while (digitalRead(BUTTON1_PIN) == HIGH || digitalRead(BUTTON2_PIN) == HIGH);
      inMenu = true;
      inLDRTest = false;
    }
  }

  // --- POTENTIOMETER TEST MODE ---
  else if (inPotTest) {
    drawPotTest(); // Show spiral animation responding to potentiometer
    if (digitalRead(BUTTON1_PIN) == HIGH && digitalRead(BUTTON2_PIN) == HIGH) {
      delay(300);
      while (digitalRead(BUTTON1_PIN) == HIGH || digitalRead(BUTTON2_PIN) == HIGH);
      inMenu = true;
      inPotTest = false;
    }
  }

  // --- ULTRASONIC TEST MODE ---
  else if (inUltraTest) {
    drawUltraTest(); // Show distance with moving car animation
    if (digitalRead(BUTTON1_PIN) == HIGH && digitalRead(BUTTON2_PIN) == HIGH) {
      delay(300);
      while (digitalRead(BUTTON1_PIN) == HIGH || digitalRead(BUTTON2_PIN) == HIGH);
      inMenu = true;
      inUltraTest = false;
    }
  }

  // --- HAPTIC MOTOR TEST MODE ---
  else if (inHapticTest) {
    drawHapticTest(); // Display signal bar visualization for motor strength

    // Increase intensity with button 2
    if (digitalRead(BUTTON2_PIN) == HIGH) {
      level++;
      if (level > 4) level = 4;  // Cap at max level
    }

    // Decrease intensity with button 1
    if (digitalRead(BUTTON1_PIN) == HIGH) {
      level--;
      if (level < 0) level = 0;  // Limit to zero
    }

    // Map level to PWM values for smooth control
    int pwmValue = 0;
    switch (level) {
      case 0: pwmValue = 0; break;
      case 1: pwmValue = 64; break;
      case 2: pwmValue = 128; break;
      case 3: pwmValue = 192; break;
      case 4: pwmValue = 255; break;
    }
    analogWrite(MOTOR_PIN, pwmValue); // Apply PWM signal to motor

    // Exit if both buttons are pressed simultaneously
    if (digitalRead(BUTTON1_PIN) == HIGH && digitalRead(BUTTON2_PIN) == HIGH) {
      delay(300);
      while (digitalRead(BUTTON1_PIN) == HIGH || digitalRead(BUTTON2_PIN) == HIGH);
      analogWrite(MOTOR_PIN, 0); // Turn off motor
      inMenu = true;
      inHapticTest = false;
    }
  }

  // Small delay to reduce flickering and debounce minor input noise
  delay(100);
}

// -------------------- FUNCTION DEFINITIONS --------------------

// Reads potentiometer value and maps it to one of the menu items
void updateSelection() {
  int potValue = 1023 - analogRead(POT_PIN); // Reverse direction of knob movement
  int bandSize = 1024 / totalItems;          // Divide 1024 range into equal sections
  selectedItem = potValue / bandSize;        // Determine which menu item is active
  if (selectedItem >= totalItems) selectedItem = totalItems - 1;
}

// Draws the main menu with selection arrow
void drawMenu() {
  u8g.setFont(u8g_font_6x10);
  u8g.drawStr(0, 8, "Select Component:");
  for (int i = 0; i < totalItems; i++) {
    if (i == selectedItem) {
      u8g.drawStr(0, 18 + i * 9, ">");     // Draw arrow for current selection
    }
    u8g.drawStr(10, 18 + i * 9, menuItems[i]);
  }
}

// Detects a single press (edge detection)
bool buttonPressedOnce() {
  static bool lastState = LOW;
  bool current = (digitalRead(BUTTON1_PIN) == HIGH || digitalRead(BUTTON2_PIN) == HIGH);

  if (current && !lastState) {   // Button transitioned from LOW to HIGH
    lastState = true;
    delay(20);                   // Small debounce delay
    return true;
  } else if (!current) {
    lastState = false;
  }
  return false;
}

// Button test: visualize buttons as circles that grow when pressed
void drawButtonTest() {
  u8g.firstPage();
  do {
    u8g.setFont(u8g_font_6x10);
    u8g.drawStr(20, 10, "Press any Button");

    int x1 = 40, y1 = 40;   // Position for Button 1
    int x2 = 90, y2 = 40;   // Position for Button 2

    // Button 1 visual indicator
    if (digitalRead(BUTTON1_PIN) == HIGH)
      u8g.drawDisc(x1, y1, 12);  // Larger circle when pressed
    else
      u8g.drawDisc(x1, y1, 5);   // Small circle when not pressed

    // Button 2 visual indicator
    if (digitalRead(BUTTON2_PIN) == HIGH)
      u8g.drawDisc(x2, y2, 12);
    else
      u8g.drawDisc(x2, y2, 5);

  } while (u8g.nextPage());
}

// Buzzer test: draw buzzer symbol and animate when ON
void drawBuzzerTest() {
  u8g.firstPage();
  do {
    u8g.setFont(u8g_font_6x10);
    u8g.drawStr(15, 10, "Press any Button");

    u8g.drawTriangle(30, 30, 30, 50, 45, 40);  // Speaker shape

    // When button is pressed, show sound waves
    if (digitalRead(BUTTON1_PIN) == HIGH || digitalRead(BUTTON2_PIN) == HIGH) {
      digitalWrite(BUZZER_PIN, HIGH);
      u8g.drawCircle(50, 40, 5);
      u8g.drawCircle(55, 40, 8);
      u8g.drawCircle(60, 40, 11);
    } else {
      digitalWrite(BUZZER_PIN, LOW);
      // Draw “X” over speaker when OFF
      u8g.drawLine(48, 30, 60, 50);
      u8g.drawLine(48, 50, 60, 30);
    }

  } while (u8g.nextPage());
}

// LDR test: draws a light bulb glowing proportionally to detected light
void drawLDRTest() {
  int ldrValue = analogRead(LDR_PIN);           // Read light intensity
  int glowLevel = map(ldrValue, 0, 1023, 0, 10); // Map to number of glow lines

  u8g.firstPage();
  do {
    u8g.setFont(u8g_font_6x10);
    u8g.drawStr(35, 10, "LDR Sensor");

    int cx = 64, cy = 50;
    u8g.drawCircle(cx, cy, 8);             // Bulb outline
    u8g.drawLine(cx, cy + 8, cx, cy + 14); // Bulb base line
    u8g.drawLine(cx - 5, cy + 14, cx + 5, cy + 14); // Base bottom

    // Draw glow lines increasing with light intensity
    for (int i = 0; i < glowLevel; i++) {
      int y = cy - 5 - i * 2;
      int w = 4 + i * 2;
      u8g.drawLine(cx - w, y, cx + w, y);
    }

  } while (u8g.nextPage());
}

// Potentiometer test: draws a spiral with a ball moving along it
void drawPotTest() {
  int potValue = analogRead(POT_PIN);
  float t = map(potValue, 0, 1023, 0, 180);  // Ball position on spiral path

  u8g.firstPage();
  do {
    u8g.setFont(u8g_font_6x10);
    u8g.drawStr(35, 10, "Pot Spiral");

    int cx = 64, cy = 35;      // Spiral center point
    float angleStep = 0.08;    // Controls spiral smoothness
    float a = 1.8;             // Controls how tightly spiral grows

    // Draw mirrored spiral pattern
    for (float theta = 0; theta < angleStep * 180; theta += angleStep) {
      float r = a * theta;
      int x = cx - r * cos(theta);
      int y = cy + r * sin(theta);
      u8g.drawPixel(x, y);
    }

    // Draw moving ball showing potentiometer position
    float ballTheta = angleStep * t;
    float rBall = a * ballTheta;
    int ballX = cx - rBall * cos(ballTheta);
    int ballY = cy + rBall * sin(ballTheta);
    u8g.drawCircle(ballX, ballY, 2);

  } while (u8g.nextPage());
}

// Ultrasonic test: visual car moves based on distance
void drawUltraTest() {
  // Trigger ultrasonic sensor pulse
  digitalWrite(TRIG_PIN, LOW); delayMicroseconds(2);
  digitalWrite(TRIG_PIN, HIGH); delayMicroseconds(10);
  digitalWrite(TRIG_PIN, LOW);

  // Measure pulse duration and convert to distance (cm)
  long duration = pulseIn(ECHO_PIN, HIGH);
  int distance = duration / 58;

  int roadY = 50;
  int carX = -20;  // Default off-screen

  // Map measured distance to car position
  if (distance >= 3 && distance <= 18) {
    carX = map(distance, 18, 3, 0, 100); // Near = right side, far = left
  }

  u8g.firstPage();
  do {
    u8g.setFont(u8g_font_6x10);
    u8g.drawStr(30, 10, "Ultra Sensor");

    // Draw ground line
    u8g.drawLine(0, roadY, 128, roadY);

    // Draw car only when within valid detection range
    if (distance >= 3 && distance <= 18) {
      u8g.drawBox(carX, roadY - 8, 18, 6);            // Car body
      u8g.drawFrame(carX + 3, roadY - 12, 10, 4);     // Roof
      u8g.drawLine(carX + 3, roadY - 8, carX + 3, roadY - 12);
      u8g.drawLine(carX + 13, roadY - 8, carX + 13, roadY - 12);
      u8g.drawDisc(carX + 4, roadY, 2);               // Wheels
      u8g.drawDisc(carX + 14, roadY, 2);
    }

    // Display numeric distance at bottom
    char buf[10];
    sprintf(buf, "%d cm", distance);
    u8g.drawStr(45, 63, buf);

  } while (u8g.nextPage());
}

// Haptic test: displays bars representing motor strength
void drawHapticTest() {
  u8g.firstPage();
  do {
    u8g.setFont(u8g_font_6x10);
    u8g.drawStr(20, 10, "Haptic Strength");

    // Draw 4 vertical signal bars
    for (int i = 0; i < 4; i++) {
      int barHeight = (i + 1) * 8;
      int x = 40 + i * 12;
      int y = 60 - barHeight;
      if (i < level) {
        u8g.drawBox(x, y, 8, barHeight);   // Filled for active strength
      } else {
        u8g.drawFrame(x, y, 8, barHeight); // Hollow for inactive
      }
    }
  } while (u8g.nextPage());
}

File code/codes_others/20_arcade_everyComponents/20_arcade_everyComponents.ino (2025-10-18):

#include <U8glib.h>

#define POT_PIN A0
#define BUTTON1_PIN 4
#define BUTTON2_PIN 2
#define BUZZER_PIN 3
#define LDR_PIN A1
#define TRIG_PIN 7
#define ECHO_PIN 6
#define MOTOR_PIN 5   // Haptic motor (PWM)

bool inHapticTest = false;
int level = 0;  // 0–4 signal bars for motor strength



U8GLIB_SH1106_128X64 u8g(U8G_I2C_OPT_NONE);

const char* menuItems[] = {"1. Button", "2. Buzzer", "3. LDR", "4. Pot", "5. Ultra", "6. Haptic"};
const int totalItems = 6;

int selectedItem = 0;
bool inMenu = true;
bool inButtonTest = false;
bool inBuzzerTest = false;
bool inLDRTest = false;
bool inPotTest = false; // Added flag for Pot Test mode
bool inUltraTest = false;

void setup() {
  pinMode(BUTTON1_PIN, INPUT);
  pinMode(BUTTON2_PIN, INPUT);
  pinMode(LDR_PIN, INPUT);
  pinMode(BUZZER_PIN, OUTPUT);
  digitalWrite(BUZZER_PIN, LOW);
  pinMode(TRIG_PIN, OUTPUT);
  pinMode(ECHO_PIN, INPUT);

}

void loop() {
  if (inMenu) {
    updateSelection();
    u8g.firstPage();
    do {
      drawMenu();
    } while (u8g.nextPage());

    if (buttonPressedOnce()) {
      if (selectedItem == 0) {
        inMenu = false;
        inButtonTest = true;
      } else if (selectedItem == 1) {
        inMenu = false;
        inBuzzerTest = true;
      } else if (selectedItem == 2) {
        inMenu = false;
        inLDRTest = true;
      } else if (selectedItem == 3) {
        inMenu = false;
        inPotTest = true;
      } else if (selectedItem == 4) {
        inMenu = false;
        inUltraTest = true;
      }
      else if (selectedItem == 5) {  // 6th option (index 5)
        inMenu = false;
        inHapticTest = true;
      }


    }
  }
  else if (inButtonTest) {
    drawButtonTest();
    if (digitalRead(BUTTON1_PIN) == HIGH && digitalRead(BUTTON2_PIN) == HIGH) {
      delay(300);
      while (digitalRead(BUTTON1_PIN) == HIGH || digitalRead(BUTTON2_PIN) == HIGH);
      inMenu = true;
      inButtonTest = false;
    }
  }
  else if (inBuzzerTest) {
    drawBuzzerTest();
    if (digitalRead(BUTTON1_PIN) == HIGH || digitalRead(BUTTON2_PIN) == HIGH) {
      digitalWrite(BUZZER_PIN, HIGH);
    } else {
      digitalWrite(BUZZER_PIN, LOW);
    }
    if (digitalRead(BUTTON1_PIN) == HIGH && digitalRead(BUTTON2_PIN) == HIGH) {
      delay(300);
      while (digitalRead(BUTTON1_PIN) == HIGH || digitalRead(BUTTON2_PIN) == HIGH);
      digitalWrite(BUZZER_PIN, LOW);
      inMenu = true;
      inBuzzerTest = false;
    }
  }
  else if (inLDRTest) {
    drawLDRTest();
    if (digitalRead(BUTTON1_PIN) == HIGH && digitalRead(BUTTON2_PIN) == HIGH) {
      delay(300);
      while (digitalRead(BUTTON1_PIN) == HIGH || digitalRead(BUTTON2_PIN) == HIGH);
      inMenu = true;
      inLDRTest = false;
    }
  }
  else if (inPotTest) {
    drawPotTest();
    if (digitalRead(BUTTON1_PIN) == HIGH && digitalRead(BUTTON2_PIN) == HIGH) {
      delay(300);
      while (digitalRead(BUTTON1_PIN) == HIGH || digitalRead(BUTTON2_PIN) == HIGH);
      inMenu = true;
      inPotTest = false;
    }
  }
  else if (inUltraTest) {
    drawUltraTest();
    if (digitalRead(BUTTON1_PIN) == HIGH && digitalRead(BUTTON2_PIN) == HIGH) {
      delay(300);
      while (digitalRead(BUTTON1_PIN) == HIGH || digitalRead(BUTTON2_PIN) == HIGH);
      inMenu = true;
      inUltraTest = false;
    }
  }

  else if (inHapticTest) {
    drawHapticTest();

    // Increase intensity
    if (digitalRead(BUTTON2_PIN) == HIGH) {
      level++;
      if (level > 4) level = 4;
    }

    // Decrease intensity
    if (digitalRead(BUTTON1_PIN) == HIGH) {
      level--;
      if (level < 0) level = 0;
    }

    // Map level to exact PWM values (avoids noise)
    int pwmValue = 0;
    switch (level) {
      case 0: pwmValue = 0; break;
      case 1: pwmValue = 64; break;
      case 2: pwmValue = 128; break;
      case 3: pwmValue = 192; break;
      case 4: pwmValue = 255; break;
    }
    analogWrite(MOTOR_PIN, pwmValue);

    // Exit condition (both buttons pressed)
    if (digitalRead(BUTTON1_PIN) == HIGH && digitalRead(BUTTON2_PIN) == HIGH) {
      delay(300);
      while (digitalRead(BUTTON1_PIN) == HIGH || digitalRead(BUTTON2_PIN) == HIGH);
      analogWrite(MOTOR_PIN, 0);  // Stop motor
      inMenu = true;
      inHapticTest = false;
    }
  }




  delay(100);
}
  
void updateSelection() {
  int potValue = 1023 - analogRead(POT_PIN);
  int bandSize = 1024 / totalItems;
  selectedItem = potValue / bandSize;
  if (selectedItem >= totalItems) selectedItem = totalItems - 1;
}

void drawMenu() {
  u8g.setFont(u8g_font_6x10);
  u8g.drawStr(0, 8, "Select Component:");
  for (int i = 0; i < totalItems; i++) {
    if (i == selectedItem) {
      u8g.drawStr(0, 18 + i * 9, ">");   // adjusted spacing
    }
    u8g.drawStr(10, 18 + i * 9, menuItems[i]);  // adjusted spacing
  }
}


bool buttonPressedOnce() {
  static bool lastState = LOW;
  bool current = (digitalRead(BUTTON1_PIN) == HIGH || digitalRead(BUTTON2_PIN) == HIGH);

  if (current && !lastState) {
    lastState = true;
    delay(20);
    return true;
  } else if (!current) {
    lastState = false;
  }
  return false;
}

void drawButtonTest() {
  u8g.firstPage();
  do {
    u8g.setFont(u8g_font_6x10);
    u8g.drawStr(20, 10, "Press any Button");

    int x1 = 40, y1 = 40;
    int x2 = 90, y2 = 40;

    if (digitalRead(BUTTON1_PIN) == HIGH)
      u8g.drawDisc(x1, y1, 12);
    else
      u8g.drawDisc(x1, y1, 5);

    if (digitalRead(BUTTON2_PIN) == HIGH)
      u8g.drawDisc(x2, y2, 12);
    else
      u8g.drawDisc(x2, y2, 5);

  } while (u8g.nextPage());
}

void drawBuzzerTest() {
  u8g.firstPage();
  do {
    u8g.setFont(u8g_font_6x10);
    u8g.drawStr(15, 10, "Press any Button");

    u8g.drawTriangle(30, 30, 30, 50, 45, 40);

    if (digitalRead(BUTTON1_PIN) == HIGH || digitalRead(BUTTON2_PIN) == HIGH) {
      digitalWrite(BUZZER_PIN, HIGH);
      u8g.drawCircle(50, 40, 5);
      u8g.drawCircle(55, 40, 8);
      u8g.drawCircle(60, 40, 11);
    } else {
      digitalWrite(BUZZER_PIN, LOW);
      u8g.drawLine(48, 30, 60, 50);
      u8g.drawLine(48, 50, 60, 30);
    }

  } while (u8g.nextPage());
}

void drawLDRTest() {
  int ldrValue = analogRead(LDR_PIN);
  int glowLevel = map(ldrValue, 0, 1023, 0, 10);

  u8g.firstPage();
  do {
    u8g.setFont(u8g_font_6x10);
    u8g.drawStr(35, 10, "LDR Sensor");

    int cx = 64, cy = 50;
    u8g.drawCircle(cx, cy, 8);
    u8g.drawLine(cx, cy + 8, cx, cy + 14);
    u8g.drawLine(cx - 5, cy + 14, cx + 5, cy + 14);

    for (int i = 0; i < glowLevel; i++) {
      int y = cy - 5 - i * 2;
      int w = 4 + i * 2;
      u8g.drawLine(cx - w, y, cx + w, y);
    }

  } while (u8g.nextPage());
}
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

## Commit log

2023-04-18 initial commit for BagTag
    [1048 1.2in 8x8 matrix backpack.step, BagTag-B_Silkscreen.dxf, BagTag-F_Silkscreen.dxf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]
2023-06-06 added v3 files
    [38x38_8x8_LED.step, 8x8_LED_M1088AS.step, BagTag-B_Silkscreen.dxf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]
2023-06-07 updated CAD in /fabricate folder
    [BagTag-B_Cu.gbr, BagTag-B_Mask.gbr, BagTag-B_Silkscreen.gbr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]
2023-06-19 added final v3 assets including Gerbers
    [BagTag-B_Cu.gbr, BagTag-B_Mask.gbr, BagTag-B_Silkscreen.gbr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]
2023-07-14 added BagTag lasercut enclosure DXF
    [BagTag_v3-bottom.dxf, BagTag_v3-laser_case.dxf, BagTag_v3-spacers.dxf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]
2023-07-21 modified DXF outputs after PCB edits
    [BagTag-B_Silkscreen.dxf, BagTag-F_Silkscreen.dxf, BagTag.kicad_pcb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]
2024-05-09 ver 4 WIP - removed prototyping pads, added digital, analog and PWM headers
    [38x38_8x8_LED.step, 8x8_LED_M1088AS.step, BagTag-B_Silkscreen.dxf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]
2024-05-13 ver 4 WIP - gerbers are ready
    [BagTag-B_Silkscreen.dxf, BagTag-F_Silkscreen.dxf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]
2024-09-04 TheThing v1 PCB and Arcade WIP
    [D_DO-41_SOD81_P10.16mm_Horizontal.step, LED_matrix_8x8.step, LED_matrix_8x8_socket.step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]
2024-09-07 TheThing Arcade WIP 2
    [TheThing_v2_tabs.FCStd, TheThing_v2_tabs_export.FCStd, TheThing_v2_tabs_export.dxf]
2024-11-12 arcade enclosure ver3
    [BagTag_v3-bottom.dxf, BagTag_v3-laser_case.dxf, BagTag_v3-spacers.dxf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]
2024-12-13 added hole for reset button
    [38x38_8x8_LED.step, 8x8_LED_M1088AS.step, BagTag-B_Silkscreen.dxf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]
2025-02-07 PCB addon board and new enclosure
    [#TheThing_v3_final.dxf, #TheThing_v3_tabs.dxf, 3352T-1-253LF.step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]
2025-05-09 v7 files for PCB and enclosure
    [#TheThing_v3_final.dxf, #TheThing_v3_tabs.dxf, 1048 1.2in 8x8 matrix backpack.step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]
2025-05-12 v7 prototype files for PCB and enclosure
    [3352T-1-253LF.step, 38x38_8x8_LED.step, 8x8_LED_M1088AS.step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]
2025-05-13 side retaining clips made 0.4mm smaller
    [Disp_OLED_64x64.FCStd, Disp_OLED_64x64_v2.dxf, Disp_OLED_64x64_v3.dxf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]
2025-05-16 fixed default OLED jumper connections
    [TheThing.kicad_pcb, TheThing.kicad_pcb_bom.csv, TheThing.kicad_pcb_positions.csv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]
2025-07-18 modified enclosure v8
    [Potentiometer_Trim_THT.step, TheThing_v7_tabs_export.FCStd, TheThing_v7_tabs_export.dxf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]
2025-10-11 enclosure WIP for v8
    [#TheThing_v8B_tabs_export_fix1-Sketch.dxf, TheThing_v8-trimpot_knob.stl, TheThing_v8-trimpot_knob_fixed.stl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]
2025-10-13 v8 enclosure final
    [#TheThing_v8B_tabs_export_fix1-Sketch.dxf, TheThing_v8B_tabs_export_fix1-Sketch.dxf, TheThing_v8_multiJoin_parts.FCStd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]
2025-10-16 added haptic motor code
    [#TheThing_v8_tabs_export_fix2.dxf, TheThing_v8-Stopper_bat.3mf, TheThing_v8-Stopper_bat.stl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]
2025-10-20 codes WIP
    [TheThing_v8-switch_slidex50nos.3mf, TheThing_v8_multiJoin_parts.FCStd]
2025-10-31 added revised version of pot knob
    [TheThing_v8-trimpot_knob_v2.stl, TheThing_v8.FCStd]
2025-11-04 v8 laser DXF for production
    [HC-SR04 (1).STEP, HC_SR04.FCStd, TheThing_v8-trimpot_knob_v2.stl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]
2026-11-05 Add four user-created Arduino games under UserCreated/
    Games for TheThing Arduino Nano board (SH1106 OLED, pot on A0,
    buttons on D2/D4, buzzer D3, haptic D5):
    - SpaceInvaders: pot moves the ship, buttons fire
    - PixelHop: side-scrolling platformer
    - CryptBlaster: first-person raycasting shooter
    - ReflexRush: call-and-respond reaction game using buttons, pot, LDR and sonar
